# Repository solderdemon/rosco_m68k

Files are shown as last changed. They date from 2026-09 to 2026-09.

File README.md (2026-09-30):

# SolderDemon m68k

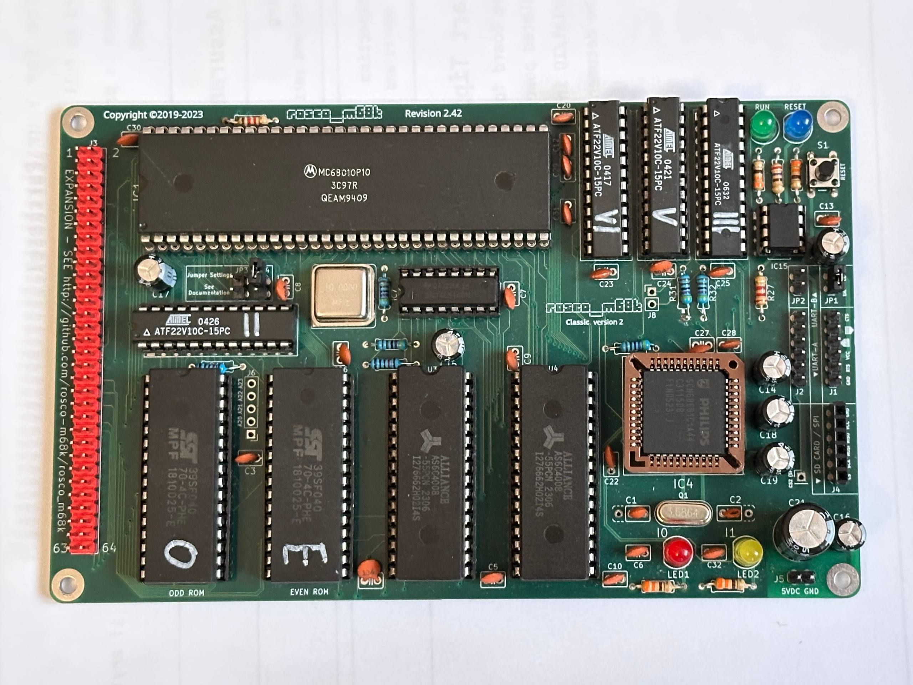
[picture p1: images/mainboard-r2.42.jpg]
Assembled rosco r2.42 mainboard, the GAL version SolderDemon m68k r1 grew from


SolderDemon develops a line of Motorola 68k computers built from **through-hole (THT) parts**. This repository holds its mainboard: the board design, firmware, software and CPLD code. Expansion boards such as the [busboard](https://github.com/solderdemon/solderdemon_m68k-busboard) plug into its J3 expansion connector.

The mainboard is built on [rosco_m68k](https://github.com/rosco-m68k/rosco_m68k) by Ross Bamford, The Really Old-School Company Limited, and contributors. SolderDemon boards carry their own revision numbers, starting at r1; the rosco r2.x numbers are the history they grew from. The photo above is the assembled rosco r2.42 board, the GAL version that r1 grew from.

## The board: r1

r1 is the next release and is not made yet. KiCad renders of it, top and bottom:

<p>
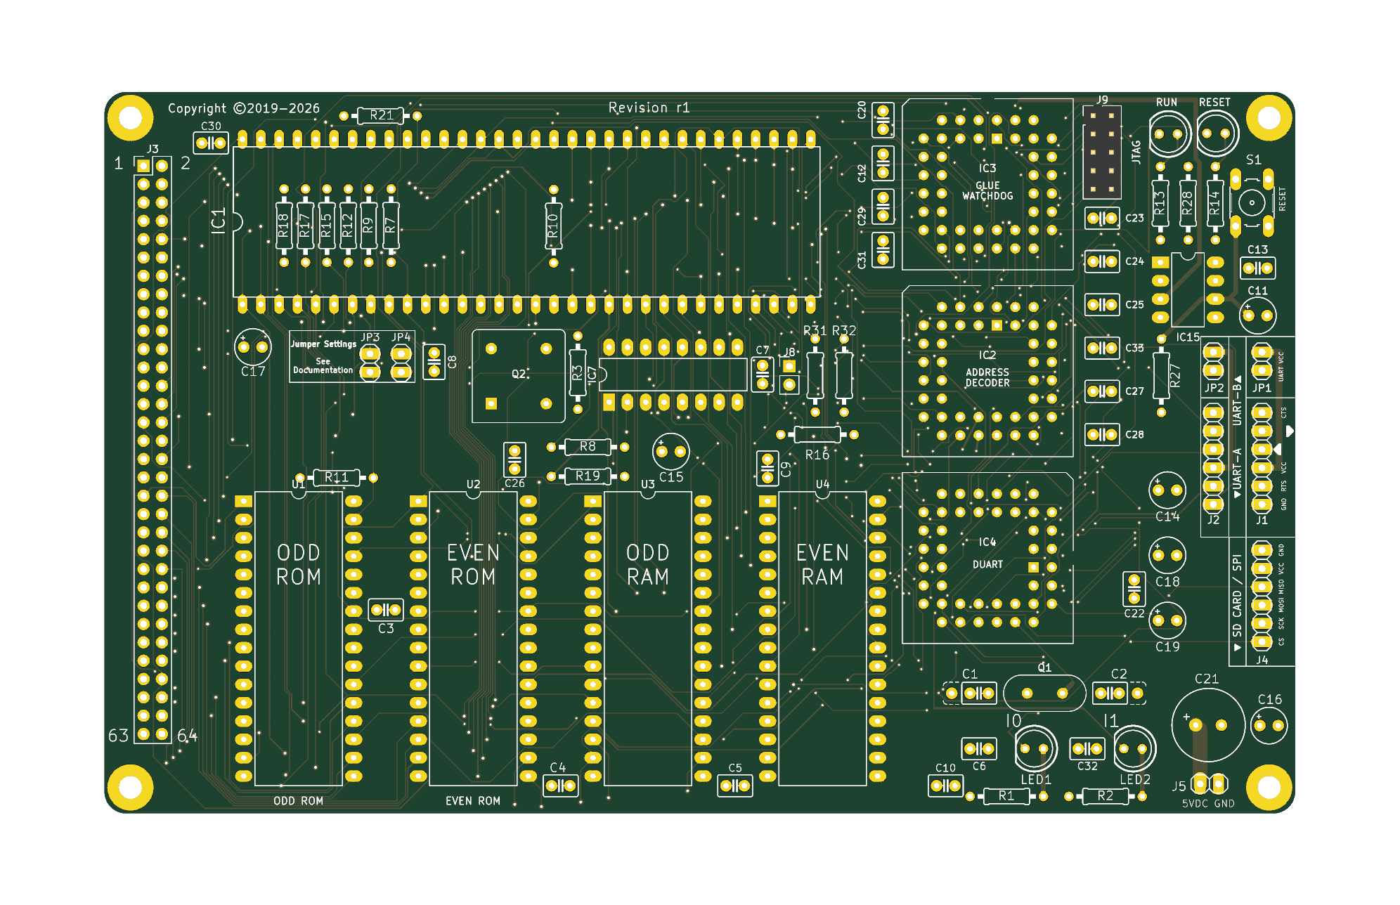
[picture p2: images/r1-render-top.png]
SolderDemon m68k r1, top side, KiCad render
  
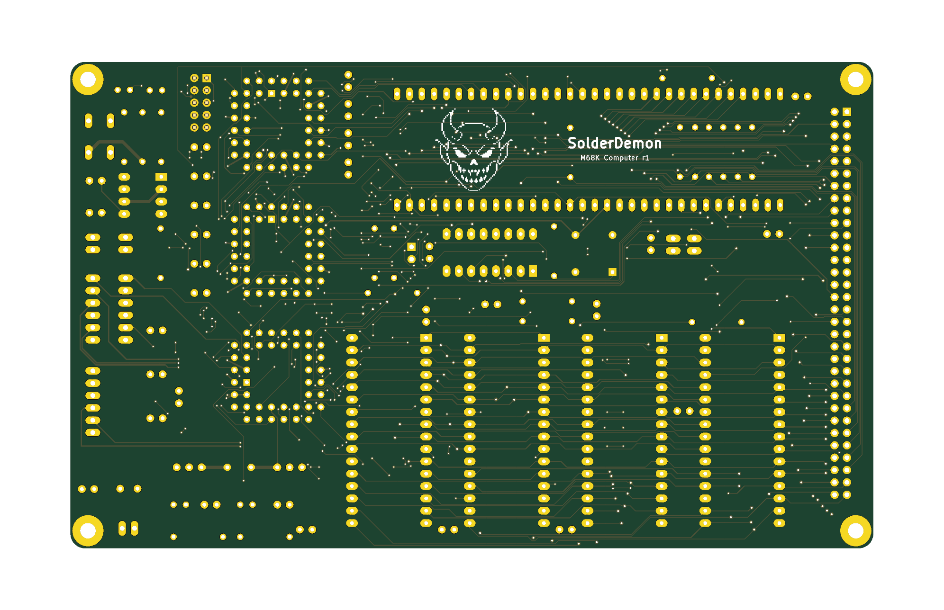
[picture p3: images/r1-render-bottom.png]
SolderDemon m68k r1, bottom side with the SolderDemon identity, KiCad render
  
</p>

| | |
| --- | --- |
| CPU | MC68010, 10 MHz |
| Memory | 1 MB Flash ROM (2 × SST39SF040), 1 MB SRAM (2 × AS6C4008) |
| Glue logic | 2 × ATF1502AS CPLD in PLCC-44 sockets, programmed in circuit over JTAG (J9) |
| I/O | XR68C681 DUART: two UARTs (J1, J2), SD card over SPI (J4) |
| Expansion | 64-pin J3 connector |
| PCB | 165 × 100 mm, 4 layers |

What changed from rosco r2.42 is in the [design notes](design/README.md).

## Find your way around

| What you need | Where to go |
| --- | --- |
| Board design | [design](design/README.md) |
| BOM, jumper settings, memory map, and expansion pinout | [docs](docs/README.md) |
| Firmware and ROM code | [code/firmware](code/firmware/) |
| PLD source and programming | [PLD guide](code/pld/README.md) |
| Software, libraries, and examples | [code/software](code/software/) |
| Recommended software workflow | [rosco CLI and Docker guide](docs/development.md) |
| Emulator for rosco_m68k and rosco_6502 | [SolderDemon rosco-emulator](https://github.com/solderdemon/rosco-emulator) |

## Develop software

For new programs, use [rosco CLI](https://github.com/solderdemon/rosco-cli) with its Docker build workflow. It creates the current starter project, builds through Docker, and can upload and monitor over UART. Follow the [quick start](docs/development.md).

## At the bench

- Start with the [hardware build guide](design/README.md) and [bill of materials](docs/BOM.md).
- Check [power and jumper settings](docs/JUMPERS.md) before applying power, particularly JP1/JP2 for FTDI power and JP3 for Flash writes.
- Use the [J3 expansion header pinout](docs/EXPANSION.md) for peripherals. J3 is the header; JP3 is a different, two-pin jumper.
- For code builds, see the [firmware and software overview](code/README.md). The [older SD card guide](docs/legacy-sd-card.md) covers earlier board revisions and is kept for code users.

<details>
<summary>Photos from the project's early prototypes</summary>

These images show early project prototypes, not the assembled r2.42 board shown above.

Early populated prototype
Early prototype PCBs

</details>

## Licences and attribution

Hardware design: [CERN Open Hardware Licence v1.2](LICENCE.hardware.txt). Software: [MIT](LICENSE) with [third-party notices](licenses/README.md). Documentation: [Creative Commons Attribution 4.0](licenses/LICENSE.docs). Original rosco_m68k design and documentation: Ross Bamford, The Really Old-School Company Limited, and contributors. See [upstream](https://github.com/rosco-m68k/rosco_m68k) for complete history and documentation.

**SolderDemon modification notice (2026-09-30):** SolderDemon m68k adapts the original rosco_m68k project, including a reworked through-hole mainboard (CPLDs instead of GALs, r1 layout and identity), the CPLD logic, and the build documentation. The original authorship and licence notices remain with the source files.

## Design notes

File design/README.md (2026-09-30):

# SolderDemon m68k through-hole mainboard design

Assembled r2.42 mainboard, the GAL version this board grew from

This directory contains the SolderDemon m68k through-hole mainboard design, derived from the original [rosco_m68k](https://github.com/rosco-m68k/rosco_m68k) board. Open the [KiCad project](kicad/solderdemon_m68k.kicad_pro) to inspect the board. The schematics are split into CPU, memory, CPLDs, DUART, reset, and expansion sheets. A [schematic PDF](kicad/solderdemon_m68k.pdf) is included for quick reading.

## Build references

1. Review the [bill of materials](../docs/BOM.md). Its source is the [KiCad CSV export](kicad/solderdemon_m68k.csv); confirm each footprint and package before ordering.
2. Read [jumper and power notes](../docs/JUMPERS.md) before applying power or connecting an SD card.
3. Use the [J3 expansion pinout](../docs/EXPANSION.md) when making an expansion board. **J3** is the expansion connector; **JP3** is the Flash write-enable jumper.
4. Check the KiCad PCB against [CAM outputs](CAMOutputs/) before fabrication. Regenerate Gerbers and drill files after any design change.

## Contents

- **kicad/**: editable schematic sheets, PCB, project, local symbols and footprints, CSV BOM export, and schematic PDF.
- **tools/**: the scripts that turn r2.13 into r1 (below).
- **CAMOutputs/**: Gerber layers and drill files.
- **docs/**: [BOM, jumper notes, and expansion pinout](../docs/README.md).

## r1: SolderDemon numbering, the DUART in the CPLD column

From here on the board carries its own revision numbers, starting at **r1**; the r2.x numbers
below are the rosco_m68k history it grew from.

r1 puts the three PLCC-44 sockets in one column: IC3 (glue), IC2 (decoder) and the DUART IC4
under them. IC4 used to sit 8 mm to the right, and moving it left would have put its pins on the
RAM U4, so the board is 5 mm longer instead (165 × 100 mm). `tools/r1_layout.py` stretches the
r2.42 board along a cut between the CPLDs and the CPU/RAM: everything right of the cut moves 5 mm
right, tracks crossing the cut get a horizontal bridge, so no clearance shrinks. IC4 then moves
into the column, its decoupling cap C22 into the space it left, and the DUART is routed again.
The upstream badges (WEEE bin, OSHW block, rosco_m68k logos, GitHub URL) are gone from the
silkscreen (`tools/strip_silk.py`). The CPU decoupling C20/C12/C29/C31 stands in an even column in the gap the stretch
opened, and the back carries the SolderDemon identity as on the busboard: the logo, the name and
"M68K Computer r1" (`tools/r1_identity.py`). All silkscreen text is in KiCad's own font; the
Futura that r2.x asked for is not installed and made KiCad stop at a message box.

## Revision 2.42: finished CPLD mainboard

r2.42 removes the J6 address/EXPSEL breakout and the J7 SPI CS2 breakout. Their unused copper
branches are pruned and the affected A1/FC2 routes are reconnected. Sixteen narrow VCC bridge
segments are widened from 0.2 to 0.3 mm. The board and all schematic title blocks carry revision
2.42; the crowded UART pin text and obsolete header labels are removed from the silkscreen.

## Revision 2.14: two ATF1502AS instead of four GALs

r2.14 replaces the four ATF22V10C GALs (IC2, IC3, IC5, IC6) with two ATF1502AS-10JU44 CPLDs in
through-hole PLCC-44 sockets, programmed in circuit through the JTAG header **J9**. The logic and
its check are described in [code/pld/cpld](../code/pld/cpld/README.md). Both sockets sit one above
the other where the three glue GALs stood; the old IC2 gap between the CPU and the ROMs is 24.4 mm
and a socket is 24.6 mm. J8, R31, R32 and R16 moved left to make room; the old GAL
decoupling C23-C25 and the DUART's C27/C28 now stand in one column under J9, and C33 is new.

r2.13 was drawn by hand, so r2.42 is an *edit* of it made by scripts, always starting
again from the r2.13 board in git. To rebuild it (KiCad 10, Docker for the fitter):

```sh
K="/c/Program Files/KiCad/10.0/bin"
./code/pld/cpld/build.sh                  # 1. *.pld -> bin/*.jed, pins checked against the source
python design/tools/verify_cpld.py        # 2. CPLDs against the r2.13 GAL fuse maps
python design/tools/cpld_sch.py           # 3. CPLDs sheet of the schematic, from the PIN lines
"$K/python.exe" design/tools/cpld_board.py   # 4. GALs out, sockets/J9/caps in, nets from the schematic
"$K/python.exe" design/tools/cpld_route.py   # 5. routing with KiCadRoutingTools, planes, cleanup
"$K/python.exe" design/tools/remove_access_headers.py # 6. remove J6/J7 and set revision 2.42
"$K/python.exe" design/tools/cpld_route.py --finish     # 7. prune obsolete header branches
"$K/python.exe" design/tools/repair_dangling.py        # 8. remove the remaining old stubs
"$K/python.exe" design/tools/cpld_route.py             # 9. reconnect affected nets
"$K/python.exe" design/tools/repair_dangling.py        # 10. repeat for residual stubs
"$K/python.exe" design/tools/cpld_route.py             # 11. finish the reconnection
"$K/python.exe" design/tools/polish_board.py           # 12. wider VCC bridges, clean silkscreen
"$K/python.exe" design/tools/brand_project.py          # 13. apply SolderDemon m68k project branding
python design/tools/strip_silk.py                      # 14. upstream badges off the silkscreen
"$K/python.exe" design/tools/r1_layout.py              # 15. r1: longer board, DUART into the column
"$K/python.exe" design/tools/cpld_route.py             # 16. route the DUART again
"$K/python.exe" design/tools/trim_stubs.py             # 17. cut router overshoots back to their junctions
python design/tools/make_logo.py 17                    # 18. SolderDemon logo footprint, as on the busboard
"$K/python.exe" design/tools/r1_identity.py            # 19. CPU decoupling column, SolderDemon identity on the back
"$K/python.exe" design/tools/cpld_route.py             # 20. route what the column tore up
"$K/python.exe" design/tools/trim_stubs.py             # 21. and trim again
"$K/kicad-cli.exe" pcb drc --schematic-parity design/kicad/solderdemon_m68k.kicad_pcb
```

Steps 5, 9 and 11 use [KiCadRoutingTools](https://github.com/drandyhaas/KiCadRoutingTools) from the
workspace's `tools/KiCadRoutingTools` (set `KRT` to use another clone); its logs go to
`design/kicad/routing/`. `design/tools/check_board.py` prints the DRC of any board with its
zones refilled.

The hardware design is licensed under [CERN OHL v1.2](../LICENCE.hardware.txt). The documentation is attributed in the [repository README](../README.md).

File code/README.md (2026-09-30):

# SolderDemon m68k firmware and software

This directory contains firmware and software programs for SolderDemon m68k. The
source retains the `rosco_m68k` firmware ABI and upstream build identifiers.

For new programs, start with the [rosco CLI and Docker guide](../docs/development.md). See the README.md files in the subdirectories for details.

| File/directory | Description |
|:---:|---|
| Toolchain.md | Host toolchain instructions for builds without Docker |
| shared | Shared code for both firmware and software |
| firmware | Firmware for the board (ROM code) |
| software | Software (system code & libraries, examples) |
| pld | [PLD sources and programming](pld/README.md) |
| starter_projects | Older starter examples; use rosco CLI init for new projects |

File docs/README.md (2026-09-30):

# SolderDemon m68k documentation

## Through-hole board

- [Parts and quantities](BOM.md): bill of materials from the KiCad CSV export.
- [Jumpers, power, and SD card](JUMPERS.md): JP1 through JP4 and the 5 V SD interface.
- [J3 expansion pinout](EXPANSION.md): 64-pin header signals and electrical notes.
- [Memory map](MEMORY-MAP.md): RAM, expansion, ROM, I/O, and firmware-reserved RAM.
- [Hardware design guide](../design/README.md): KiCad source, schematic PDF, and CAM files.

## Code

- [Recommended rosco CLI and Docker workflow](development.md)
- [Emulator workflow](development.md#emulate-the-board) for the SolderDemon m68k and rosco_6502 targets

- [Firmware and software overview](../code/README.md)
- [Firmware interface reference](../code/firmware/rosco_m68k_firmware/InterfaceReference.md)
- [Toolchain setup](../code/Toolchain.md)
- [PLD source and programming](../code/pld/README.md)
- [Legacy SD card guide](legacy-sd-card.md), written for older board revisions

These board notes are adapted from the original project documents. See the [repository README](../README.md) for attribution and licences.

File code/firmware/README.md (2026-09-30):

# SolderDemon m68k firmware

This directory contains the rosco_m68k firmware used by SolderDemon m68k.
Its source names and firmware interfaces retain the upstream `rosco_m68k` identifiers.

Depending on where we are in the development cycle, the development
firmware may also be present here (with a name like `rosco_m68k_development`).

Old firmware versions and other legacy, unsupported code can be 
found under the `attic` directory. This code is retained for 
historical interest only, and is not guaranteed to work (or even build!).

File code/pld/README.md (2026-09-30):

# PLD firmware

From board revision 2.14 the through-hole mainboard uses two **ATF1502AS-10JU44** CPLDs in PLCC-44
sockets. Their sources, build script and programming notes are in [cpld/](cpld/README.md):

| Board reference | Function | Source | Programming image |
| --- | --- | --- | --- |
| IC2 | Address decoder, DTACK, boot latch | [cpld/ic2_decoder.pld](cpld/ic2_decoder.pld) | `cpld/bin/ic2_decoder.jed` |
| IC3 | DUART select, reset glue, watchdog | [cpld/ic3_glue.pld](cpld/ic3_glue.pld) | `cpld/bin/ic3_glue.jed` |

The CPLDs are programmed in circuit over JTAG (header J9); a TL866/Minipro cannot program them.

## r2.13 and earlier: four ATF22V10C

Boards up to r2.13 use four **ATF22V10C** GALs. Their sources and images stay here, both for those
boards and as the reference `design/tools/verify_cpld.py` checks the CPLDs against:

| Board reference | Function | Source | Programming image |
| --- | --- | --- | --- |
| IC2 | Address decoder | [address_decoder/ic2_address_decoder.pld](address_decoder/ic2_address_decoder.pld) | [ic2_address_decoder.jed](address_decoder/ic2_address_decoder.jed) |
| IC3 | DUART select | [duartsel/ic3_duart_sel.pld](duartsel/ic3_duart_sel.pld) | [ic3_duart_sel.jed](duartsel/ic3_duart_sel.jed) |
| IC5 | Glue logic | [glue/ic5_glue_logic.pld](glue/ic5_glue_logic.pld) | [ic5_glue_logic.jed](glue/ic5_glue_logic.jed) |
| IC6 | Watchdog | [watchdog/ic6_watchdog.pld](watchdog/ic6_watchdog.pld) | [ic6_watchdog.jed](watchdog/ic6_watchdog.jed) |

The .pld files are GALasm sources. The .jed files are the images used by the burn scripts; .chp, .fus, and .pin are accompanying output reports. **A burn script writes its existing .jed file; it does not compile the .pld source.** Regenerate and check the programming image after changing source logic.

Each directory has a burn.sh script that invokes Minipro for an ATF22V10C(UES). Use a compatible programmer, confirm the target IC reference, and run the script **from its own directory** because the image path is relative. For example:

```sh
cd code/pld/address_decoder
bash burn.sh
```

Repeat from the corresponding directory for IC3, IC5, and IC6. The [toolchain notes](../Toolchain.md) include Minipro setup.

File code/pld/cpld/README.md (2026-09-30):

# rosco_m68k classic THT r2.14 glue logic: two ATF1502AS

Board revision 2.14 replaces the four ATF22V10C GALs of r2.13 (IC2 address decoder, IC3 DUART
select, IC5 general glue, IC6 watchdog) with two **ATF1502AS-10JU44** CPLDs in through-hole
PLCC-44 sockets, like the DUART IC4:

| Ref | Source | Does | Replaces |
|---|---|---|---|
| IC2 | [`ic2_decoder.pld`](ic2_decoder.pld) | address decode (RAM/ROM/IO/expansion), DTACK, WR, boot latch, ANYIACK | r2.13 IC2 + the boot counter and ANYIACK of IC5 |
| IC3 | [`ic3_glue.pld`](ic3_glue.pld) | DUART /CS and /IACK, RESET/HALT, RUN LED, bus-error watchdog | r2.13 IC3 + IC6 + the rest of IC5 |

The equations are those of the r2.13 GALs, unchanged, and every board net keeps its name and
level. BOOT and ANYIACK, which ran between the GALs, are internal to IC2 now (ANYIACK is decoded
in IC3 as well, for the watchdog and DUART IACK), so no wire runs between IC2 and IC3. IC2 uses
24 pins and 16 macrocells, IC3 31 pins and 21 macrocells.

## Building

```sh
./build.sh
```

It needs a running Docker: it uses the `dinoboards/cpld-toolchain` image (WinCUPL plus the
Atmel `find1502` fitter, see `tools/cpld-toolchain` in the workspace), writes `bin/*.jed`, and
fails if the fitter moved any pin away from where the `.pld` puts it -- the board is routed to
those pins.

## Checking the logic

```sh
python design/tools/verify_cpld.py [steps] [seed]
```

runs the r2.13 GALs from their real JEDEC fuse maps (`../address_decoder`, `../duartsel`,
`../glue`, `../watchdog`) and the r2.14 CPLDs from these sources side by side on random bus
traffic and fails on the first net that differs -- all 14 driven nets, the open-drain ones
resolved as wired-AND with the CPU pulling RESET/HALT as well. The stimulus makes the boot latch
set and the watchdog fire, and the run fails if either never happens.

## Programming

The ATF1502AS is programmed in circuit over JTAG; the TL866/minipro cannot program it. Header J9
has the Altera/Atmel 10-pin layout (1 TCK, 2 GND, 3 TDO, 4 VCC, 5 TMS, 9 TDI, 10 GND) and the
two chips are chained TDI -> IC2 -> IC3 -> TDO, so IC2 is the first device in the chain. Use an
Atmel ATDH1150USB with ATMISP, or any FT232H/FT2232H adapter with OpenOCD (convert the `.jed` to
SVF first). The board must be powered while programming.

Both designs keep JTAG enabled (`JTAG = ON`) with the internal pull-ups on TDI and TMS. Do not
turn JTAG off: the chip can then only be recovered with a high-voltage programmer.

## Pinout

The `PIN` lines in the `.pld` files are the only place the pinout is written down;
`design/tools/cpld_sch.py` and `cpld_board.py` read them. They were chosen by
`cpld_board.py --suggest`, which puts each signal on the pin nearest to where its net already
runs on the board. To move a pin: edit the `.pld`, run `./build.sh`, `verify_cpld.py`, then
`cpld_sch.py`, `cpld_board.py` and `cpld_route.py` (see [design/README.md](../../../design/README.md)).

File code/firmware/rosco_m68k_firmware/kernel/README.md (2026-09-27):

## ROM kernel for rosco_m68k

The test target builds `units.bin` with the host cross-toolchain and runs it
in the [SolderDemon rosco-emulator](https://github.com/solderdemon/rosco-emulator)
Docker image. Keep Docker running; the test checks that the suite reports
`0 failed`. You can also upload the binary to a board if desired.

```shell
make clean test
```

The kernel itself is built as part of the main ROM build, but you
can build just the static library in this directory if you want:

```shell
make clean all
```

You can change the defines in the Makefile to see more debugging info:

* `-DDEBUG_PMM` - See memory manager debugging output (noisy)
* `-DDEBUG_SCHED` - See scheduler debugging output (noisy)
    * `-DTRACE_SCHED` - See scheduler trace output (very noisy)
* `-DEEBUG_INTEN` - Debug interrupt enable / disable (extremely noisy)

### Memory Management

Obviously with no MMU there is no virtual memory, and no memory protection.
The kernel implements two interfaces for memory managament - an optimised
low-overhead free-list based coalescing first-fit physical allocator with 
a block size of 1KiB, and a simple bitmap-based slab allocator layered
on top, which automatically manages 1KiB slabs, with a fixed block size
of 32-bytes.

The slab allocator is primarily intended for system structures, and does
support allocation/free of multiple contiguous blocks from a given slab
where a struct needs more than 32-bytes.

The intention is that user code would directly use neither of these - 
instead, the physical allocator would supply blocks that would then be
managed by some library `malloc` implementation. 

They are both exposed via the `IKernel` API, however, so can be used.

In order for everything to work nicely, all memory management must 
(ultimately) go through the pmm, or the system won't be able to track
what memory is in use vs not, and sadness will most likely ensue.

### Scheduling

The scheduler here is a pre-emptive, priority-based round robin, with four
priority levels (0 = lowest, 3 = highest).

The scheduler is run once per quantum, driven from the 100Hz system timer,
so it'll run 100 times per second, adjusted by the divisor in the 
`QUANTUM_TICKS` variable in `task.asm`. We'll want to play around with
this to find a value that works well in the general case (and can make 
it configurable if we like). 

In testing so far the scheduler is quite capable of 100 switches a second,
without swamping the system - however, it might not be best for performance,
we might want to take a (small) hit on latency to trade off for raw perf.

Obviously once interrupt sources and devices are implemented, that'll also 
change the complexion of that tradeoff - so we can revisit regularly 
as dev progresses.

The priority rules are:

* A runnable process of a given priority will only be given time if no 
  higher-priority process is runnable
* A newly-scheduled process will **never** preempt the scheduling process
* A newly-scheduled process will **always** be scheduled next, _within_
  _it's priority group_
* Where a newly-scheduled process has the same priority, or higher priority
  than the scheduling process, it will **always** run on the next schedule
* A sleeping process, when woken, will **always** preempt the running 
  process _on the next timeslice_, _if it has the same or higher priority_.

### Initialisation

To initialize the kernel, you'll need to call a few things. This is the 
recommended order for doing so:

```c
    /* Initialise the API pointers */
    api_init();
    Kernel = get_kernel_api();

    /* Initialise the PMM. The free should be changed to cover your chosen managed memory region */
    pmm_init();
    pmm_free(0x20000, 0x30000);
    
    /* Initalise the slab allocator */
    slab_init();
    
    /* Initialise IRQs */
    irq_init();

    /* Initialise the multitasking system */
    task_init();

    /* Start the multitasking system. This never returns */
    start_tasking(tinit_stack, SYS_STACK_SIZE, init, tidle_stack, SYS_STACK_SIZE, idle);
```

To set up tasks, the following general pattern is recommended:

```c
    Task* t1 = (Task*)Kernel->alloc_sys_object(TASK_SLAB_BLOCKS);
    uint32_t t1_stack = Kernel->mem_alloc(USER_STACK_SIZE);    

    if (t1 == NULL || t1_stack == 0) {
        syncprintf("  ==! Failed to allocate memory for task\n");
        halt_and_catch_fire();
    }

    Kernel->task_init(t1, 0x01, TASK_1_PRIORITY);
```

This would later be scheduled (e.g. by your `init` task):

```c
    Kernel->task_schedule(t1, t1_stack, USER_STACK_SIZE, task1_function);
```

### Kernel API

All access to the Kernel API should be done through an `IKernel` pointer,
which can be obtained with the `get_kernel_api` function in `kernelapi.h`.

This provides the following functions. Take note of those marked as 
"not interrupt safe" - these **must** not be called from interrupt context!

You can find (a bit) more detail about the functions in the respective 
header files (under `include`).

#### Physical Memory Management
* `Kernel->mem_alloc(uintptr_t size)` - Allocate 1KiB "pages" to cover `size` bytes
* `Kernel->mem_free(uintptr_t addr, uintptr_t size)` - Free 1KiB "pages" to cover `size` bytes

#### Slab Memory Management

* `Kernel->alloc_sys_object(uint8_t block_count)` - Allocate up to 31 blocks (32bytes each)
* `Kernel->free_sys_object(void* addr, uint8_t block_count)` - Free slabs starting at at `addr`

#### Multitasking

* `Kernel->task_current()` - Obtain a pointer to the currently-running `Task*`
* `Kernel->task_init(Task *task, tid_t tid, priority_t priority)` - Initialise a new task struct
  * This **must** be called on new `Task*` structs before they are used!
  * If allocating task structs, be aware they need two slab blocks!
* `Kernel->task_schedule(Task *task, uintptr_t stack_addr, size_t stack_size, task_handler_f entrypoint)` - Schedule a task to run (next, within its priority level)
* `Kernel->task_wait(uint32_t sig_mask)` - Suspend the current task until another task sends one of the specified signals
  * **Not interrupt safe**
  * Currently, does not unblock if the task is _already_ signalled - this is prone to race conditions and will likely be changed
* `Kernel->task_signal(Task *task, uint32_t sig_mask)` - Signal the given task with the specified signals
  * Does **not** immediately wake the task - it is just scheduled next _within it's priority level_.
  * For this reason, high-priority signalling (e.g. for interrupt handling) should be done in high-priority tasks

#### Interrupt Handling

* `Kernel->enable_interrupts()` - Enable interrupts
  * This is re-entrant, a counter of disables is kept, and only when this is zero are interrupts actually enabled
* `Kernel->disable_interrupts()` - Disable interrupts
  * This is re-entrant, a counter of disables is kept, and used by `enable_interrupts`
* `Kernel->register_irq(uint8_t vec, IrqHandler *handler)` - Register an IRQ chain handler for the given vector
* `Kernel->remove_irq(IrqHandler *handler)` - Remove the specified IRQ chain handler

#### Utilities

Despite being quite strict about being a microkernel, the API _does_ include some utility functions where the
Kernel can usefully export efficient functions for working with kernel structures. 

These may also be useful in your own code.

* `Kernel->list_init(List* the_list)` - Initialize a kernel doubly-linked list
* `Kernel->list_add_head(List* target, ListNode *subject)` - Add the specified node at the head of the list
* `Kernel->list_delete_head(List* target)` - Delete (and return) the head node from the list
* `Kernel->list_add_tail(List* target, ListNode *subject)` - Add the specified node at the tail of the list
* `Kernel->list_delete_tail(List* target)` - Delete (and return) the head node from the list
* `Kernel->list_insert_after(ListNode *target, ListNode *subject)` - Insert the specified subject node after the specified target node
* `Kernel->list_delete(ListNode *subject)` - Delete the specified node from the list that contains it

### Legal Mumbo-Jumbo

**Copyright 2023 Ross Bamford & Contributors**
MIT License

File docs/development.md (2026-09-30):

# Develop SolderDemon m68k software with rosco CLI

[rosco CLI](https://github.com/solderdemon/rosco-cli) is the recommended way to create, build, upload, and monitor SolderDemon m68k programs. It keeps the build and serial workflow in one command-line tool. Select its compatible `rosco_m68k` board target in the commands below.

## Start a new project

Install rosco CLI using the instructions in its [README](https://github.com/solderdemon/rosco-cli#install-from-this-checkout), then create a new C project:

```sh
rosco init hello --board rosco_m68k --language c --docker --target hardware --yes
cd hello
rosco doctor
rosco build
```

Use `--language asm` for an assembly project. The CLI creates the current starter files itself, so there is no need to copy this repository's older `code/starter_projects` directories into a new project.

The generated project records Docker as its build toolchain. Docker must be installed and running. On ARM hosts, the [CLI documentation](https://github.com/solderdemon/rosco-cli#configuration) describes setting `build.docker.platform = "linux/amd64"` if the image requires emulation.

## Run on the board

Connect the USB serial adapter and run:

```sh
rosco run
```

`rosco run` automatically selects the USB-UART port when there is one matching device. It builds, uploads through Kermit, and monitors UART output. If discovery cannot choose a port, run `rosco ports` to list USB-UART candidates (or `rosco ports --all` for other serial ports), then pass the correct port explicitly with `rosco run --port <port>`. See the [CLI README](https://github.com/solderdemon/rosco-cli#typical-workflow) for separate build, upload, and monitor commands.

## Emulate the board

The separate [SolderDemon rosco-emulator](https://github.com/solderdemon/rosco-emulator) supports both rosco_m68k and rosco_6502. rosco CLI can create a project that runs in the emulator through Docker:

```sh
rosco init hello --board rosco_m68k --language c --docker --target emulator --emulator-docker --yes
cd hello
rosco run
```

For a rosco_6502 project, choose `--board rosco_6502`. The emulator also has its own [Docker image and usage instructions](https://github.com/solderdemon/rosco-emulator#docker).

## Existing projects and host builds

From an existing compatible software project, `rosco build --docker` selects the Docker toolchain for that run. The older [host toolchain instructions](../code/Toolchain.md) remain available if you deliberately build without Docker. The older [starter projects](../code/starter_projects/README.md) are retained as examples; use `rosco init` for a fresh project.

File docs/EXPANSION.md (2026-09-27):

# J3 expansion header pinout

> This pinout describes the **J3 expansion connector**. Check the schematic before using it with another board revision. **JP3 is a separate Flash write-enable jumper**, not this connector.

J3 provides peripheral access to the full address, data and control buses in the system,
plus VCC (5V) and GND. These signals are unbuffered and have no built-in protection, so are
not suitable for direct use as a bus, but could be made so with a relatively simple
expansion-to-bus conversion board.

Many of the MC68010 lines are tri-state when used in conjunction with the bus-mastering support.

It should be noted that most of these signals have very low output current capabilities,
and should not be used to directly drive e.g. LEDs. If LEDs are to be driven, then either
a transistor must be used, or the circuit set up such that the pins sink current.

In all cases, see the datasheets for the relevant IC driving a given line (including the MC68010, XR68C681, and GAL devices, depending on the signal) for the absolute maximum ratings.

The absolute maximum current draw on the VCC line is 1A. Recommended maximum is 500mA.
The board _may_ be able to supply more than this, but as power supplies are so variable
you should take care if drawing more than this from this pin. A better solution should
you need might be to separately power your peripheral from the supply and share common ground.

| Pin | Signal | Description | Active | I/O |
|-----|---|---|---|-----|
| 1 | A1 | MC68010 Address line 1 | High | O |
| 2 | VCC | +5V (500mA recommended max) | N/A | O |
| 3 | A2 | MC68010 Address line 2 | High | O |
| 4 | CLK | Main system clock (10MHz, 50% duty cycle) | N/A | O |
| 5 | A3 | MC68010 Address line 3 | High | O |
| 6 | GND | Ground | N/A | O |
| 7 | A4 | MC68010 Address line 4 | High | O |
| 8 | VPA | MC68010 Legacy peripheral VPA (*5)(6*) | Low | I |
| 9 | A5 | MC68010 Address line 5 | High | O |
| 10  | E | MC68010 Legacy peripheral E (*5) | Low | O |
| 11  | A6 | MC68010 Address line 6 | High | O |
| 12  | VMA | MC68010 Legacy peripheral VMA (*5) | Low | O |
| 13  | A7 | MC68010 Address line 7 | High | O |
| 14  | IRQ3 | IRQ3 line (*3) | Low | I |
| 15  | A8 | MC68010 Address line 8 | High | O |
| 16  | IOS | IOSEL line from decoder (*1) | Low | O |
| 17  | A9 | MC68010 Address line 9 | High | O |
| 18  | EXPS | EXPSEL line from decoder (*1) | Low | O |
| 19  | A10 | MC68010 Address line 10 | High | O |
| 20  | FC0 | MC68010 Function Code 0 (*2) | High | O |
| 21  | A11 | MC68010 Address line 11 | High | O |
| 22  | FC1 | MC68010 Function Code 1 (*2) | High | O |
| 23  | A12 | MC68010 Address line 12 | High | O |
| 24  | FC2 | MC68010 Function Code 2 (*2) | High | O |
| 25  | A13 | MC68010 Address line 13 | High | O |
| 26  | IPL0 | IRQ5 line (*3) | Low | I |
| 27  | A14 | MC68010 Address line 14 | High | O |
| 28  | IPL1 | IRQ2 Line (*3) | Low | I |
| 29  | A15 | MC68010 Address line 15 | High | O |
| 30  | IPL2 | IRQ6 Line (*3) | Low | I |
| 31  | A16 | MC68010 Address line 16 | High | O |
| 32  | LDS | MC68010 Lower Data Strobe | Low | O |
| 33  | A17 | MC68010 Address line 17 | High | O |
| 34  | UDS | MC68010 Upper Data Strobe | Low | O |
| 35  | A18 | MC68010 Address line 18 | High | O |
| 36  | RESET  | System Reset (4*) | Low | I/O |
| 37  | A19 | MC68010 Address line 19 | High | O |
| 38  | D15 | MC68010 Data line 15 | High | I/O |
| 39  | A20 | MC68010 Address line 20 | High | O |
| 40  | D14 | MC68010 Data line 14 | High | I/O |
| 41  | A21 | MC68010 Address line 21 | High | O |
| 42  | D13 | MC68010 Data line 13 | High | I/O |
| 43  | A22 | MC68010 Address line 22 | High | O |
| 44  | D12 | MC68010 Data line 12 | High | I/O |
| 45  | A23 | MC68010 Address line 23 | High | O |
| 46  | D11 | MC68010 Data line 11 | High | I/O |
| 47  | AS | MC68010 Address Strobe | Low | O |
| 48  | D10 | MC68010 Data line 10 | High | I/O |
| 49  | BERR | MC68010 Bus Error | Low | I |
| 50  | D9 | MC68010 Data line 9 | High | I/O |
| 51  | BG | MC68010 Bus Grant | Low | O |
| 52  | D8 | MC68010 Data line 8 | High | I/O |
| 53  | BGACK  | MC68010 Bus Grant Acknowledge | Low | I |
| 54  | D7 | MC68010 Data line 7 | High | I/O |
| 55  | BR | MC68010 Bus Request | Low | I |
| 56  | D6 | MC68010 Data line 6 | High | I/O |
| 57  | DTACK  | MC68010 Data Transfer Acknowledge | Low | I |
| 58  | D5 | MC68010 Data line 5 | High | I/O |
| 59  | R/W | MC68010 Read/Not Write | N/A | O |
| 60  | D4 | MC68010 Data line 4 | High | I/O |
| 61  | D0 | MC68010 Data line 0 | High | I/O |
| 62  | D3 | MC68010 Data line 3 | High | I/O |
| 63  | D1 | MC68010 Data line 1 | High | I/O |
| 64  | D2 | MC68010 Data line 2 | High | I/O |

 ## Signal notes

 1. If used to drive LEDs, the circuit should be configured such that these pins sink current.
 2. If all three function code pins are high the CPU is asserting IACK.
 3. Active low, open-collector IRQ lines for peripherals (4K7 pullups included, do not add more).
 4. Wire-or, open-collector. Pullup is already provided.
 5. See MC68010 user manual. Using these lines alters bus cycle timing.
 6. This line has a built-in 10k pull-up.

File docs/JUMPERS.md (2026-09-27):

# Jumpers, power, and SD card

These notes are adapted from the original *Classic v2 Additional Information* sheet for the through-hole mainboard. Confirm jumper positions against the [schematic](../design/kicad/rosco_m68k.pdf) and board silkscreen before applying power.

| Jumper | Closed | Normal use |
| --- | --- | --- |
| JP1 / JP2 | Allows power from the corresponding FTDI serial module | Leave both open when using the board's external power input. Close **only one** when deliberately powering through an FTDI module. |
| JP3 | Enables hardware writing to the Flash ROMs | Leave open unless running a Flash update. |
| JP4 | Changes expansion RAM behaviour for the original rosco_m68k memory expansion board | Leave open for other configurations. |

## Power through FTDI

Never close JP1 and JP2 together. Do not connect external power while either FTDI power jumper is closed. The original R2 notice states the mainboard alone requires **at least 500 mA**; check that the host and FTDI module can supply the complete build.

## SD card header

The SPI SD card header uses **5 V** signals. Use an Arduino-compatible SD card adapter with built-in **5 V to 3.3 V level conversion**. Do not connect a bare 3.3 V SD card directly.

## Expansion power

The J3 expansion connector exposes 5 V and ground. The original [J3 pinout](EXPANSION.md) recommends drawing no more than **500 mA** from its 5 V pin, with **1 A** stated as an absolute maximum. Account for the complete board's power supply and use a shared ground if powering a peripheral separately.

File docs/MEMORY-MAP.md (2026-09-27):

# Memory map

This is the physical 24-bit address map of the through-hole mainboard after startup. The [address decoder PLD](../code/pld/address_decoder/ic2_address_decoder.pld) defines the board-level regions; the [firmware linker script](../code/firmware/rosco_m68k_firmware/rosco_m68k_firmware_1M.ld) and [program linker script](../code/software/libs/src/start_serial/link_scripts/hugerom_rosco_m68k_program.ld) use the same boundaries.

| Address range | Size | Use |
| --- | ---: | --- |
| `0x000000`–`0x0FFFFF` | 1 MiB | Onboard RAM |
| `0x100000`–`0xDFFFFF` | 13 MiB | Expansion address space; memory or devices depend on the attached hardware |
| `0xE00000`–`0xEFFFFF` | 1 MiB | Onboard ROM / Flash |
| `0xF00000`–`0xFFFFFF` | 1 MiB | I/O address space |

At reset, the address decoder temporarily selects ROM at low addresses so the CPU can fetch its initial vectors. After the startup cycles, RAM occupies `0x000000`–`0x0FFFFF`. The ROM image and firmware revision word are linked at `0xE00000` and `0xE00400` respectively. The DUART is addressed at odd byte addresses starting at `0xF00001`; see the [firmware register definitions](../code/firmware/rosco_m68k_firmware/include/machine.h). The I/O region is a decode window, not a promise that every address in it has a device.

## Low RAM used by firmware

The firmware reserves the first `0x2000` bytes for vectors and system data. The ranges below come from the [firmware interface reference](../code/firmware/rosco_m68k_firmware/InterfaceReference.md#2-system-data-area-memory-map).

| Address range | Use |
| --- | --- |
| `0x000000`–`0x0003FF` | Exception vectors |
| `0x000400`–`0x00041F` | System Data Block (SDB), including RAM size and UART base |
| `0x000420`–`0x0004FF` | Firmware function pointer table |
| `0x000500`–`0x00117F` | Video I/O data area |
| `0x001180`–`0x0017FF` | Firmware internal reserved area |
| `0x001800`–`0x001FFF` | Firmware BSS |

The standard program linker script begins its run area at `0x002000`. It also uses `0x040000` as a load address, so use the linker script for a program's actual layout instead of treating all higher RAM as free. For individual SDB fields and firmware calls, use the [full interface reference](../code/firmware/rosco_m68k_firmware/InterfaceReference.md).

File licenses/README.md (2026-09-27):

# Licences and attribution

The main software licence is [MIT](../LICENSE). Hardware design files use the [CERN Open Hardware Licence v1.2](../LICENCE.hardware.txt). Repository documentation uses [Creative Commons Attribution 4.0](LICENSE.docs).

The retained third-party notices are grouped here:

| Notice | Included material |
| --- | --- |
| [COPYING.NEWLIB](COPYING.NEWLIB) | Newlib-derived components and related code |
| [LICENCE.adventure](LICENCE.adventure) | Adventure port under code/software/adventure |
| [LICENSE.kermit](LICENSE.kermit) | Embedded Kermit code |
| [LICENSE.shmall](LICENSE.shmall) | Shmall allocator code |

Keep these notices with the corresponding source when redistributing it. The Musashi notice was removed with the bundled r68k emulator source.

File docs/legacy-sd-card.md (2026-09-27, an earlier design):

# Legacy SD card hookup and user guide

> This guide describes firmware 1.3 and earlier board revisions (R1/R1.2/R1.23). For Classic R2 electrical notes, see [R2 jumpers and SD card](JUMPERS.md).

With Firmware 1.3, SD Cards are now supported directly by the firmware. This feature works will all boards that are supported by Firmware 1.3, though the electrical hookup and usage varies.

In order to use SD card, you will need an Arduino SD Card adapter. It is very important that this adapter includes level conversion (as SD cards are 3.3V) - any adapter marked as suitable for Arduino _should_ work, but for completeness ensure it has the regulator and level-conversion chip (as in the diagram below).

## Electrical connection

To connect your SD adapter to your rosco_m68k, you will use some of the GPIO pins (on `J5`) for r1 and r1.2 boards, or the dedicated SD card connector (`J4`) on r1.23 boards. The hookup is as shown below:

SD Card Hookup

The SD adapter should be connected with the rosco_m68k powered off. Ensure all connections are correct before connecting power to the mainboard. Once the adapter is connected, you can insert and remove SD cards without needing to power off or reboot your rosco_m68k.

## Supported SD cards

Most SD cards will work fine in a read-only system, however for best performance and reliability (especially during writes) we recommend good quality SDHC cards with capacity 16 or 32GB. The interface has been fairly extensively tested with SanDisk, Samsung, and similar brands in SDHC capacity.

## SD Card format

In order to work with the standard rosco_m68k software (both the firmware bootloader, where available, and Xark's [sdfat_menu](../code/software/sdfat_menu)) your SD card should be formatted as FAT. You can do this on a desktop computer - specifics vary by platform.

FAT32 is recommended (and more completely tested). VFAT is known to be unsupported at this time.

### sdfat_menu

Xark's [sdfat_menu](../code/software/sdfat_menu) is the official loader for SD cards, and is the recommended way to interface with your SD card. Whether by direct booting with `BIGROM`s (see below) or by sending the menu program via Kermit before using SD features, the menu provides a comprehensive text interface for selecting binaries to load and run, and also provides a command-shell, directory navigation, and more.

### Bootable SD

If you have the `BIGROM` build of Firmware 1.3, your rosco_m68k will look for an SD card at boot time (before falling back to Kermit). If one is found, it will attempt to load a file called `ROSCODE1.BIN` from the SD card and boot it directly.

It is recommended that, where this capability exists, you use Xark's [sdfat_menu](../code/software/sdfat_menu) (see above).

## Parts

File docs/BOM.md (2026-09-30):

# SolderDemon m68k bill of materials

This table is transcribed from the KiCad CSV export at [solderdemon_m68k.csv](../design/kicad/solderdemon_m68k.csv). It has **30 part lines and 82 component placements**. It is a design BOM, not a verified purchasing list; check the schematic, PCB footprints, and desired assembly options before ordering.

| Qty | References | Value / part | KiCad footprint |
| ---: | --- | --- | --- |
| 1 | S1 | 10-XX | B3F-10XX |
| 2 | R19,R11 | 10K | 0207_10 |
| 2 | C1,C2 | 7pF | C2.5_or_3.5-3 |
| 23 | C7,C8,C9,C20,C23,C24,C22,C26,C13,C27,C28,C30,C31,C6,C25,C29,C12,C10,C5,C4,C3,C32,C33 | 100nF | C2.5-3 |
| 7 | C16,C17,C18,C19,C14,C15,C11 | 100uF | E2,5-5 |
| 1 | C21 | 470uF | E3,5-10 |
| 1 | IC4 | XR68C681CJTR-F | PLCC-44_THT-Socket |
| 2 | IC3,IC2 | ATF1502AS-10JU44 | PLCC-44_THT-Socket |
| 4 | JP1,JP2,JP3,JP4 | Jumper | 1X02 |
| 2 | LED3,LED1 | GREEN | LED5MM |
| 2 | LED4,LED2 | RED | LED5MM |
| 1 | Q1 | 3.6864MHz | Crystal_HC49-4H_Vertical |
| 1 | Q2 | 5H8ET-10.000 | Oscillator_DIP-8 |
| 2 | U4,U3 | AS6C4008-55PCN | DIP-32_W15.24mm_LongPads |
| 2 | U2,U1 | SST39SF040 | DIP-32_W15.24mm_LongPads |
| 1 | J3 | Conn_02x32_Odd_Even | PinHeader_2x32_P2.54mm_Vertical |
| 12 | R8,R7,R9,R10,R32,R31,R12,R15,R17,R18,R3,R16 | 4K7 | 0207_10 |
| 1 | J4 | Conn_01x06 | 1X06 |
| 1 | J2 | UART_B | 1X06 |
| 1 | J1 | UART_A | 1X06 |
| 1 | J5 | PWR | 1X02 |
| 1 | IC15 | 555N | DIP-8_W7.62mm_LongPads |
| 1 | R27 | 2K2 | 0207_10 |
| 1 | R28 | 270R | 0207_10 |
| 4 | R13,R14,R1,R2 | 330R | 0207_10 |
| 1 | R21 | 1K2 | 0207_10 |
| 1 | IC7 | 74LS148 | DIP-16_W7.62mm_LongPads |
| 1 | J8 | Conn_01x02_Male | PinHeader_1x02_P2.54mm_Vertical |
| 1 | IC1 | MC68010P10 | DIL64 |
| 1 | J9 | JTAG (2x5 header) | PinHeader_2x05_P2.54mm_Vertical |

## Items outside the component count

- The CSV also contains **four M3 mounting holes** and **six logo or compliance artwork objects**. They are PCB features, not parts to buy.
- The bare PCB and any required programming of the ATF1502AS CPLDs (in circuit, over JTAG header J9) and Flash ROMs are not included as BOM lines. See the [PLD programming guide](../code/pld/README.md) for IC2 and IC3. Boards up to r2.13 use four ATF22V10C GALs (IC2, IC3, IC5, IC6) instead.
- The original R2 packing list separately mentioned sockets for IC1 (DIL64, 1), IC4 (PLCC44, 1), IC7 (DIL16, 1), IC15 (DIL08, 1), and U1/U2/U3/U4 (DIL32, 4). From r2.14 IC2 and IC3 also sit in PLCC-44 through-hole sockets (2 more PLCC44 sockets). Treat these as assembly choices and verify fit against the PCB.
- The older packing list differs from this KiCad CSV for some headers (including J8). This table follows the CSV; inspect the current PCB before ordering those headers.

The source CSV has no supplier or manufacturer part numbers. Package names in this table are KiCad footprint identifiers, not vendor order codes.

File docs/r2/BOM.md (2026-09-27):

# R2 bill of materials

This table is transcribed from the KiCad CSV export at [kicad/rosco_m68k.csv](../../design/r2/kicad/rosco_m68k.csv). It has **31 part lines and 84 component placements**. It is a design BOM, not a verified purchasing list; check the schematic, PCB footprints, and desired assembly options before ordering.

| Qty | References | Value / part | KiCad footprint |
| ---: | --- | --- | --- |
| 1 | S1 | 10-XX | B3F-10XX |
| 2 | R19,R11 | 10K | 0207_10 |
| 2 | C1,C2 | 7pF | C2.5_or_3.5-3 |
| 22 | C7,C8,C9,C20,C23,C24,C22,C26,C13,C27,C28,C30,C31,C6,C25,C29,C12,C10,C5,C4,C3,C32 | 100nF | C2.5-3 |
| 7 | C16,C17,C18,C19,C14,C15,C11 | 100uF | E2,5-5 |
| 1 | C21 | 470uF | E3,5-10 |
| 1 | IC4 | XR68C681CJTR-F | PLCC-44_THT-Socket |
| 4 | IC5,IC6,IC3,IC2 | ATF22V10C | DIP-24_W7.62mm_Socket_LongPads |
| 4 | JP1,JP2,JP3,JP4 | Jumper | 1X02 |
| 2 | LED3,LED1 | GREEN | LED5MM |
| 2 | LED4,LED2 | RED | LED5MM |
| 1 | Q1 | 3.6864MHz | Crystal_HC49-4H_Vertical |
| 1 | Q2 | 5H8ET-10.000 | Oscillator_DIP-8 |
| 2 | U4,U3 | AS6C4008-55PCN | DIP-32_W15.24mm_LongPads |
| 2 | U2,U1 | SST39SF040 | DIP-32_W15.24mm_LongPads |
| 1 | J3 | Conn_02x32_Odd_Even | PinHeader_2x32_P2.54mm_Vertical |
| 12 | R8,R7,R9,R10,R32,R31,R12,R15,R17,R18,R3,R16 | 4K7 | 0207_10 |
| 1 | J4 | Conn_01x06 | 1X06 |
| 1 | J2 | UART_B | 1X06 |
| 1 | J1 | UART_A | 1X06 |
| 1 | J5 | PWR | 1X02 |
| 1 | IC15 | 555N | DIP-8_W7.62mm_LongPads |
| 1 | R27 | 2K2 | 0207_10 |
| 1 | R28 | 270R | 0207_10 |
| 4 | R13,R14,R1,R2 | 330R | 0207_10 |
| 1 | R21 | 1K2 | 0207_10 |
| 1 | J6 | Conn_01x05_Male | PinHeader_1x05_P2.54mm_Vertical |
| 1 | J7 | Conn_01x01_Male | PinHeader_1x01_P2.54mm_Vertical |
| 1 | IC7 | 74LS148 | DIP-16_W7.62mm_LongPads |
| 1 | J8 | Conn_01x02_Male | PinHeader_1x02_P2.54mm_Vertical |
| 1 | IC1 | MC68010P10 | DIL64 |

## Items outside the component count

- The CSV also contains **four M3 mounting holes** and **six logo or compliance artwork objects**. They are PCB features, not parts to buy.
- The bare PCB and any required programming of the ATF22V10C GALs and Flash ROMs are not included as BOM lines. See the [PLD programming guide](../../code/pld/README.md) for IC2, IC3, IC5, and IC6.
- The original R2 packing list separately mentioned sockets for IC1 (DIL64, 1), IC2/IC3/IC5/IC6 (DIL24, 4), IC4 (PLCC44, 1), IC7 (DIL16, 1), IC15 (DIL08, 1), and U1/U2/U3/U4 (DIL32, 4). Treat these as assembly choices and verify fit against the PCB.
- The older packing list differs from this KiCad CSV for some headers (including J6 and J8). This table follows the CSV; inspect the current PCB before ordering those headers.

The source CSV has no supplier or manufacturer part numbers. Package names in this table are KiCad footprint identifiers, not vendor order codes.

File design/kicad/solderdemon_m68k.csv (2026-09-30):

Id | Designator | Package | Quantity | Designation | Supplier and ref
1 | H1,H2,H4,H3 | MountingHole_3.2mm_M3_Pad | 4 | MountingHole
2 | S1 | B3F-10XX | 1 | 10-XX
3 | R19,R11 | 0207_10 | 2 | 10K
4 | C1,C2 | C2.5_or_3.5-3 | 2 | 7pF
5 | C7,C8,C9,C20,C23,C24,C22,C26,C13,C27,C28,C30,C31,C6,C25,C29,C12,C10,C5,C4,C3,C32,C33 | C2.5-3 | 23 | 100nF
6 | C16,C17,C18,C19,C14,C15,C11 | E2,5-5 | 7 | 100uF
7 | C21 | E3,5-10 | 1 | 470uF
8 | IC4 | PLCC-44_THT-Socket | 1 | XR68C681CJTR-F
9 | IC3,IC2 | PLCC-44_THT-Socket | 2 | ATF1502AS-10JU44
10 | JP1,JP2,JP3,JP4 | 1X02 | 4 | Jumper
11 | LED3,LED1 | LED5MM | 2 | GREEN
12 | LED4,LED2 | LED5MM | 2 | RED
13 | Q1 | Crystal_HC49-4H_Vertical | 1 | 3.6864MHz
14 | Q2 | Oscillator_DIP-8 | 1 | 5H8ET-10.000
15 | U4,U3 | DIP-32_W15.24mm_LongPads | 2 | AS6C4008-55PCN
16 | U2,U1 | DIP-32_W15.24mm_LongPads | 2 | SST39SF040
17 | J3 | PinHeader_2x32_P2.54mm_Vertical | 1 | Conn_02x32_Odd_Even
18 | R8,R7,R9,R10,R32,R31,R12,R15,R17,R18,R3,R16 | 0207_10 | 12 | 4K7
19 | J4 | 1X06 | 1 | Conn_01x06
20 | J2 | 1X06 | 1 | UART_B
21 | J1 | 1X06 | 1 | UART_A
22 | J5 | 1X02 | 1 | PWR
23 | IC15 | DIP-8_W7.62mm_LongPads | 1 | 555N
24 | R27 | 0207_10 | 1 | 2K2
25 | R28 | 0207_10 | 1 | 270R
26 | R13,R14,R1,R2 | 0207_10 | 4 | 330R
27 | R21 | 0207_10 | 1 | 1K2
28 | REF**,REF** | SM-rosco_m68k_logo | 2 | SM-rosco_m68k_logo
29 | IC7 | DIP-16_W7.62mm_LongPads | 1 | 74LS148
30 | J8 | PinHeader_1x02_P2.54mm_Vertical | 1 | Conn_01x02_Male
31 | IC1 | DIL64 | 1 | MC68010P10
32 | OSHW_Mono_0.25_Scale | OSHW_Mono_0.25_Scale | 1 | UK000006
33 | REF** | RoHS-Logo_6mm_SilkScreen | 1 | RoHS-Logo_6mm_SilkScreen
34 | REF** | WEEE-Logo_5.6x8mm_SilkScreen | 1 | WEEE-Logo_5.6x8mm_SilkScreen
35 | REF** | MD-rosco_m68k_logo | 1 | MD-rosco_m68k_logo
36 | J9 | PinHeader_2x05_P2.54mm_Vertical | 1 | JTAG

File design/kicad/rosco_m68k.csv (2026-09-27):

Id | Designator | Package | Quantity | Designation | Supplier and ref
1 | H1,H2,H4,H3 | MountingHole_3.2mm_M3_Pad | 4 | MountingHole
2 | S1 | B3F-10XX | 1 | 10-XX
3 | R19,R11 | 0207_10 | 2 | 10K
4 | C1,C2 | C2.5_or_3.5-3 | 2 | 7pF
5 | C7,C8,C9,C20,C23,C24,C22,C26,C13,C27,C28,C30,C31,C6,C25,C29,C12,C10,C5,C4,C3,C32 | C2.5-3 | 22 | 100nF
6 | C16,C17,C18,C19,C14,C15,C11 | E2,5-5 | 7 | 100uF
7 | C21 | E3,5-10 | 1 | 470uF
8 | IC4 | PLCC-44_THT-Socket | 1 | XR68C681CJTR-F
9 | IC5,IC6,IC3,IC2 | DIP-24_W7.62mm_Socket_LongPads | 4 | ATF22V10C
10 | JP1,JP2,JP3,JP4 | 1X02 | 4 | Jumper
11 | LED3,LED1 | LED5MM | 2 | GREEN
12 | LED4,LED2 | LED5MM | 2 | RED
13 | Q1 | Crystal_HC49-4H_Vertical | 1 | 3.6864MHz
14 | Q2 | Oscillator_DIP-8 | 1 | 5H8ET-10.000
15 | U4,U3 | DIP-32_W15.24mm_LongPads | 2 | AS6C4008-55PCN
16 | U2,U1 | DIP-32_W15.24mm_LongPads | 2 | SST39SF040
17 | J3 | PinHeader_2x32_P2.54mm_Vertical | 1 | Conn_02x32_Odd_Even
18 | R8,R7,R9,R10,R32,R31,R12,R15,R17,R18,R3,R16 | 0207_10 | 12 | 4K7
19 | J4 | 1X06 | 1 | Conn_01x06
20 | J2 | 1X06 | 1 | UART_B
21 | J1 | 1X06 | 1 | UART_A
22 | J5 | 1X02 | 1 | PWR
23 | IC15 | DIP-8_W7.62mm_LongPads | 1 | 555N
24 | R27 | 0207_10 | 1 | 2K2
25 | R28 | 0207_10 | 1 | 270R
26 | R13,R14,R1,R2 | 0207_10 | 4 | 330R
27 | R21 | 0207_10 | 1 | 1K2
28 | J6 | PinHeader_1x05_P2.54mm_Vertical | 1 | Conn_01x05_Male
29 | REF**,REF** | SM-rosco_m68k_logo | 2 | SM-rosco_m68k_logo
30 | J7 | PinHeader_1x01_P2.54mm_Vertical | 1 | Conn_01x01_Male
31 | IC7 | DIP-16_W7.62mm_LongPads | 1 | 74LS148
32 | J8 | PinHeader_1x02_P2.54mm_Vertical | 1 | Conn_01x02_Male
33 | IC1 | DIL64 | 1 | MC68010P10
34 | OSHW_Mono_0.25_Scale | OSHW_Mono_0.25_Scale | 1 | UK000006
35 | REF** | RoHS-Logo_6mm_SilkScreen | 1 | RoHS-Logo_6mm_SilkScreen
36 | REF** | WEEE-Logo_5.6x8mm_SilkScreen | 1 | WEEE-Logo_5.6x8mm_SilkScreen
37 | REF** | MD-rosco_m68k_logo | 1 | MD-rosco_m68k_logo

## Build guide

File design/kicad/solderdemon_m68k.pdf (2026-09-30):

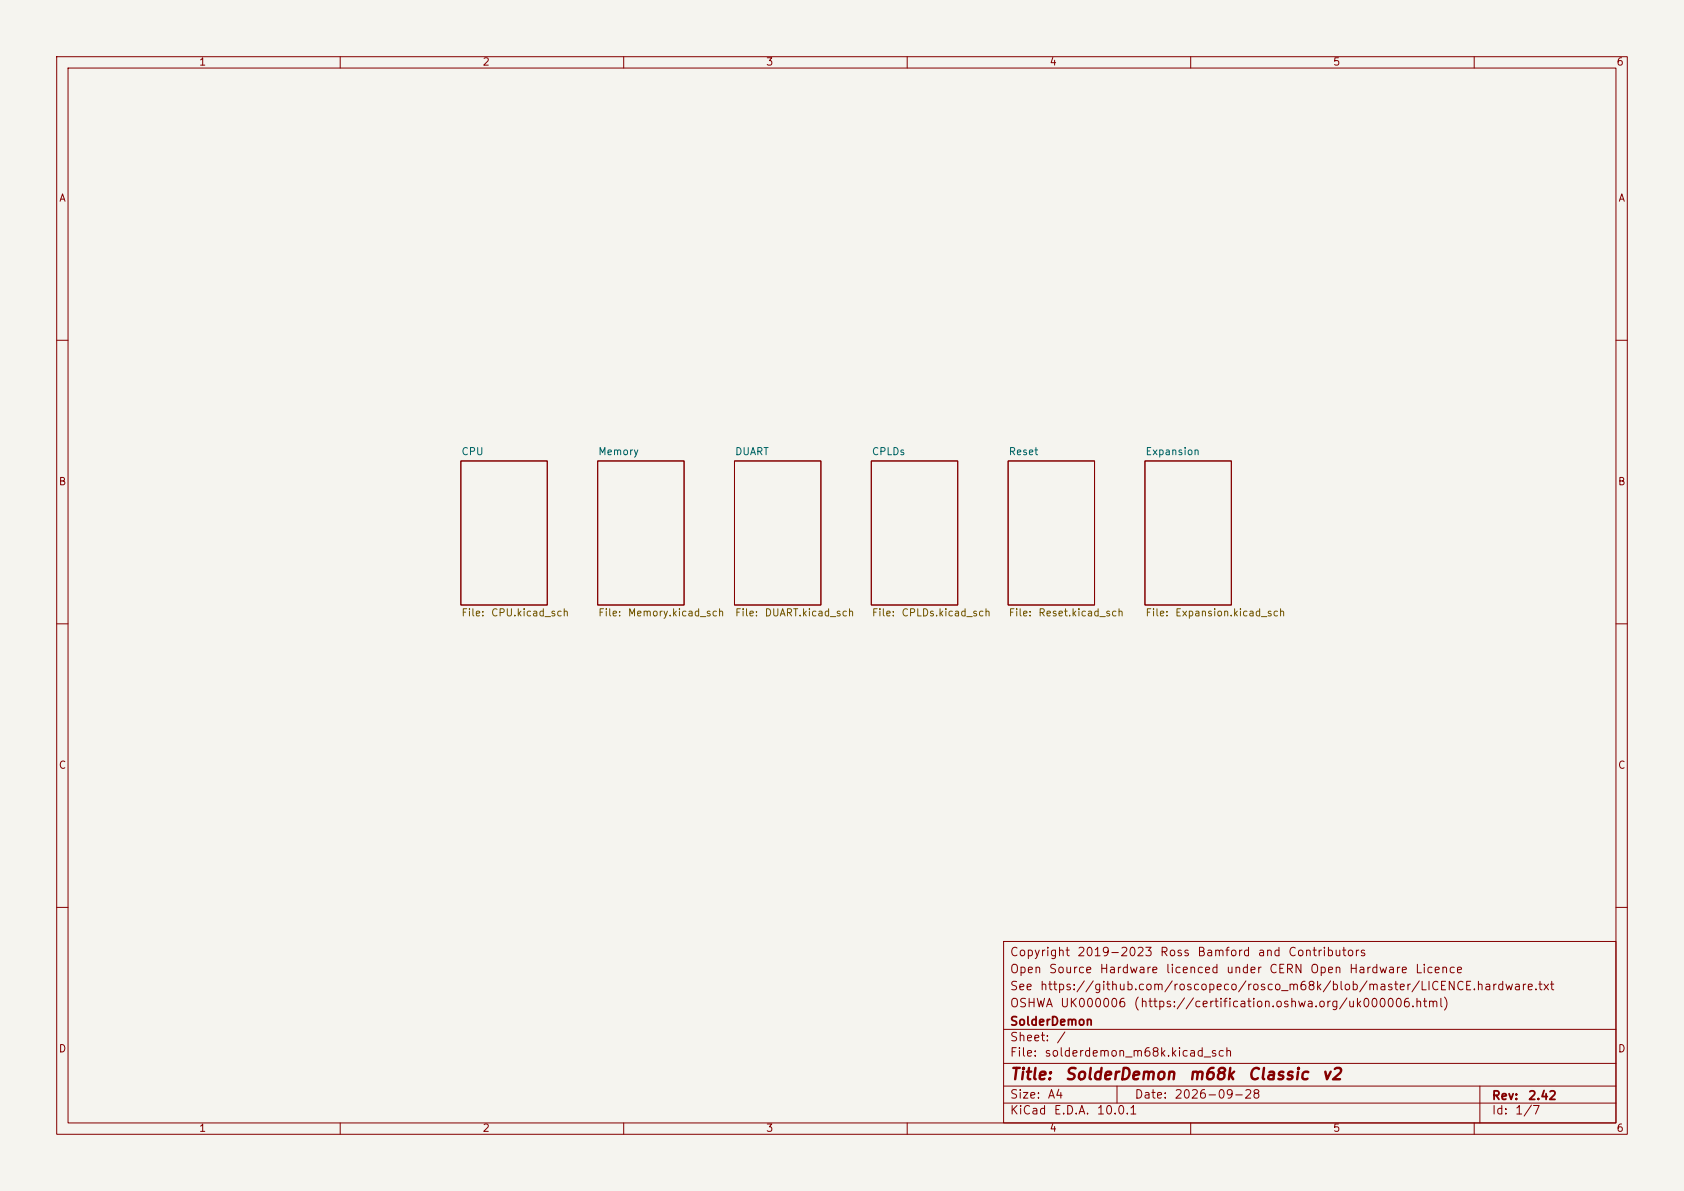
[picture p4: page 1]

Copyright 2019-2023 Ross Bamford and Contributors
Open Source Hardware licenced under CERN Open Hardware Licence
See https://github.com/roscopeco/rosco_m68k/blob/master/LICENCE.hardware.txt
OSHWA UK000006 (https://certification.oshwa.org/uk000006.html)
SolderDemon
Sheet: /
File: solderdemon_m68k.kicad_sch
Title: SolderDemon m68k Classic v2

Size: A4 | Rev: 2.42
KiCad E.D.A. 10.0.1 | Id: 1/7

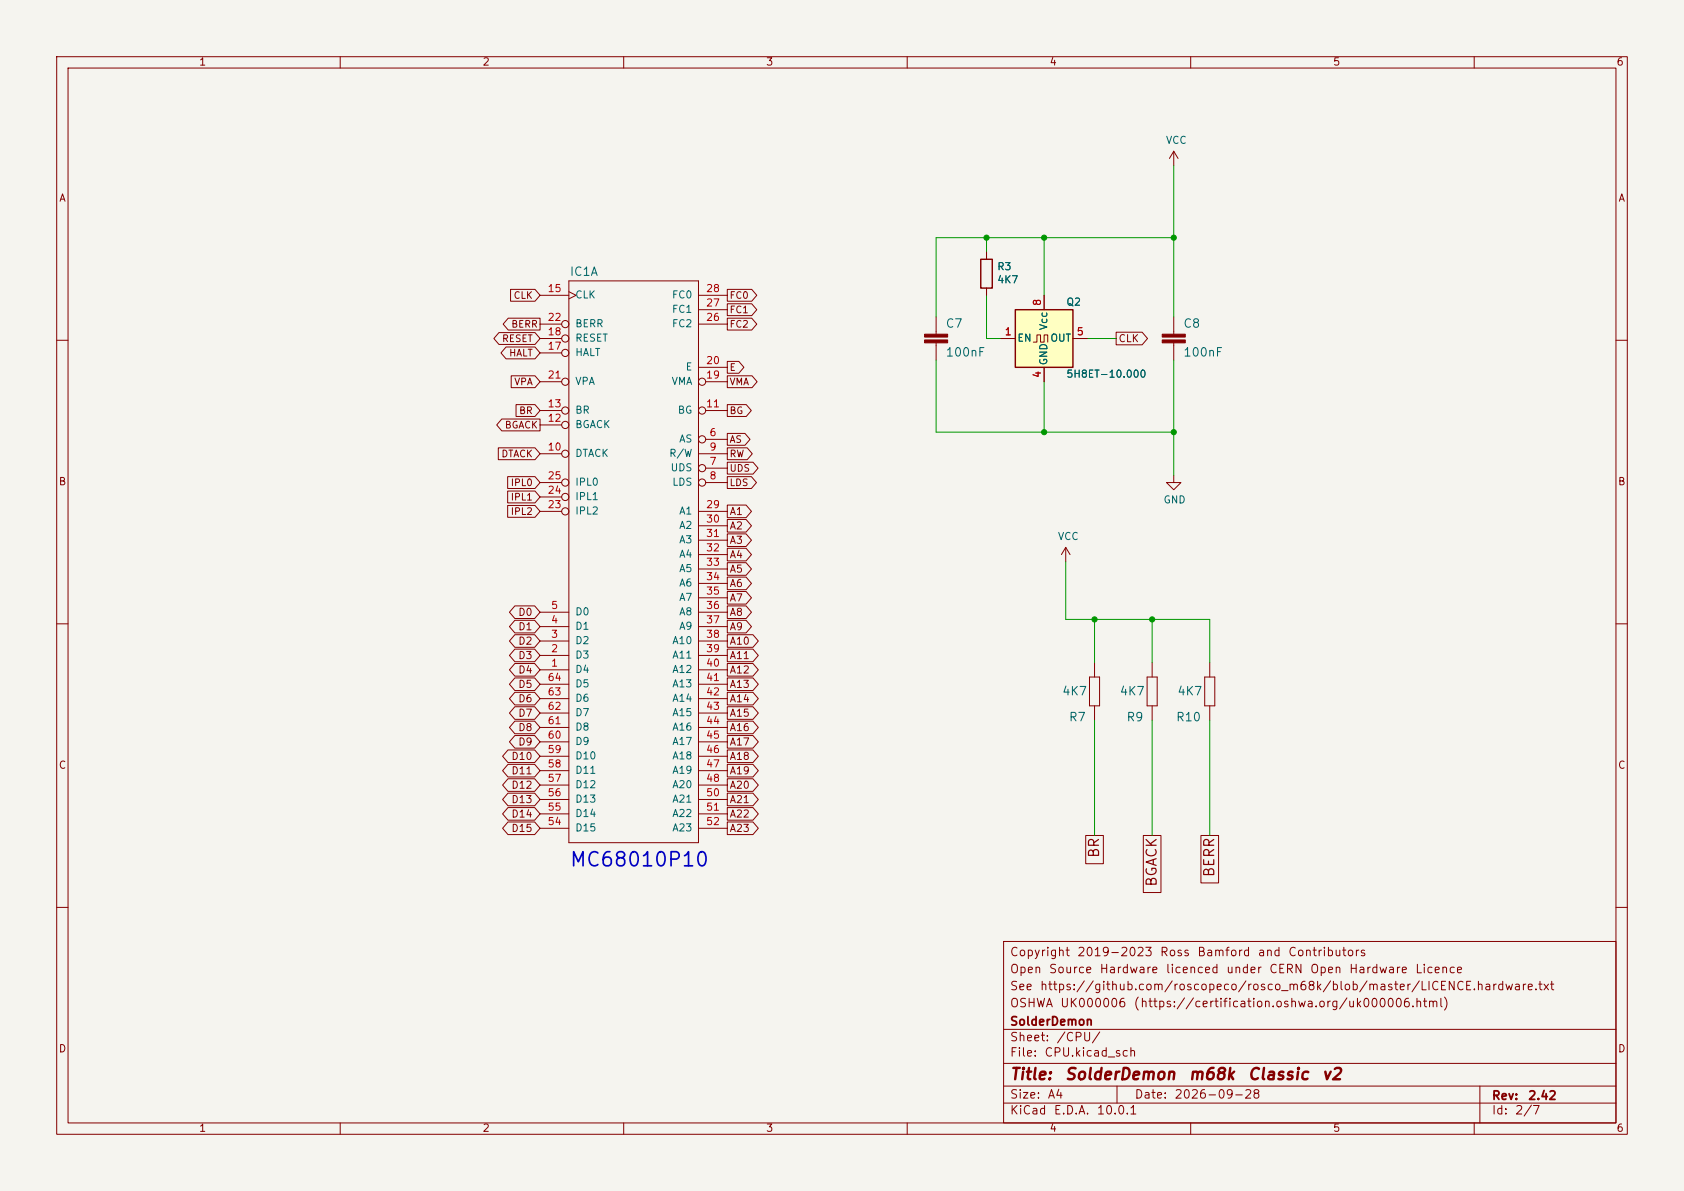
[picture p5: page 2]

Copyright 2019-2023 Ross Bamford and Contributors
Open Source Hardware licenced under CERN Open Hardware Licence
See https://github.com/roscopeco/rosco_m68k/blob/master/LICENCE.hardware.txt
OSHWA UK000006 (https://certification.oshwa.org/uk000006.html)
SolderDemon
Sheet: /CPU/
File: CPU.kicad_sch
Title: SolderDemon m68k Classic v2

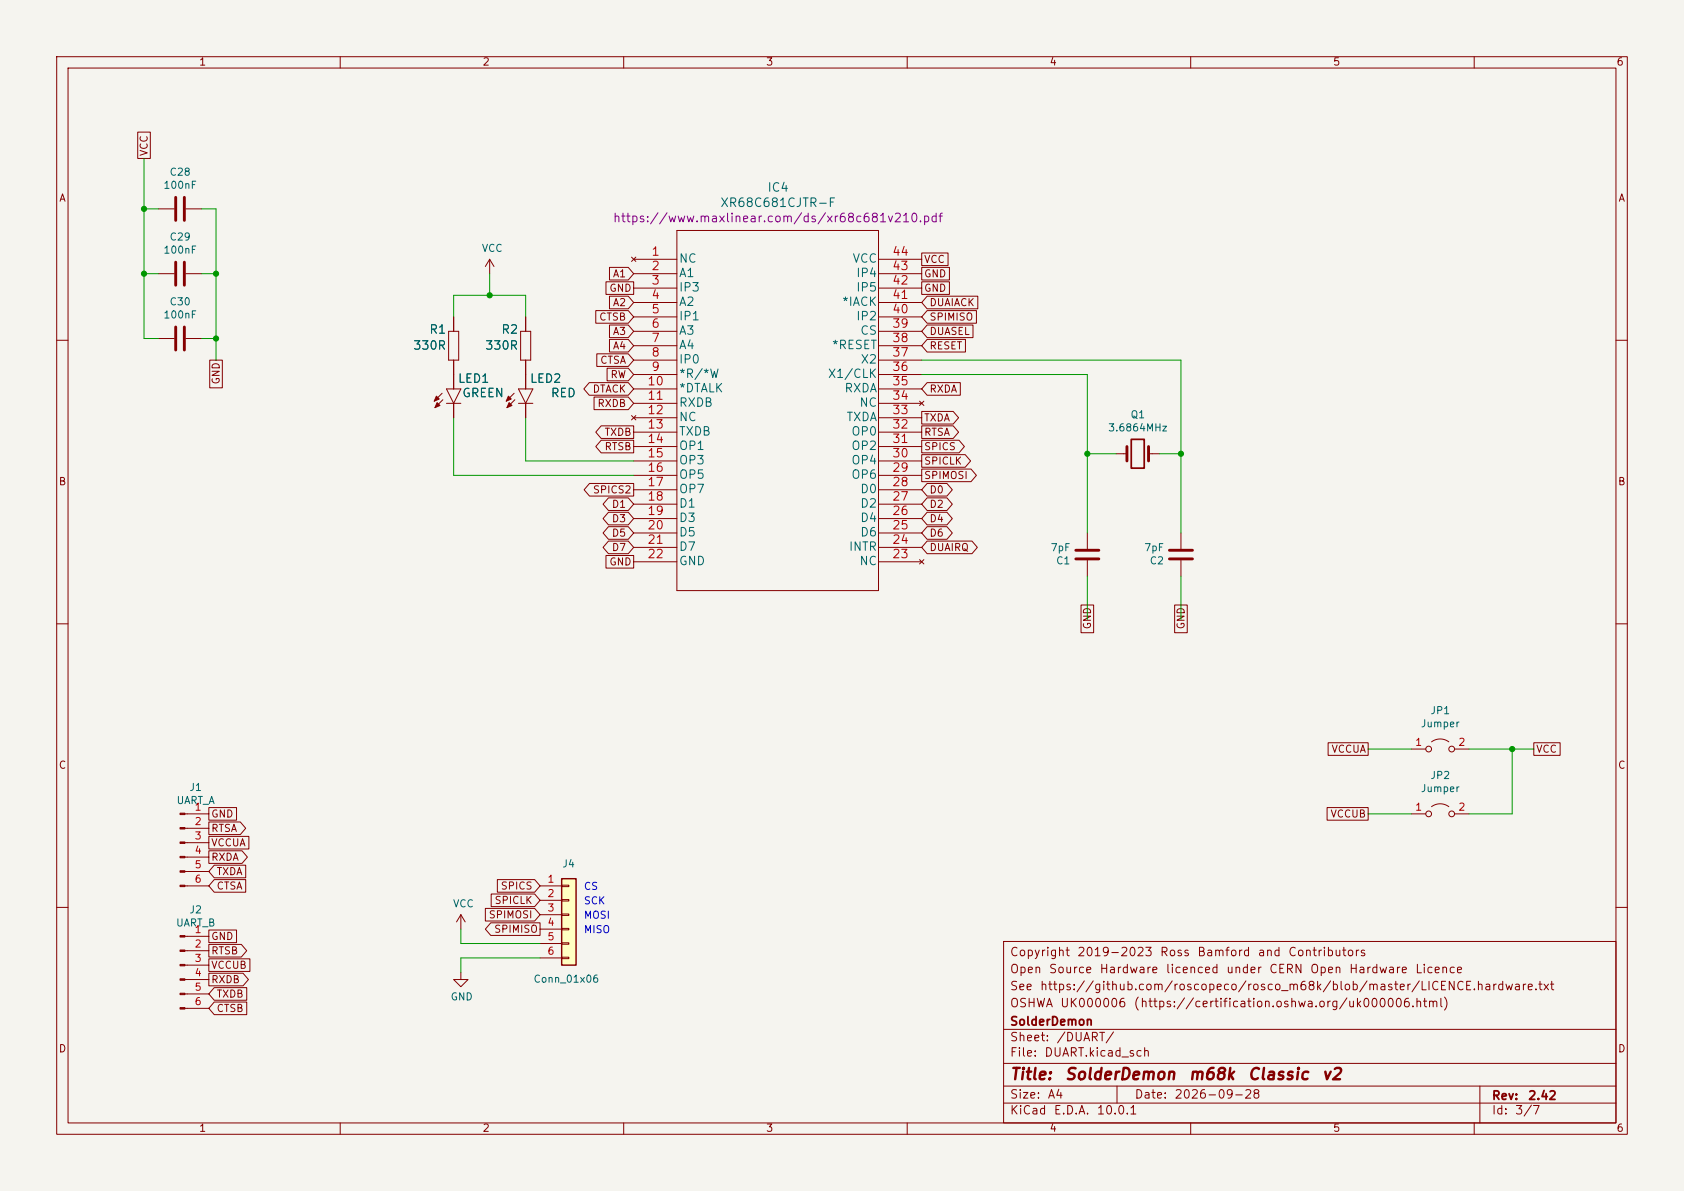
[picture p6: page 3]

Copyright 2019-2023 Ross Bamford and Contributors
Open Source Hardware licenced under CERN Open Hardware Licence
See https://github.com/roscopeco/rosco_m68k/blob/master/LICENCE.hardware.txt
OSHWA UK000006 (https://certification.oshwa.org/uk000006.html)
SolderDemon
Sheet: /DUART/
File: DUART.kicad_sch
Title: SolderDemon m68k Classic v2

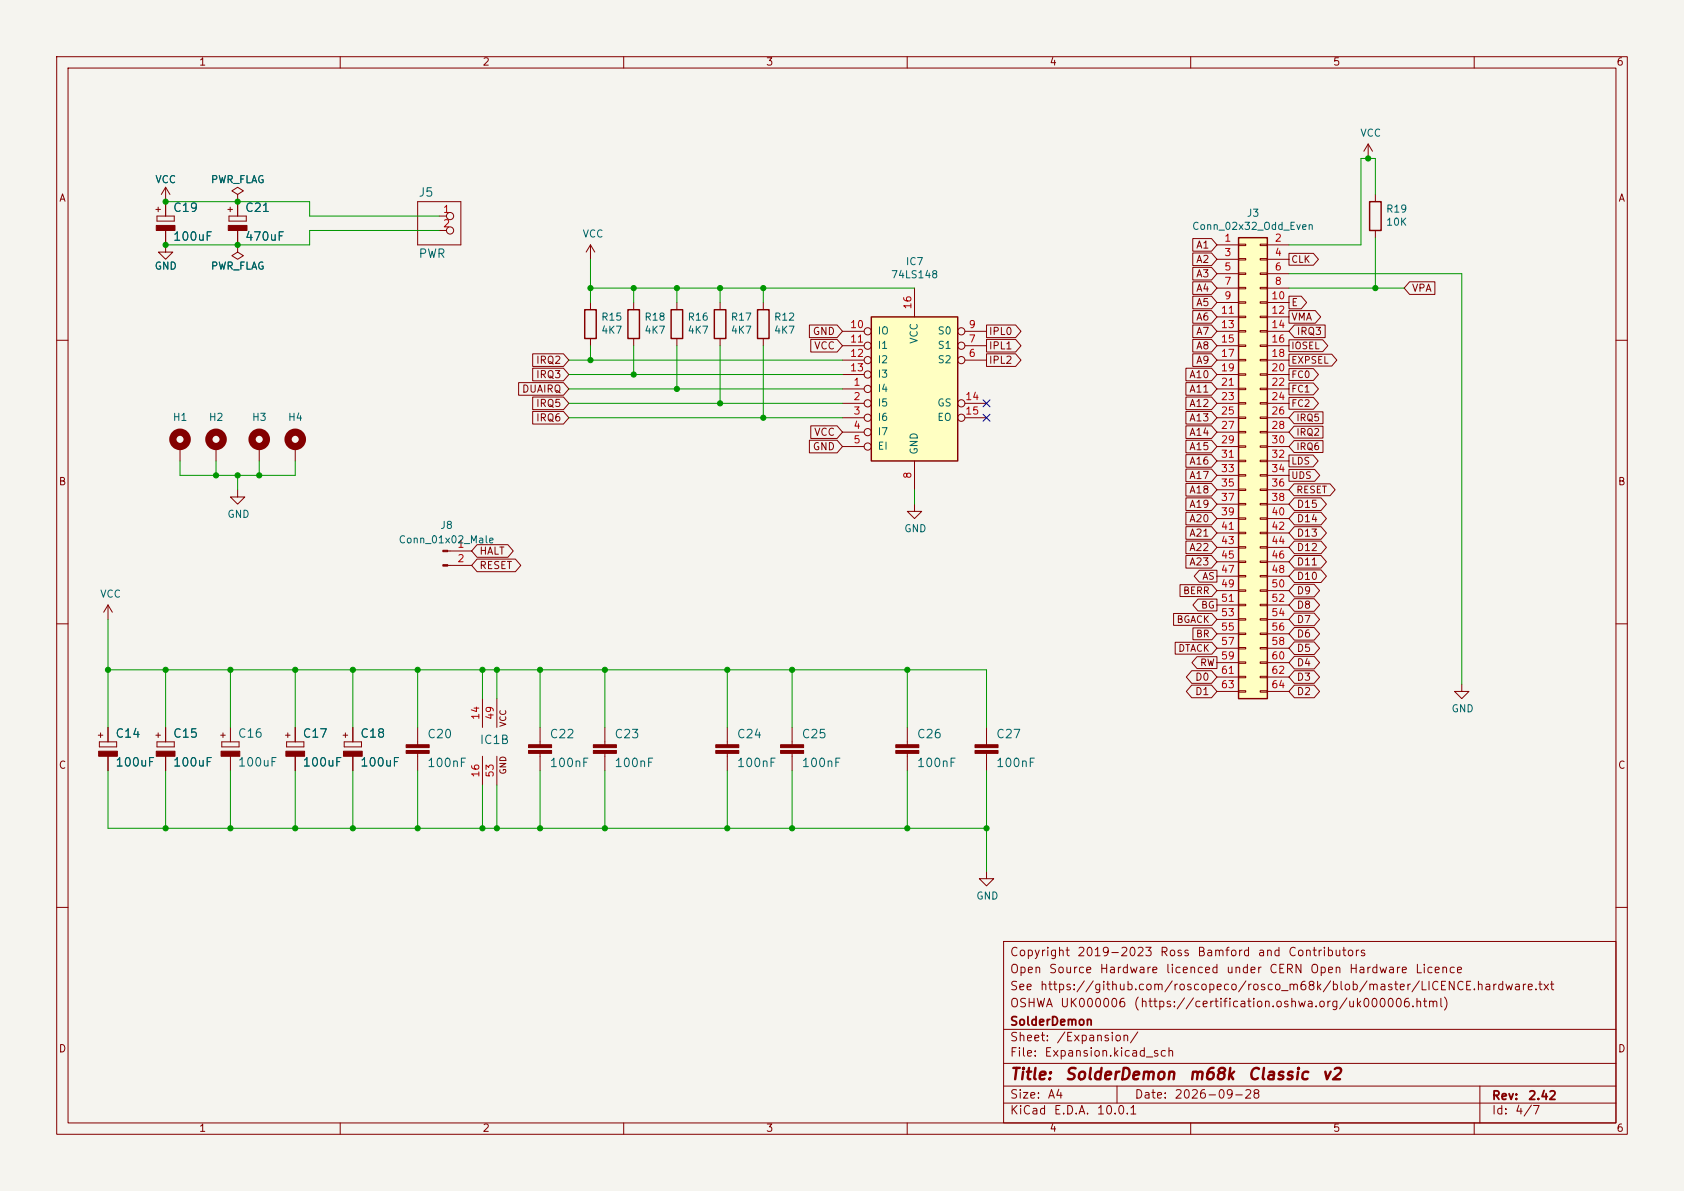
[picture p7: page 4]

Copyright 2019-2023 Ross Bamford and Contributors
Open Source Hardware licenced under CERN Open Hardware Licence
See https://github.com/roscopeco/rosco_m68k/blob/master/LICENCE.hardware.txt
OSHWA UK000006 (https://certification.oshwa.org/uk000006.html)
SolderDemon
Sheet: /Expansion/
File: Expansion.kicad_sch
Title: SolderDemon m68k Classic v2

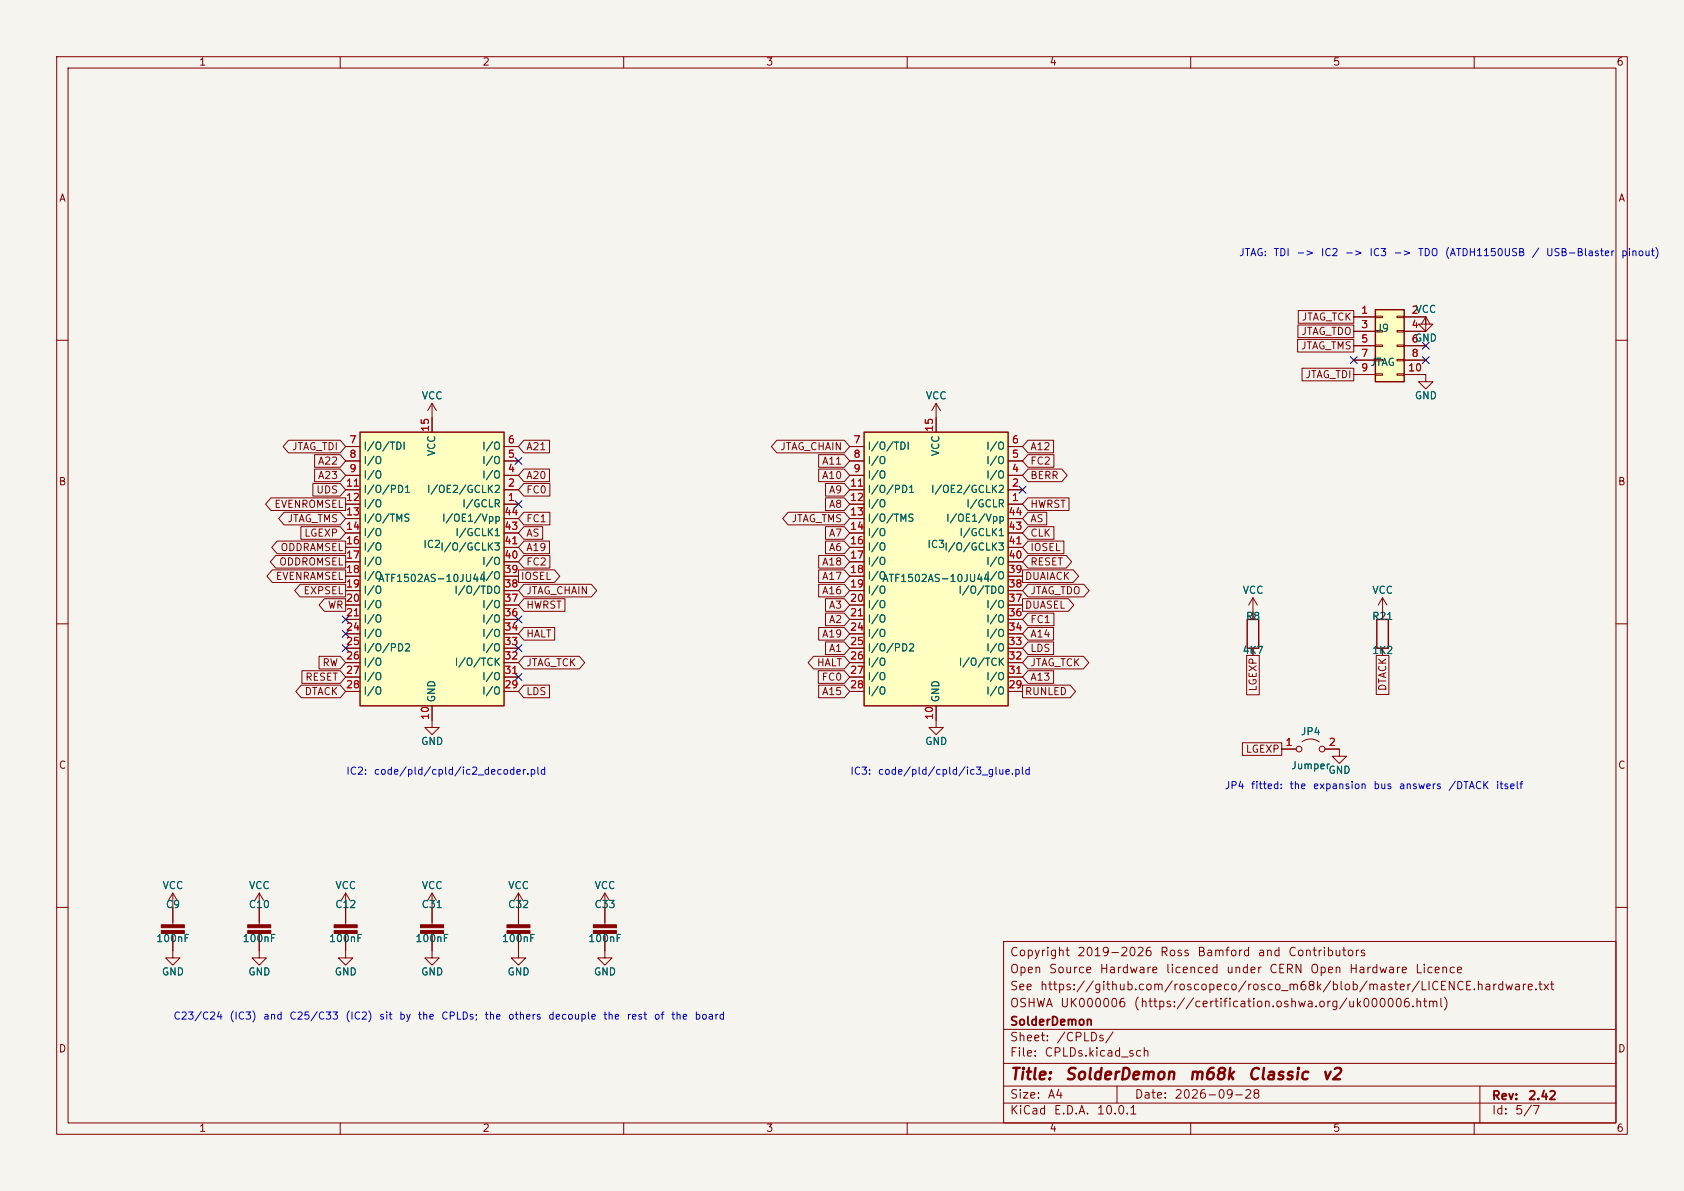
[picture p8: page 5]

JTAG: TDI -> IC2 -> IC3 -> TDO (ATDH1150USB / USB-Blaster pinout) J9

A18 C23/C24 (IC3) and C25/C33 (IC2) sit by the CPLDs; the others decouple the rest of the board

JP4 fitted: the expansion bus answers /DTACK itself

Open Source Hardware licenced under CERN Open Hardware Licence
See https://github.com/roscopeco/rosco_m68k/blob/master/LICENCE.hardware.txt
OSHWA UK000006 (https://certification.oshwa.org/uk000006.html)
SolderDemon
Sheet: /CPLDs/
File: CPLDs.kicad_sch
Title: SolderDemon m68k Classic v2

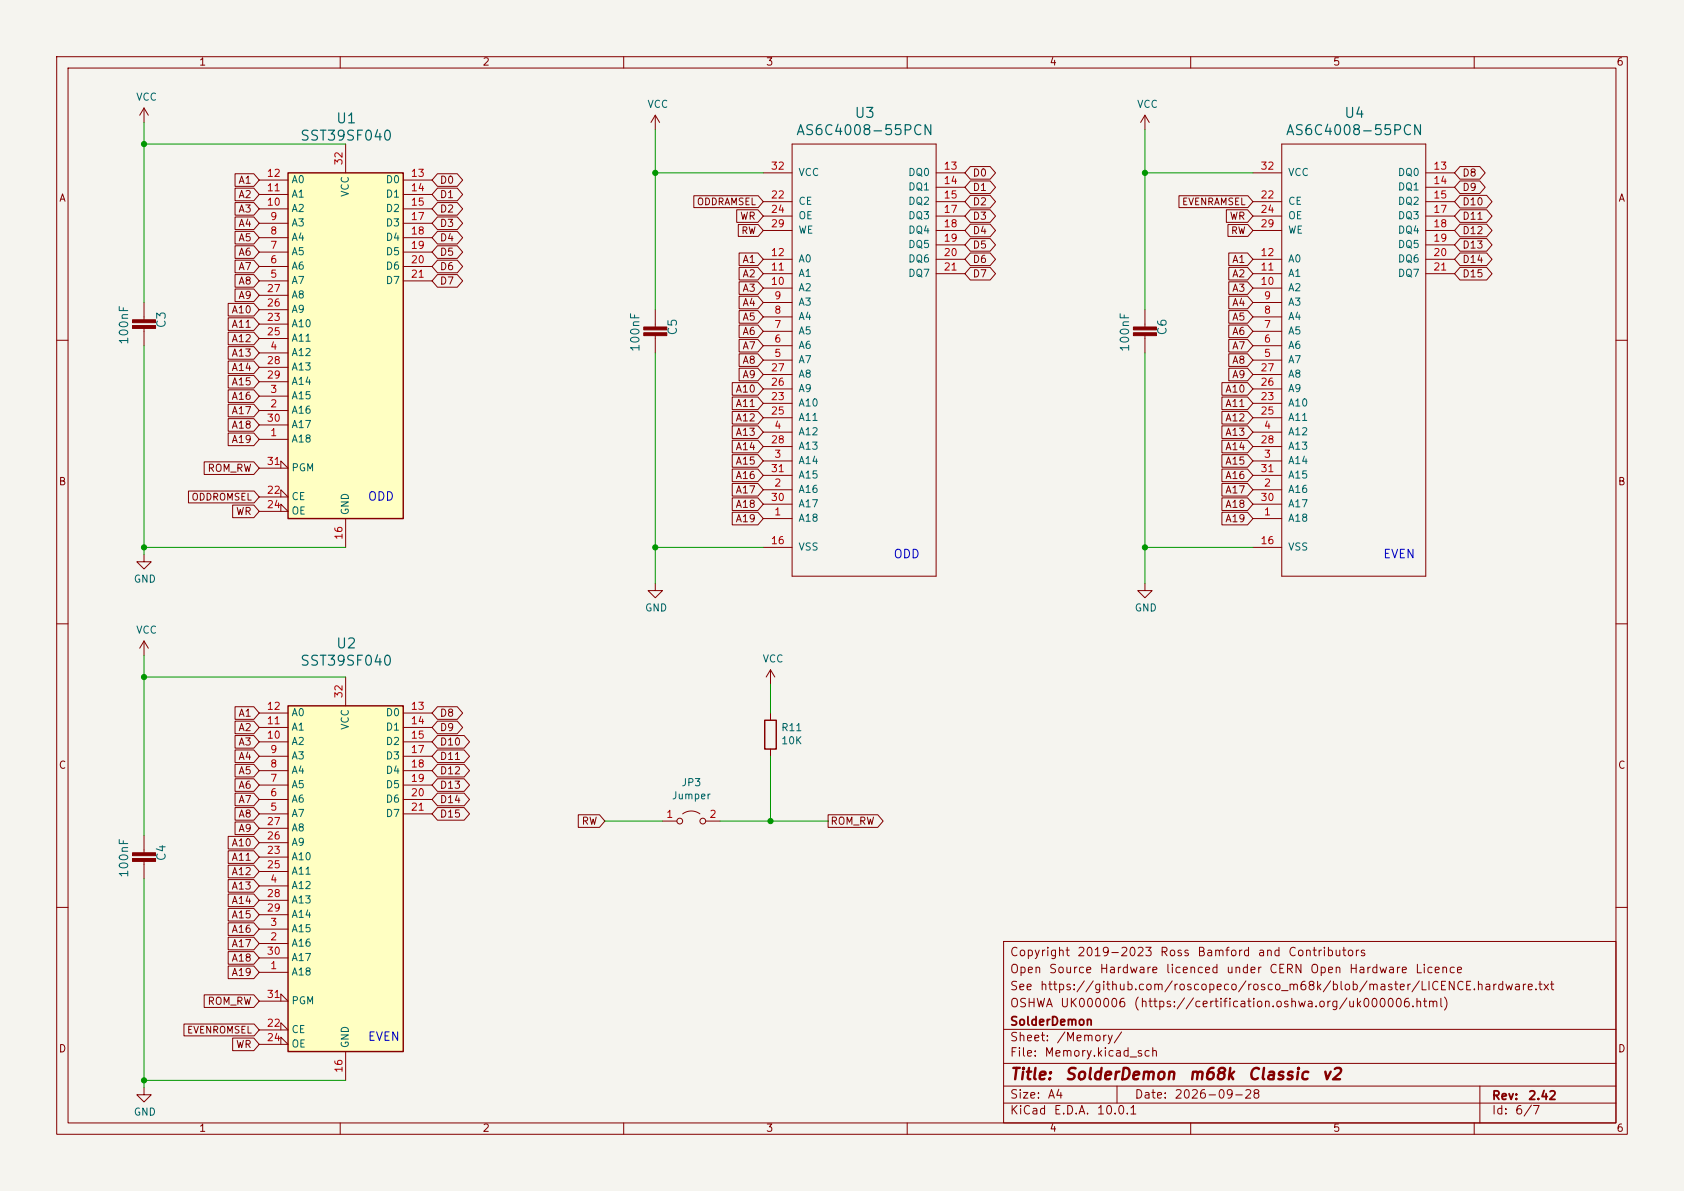
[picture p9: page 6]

Open Source Hardware licenced under CERN Open Hardware Licence
See https://github.com/roscopeco/rosco_m68k/blob/master/LICENCE.hardware.txt
OSHWA UK000006 (https://certification.oshwa.org/uk000006.html)
SolderDemon
Sheet: /Memory/
File: Memory.kicad_sch
Title: SolderDemon m68k Classic v2

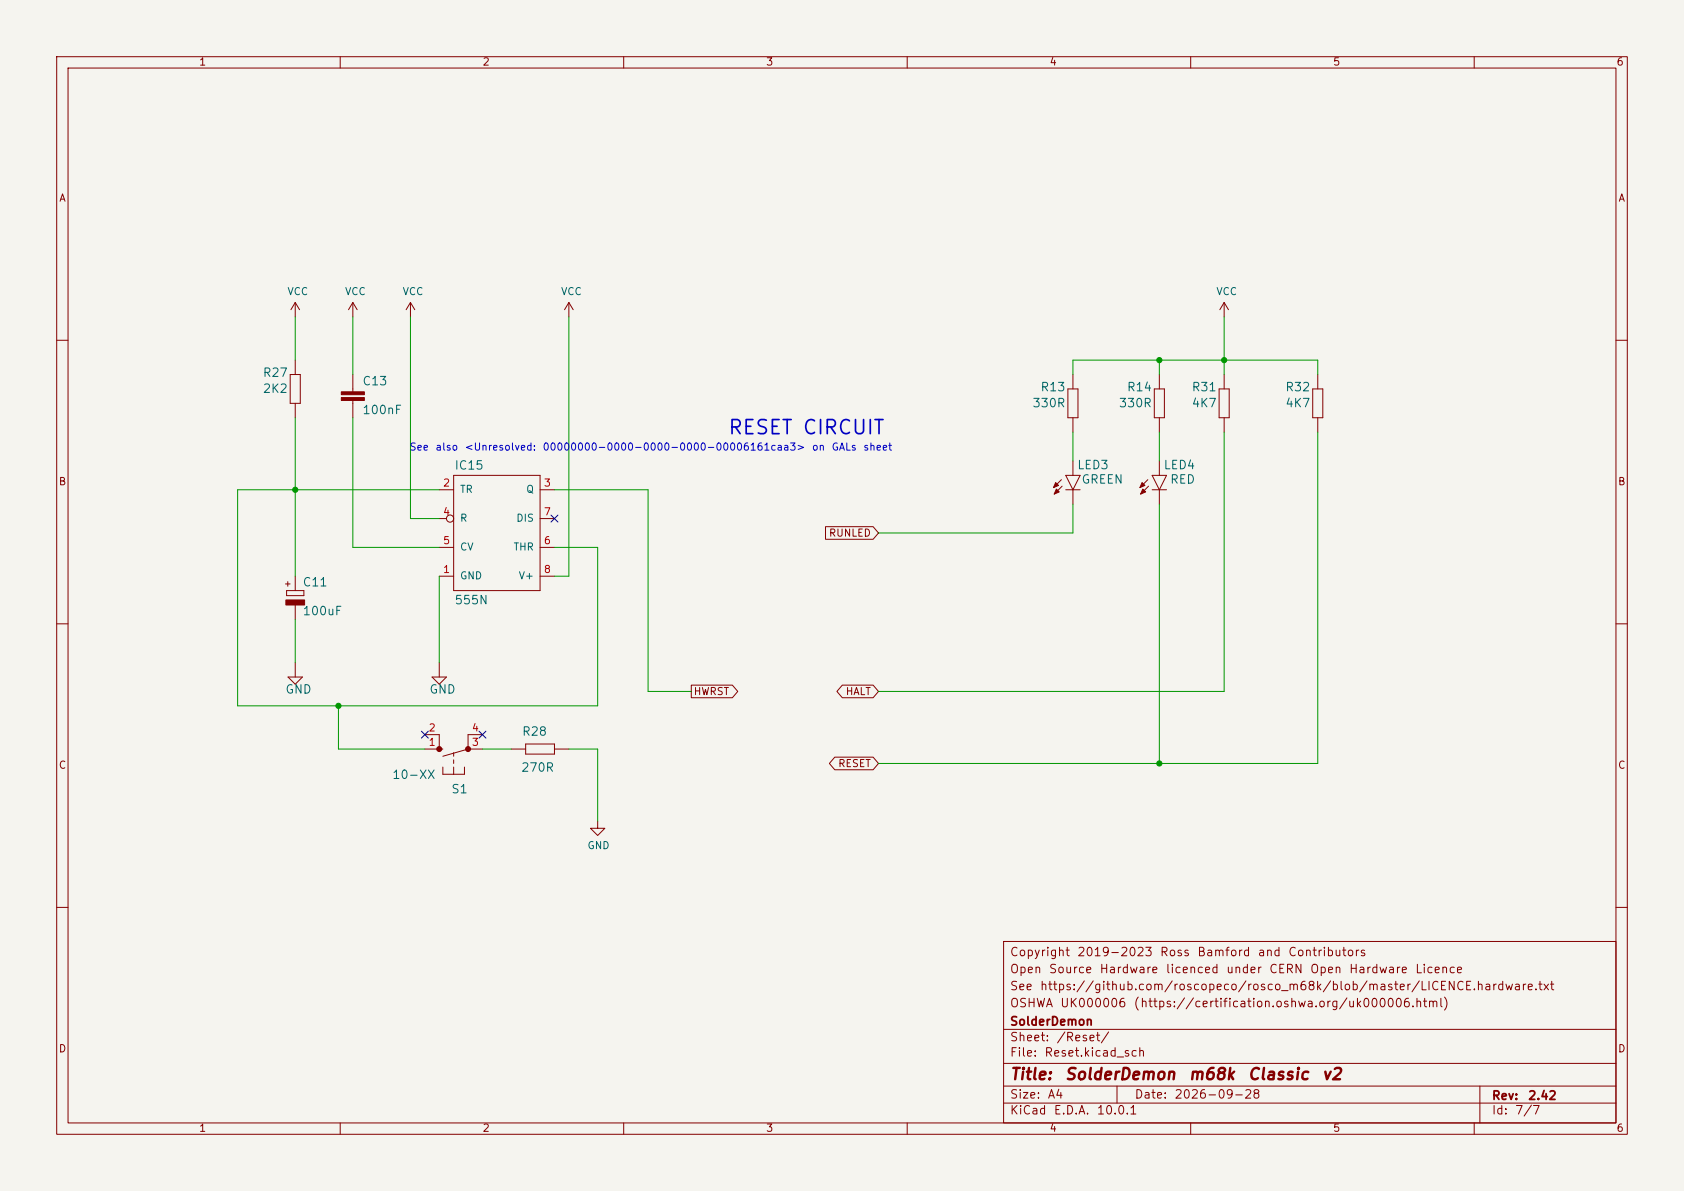
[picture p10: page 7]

Copyright 2019-2023 Ross Bamford and Contributors
Open Source Hardware licenced under CERN Open Hardware Licence
See https://github.com/roscopeco/rosco_m68k/blob/master/LICENCE.hardware.txt
OSHWA UK000006 (https://certification.oshwa.org/uk000006.html)
SolderDemon
Sheet: /Reset/
File: Reset.kicad_sch
Title: SolderDemon m68k Classic v2

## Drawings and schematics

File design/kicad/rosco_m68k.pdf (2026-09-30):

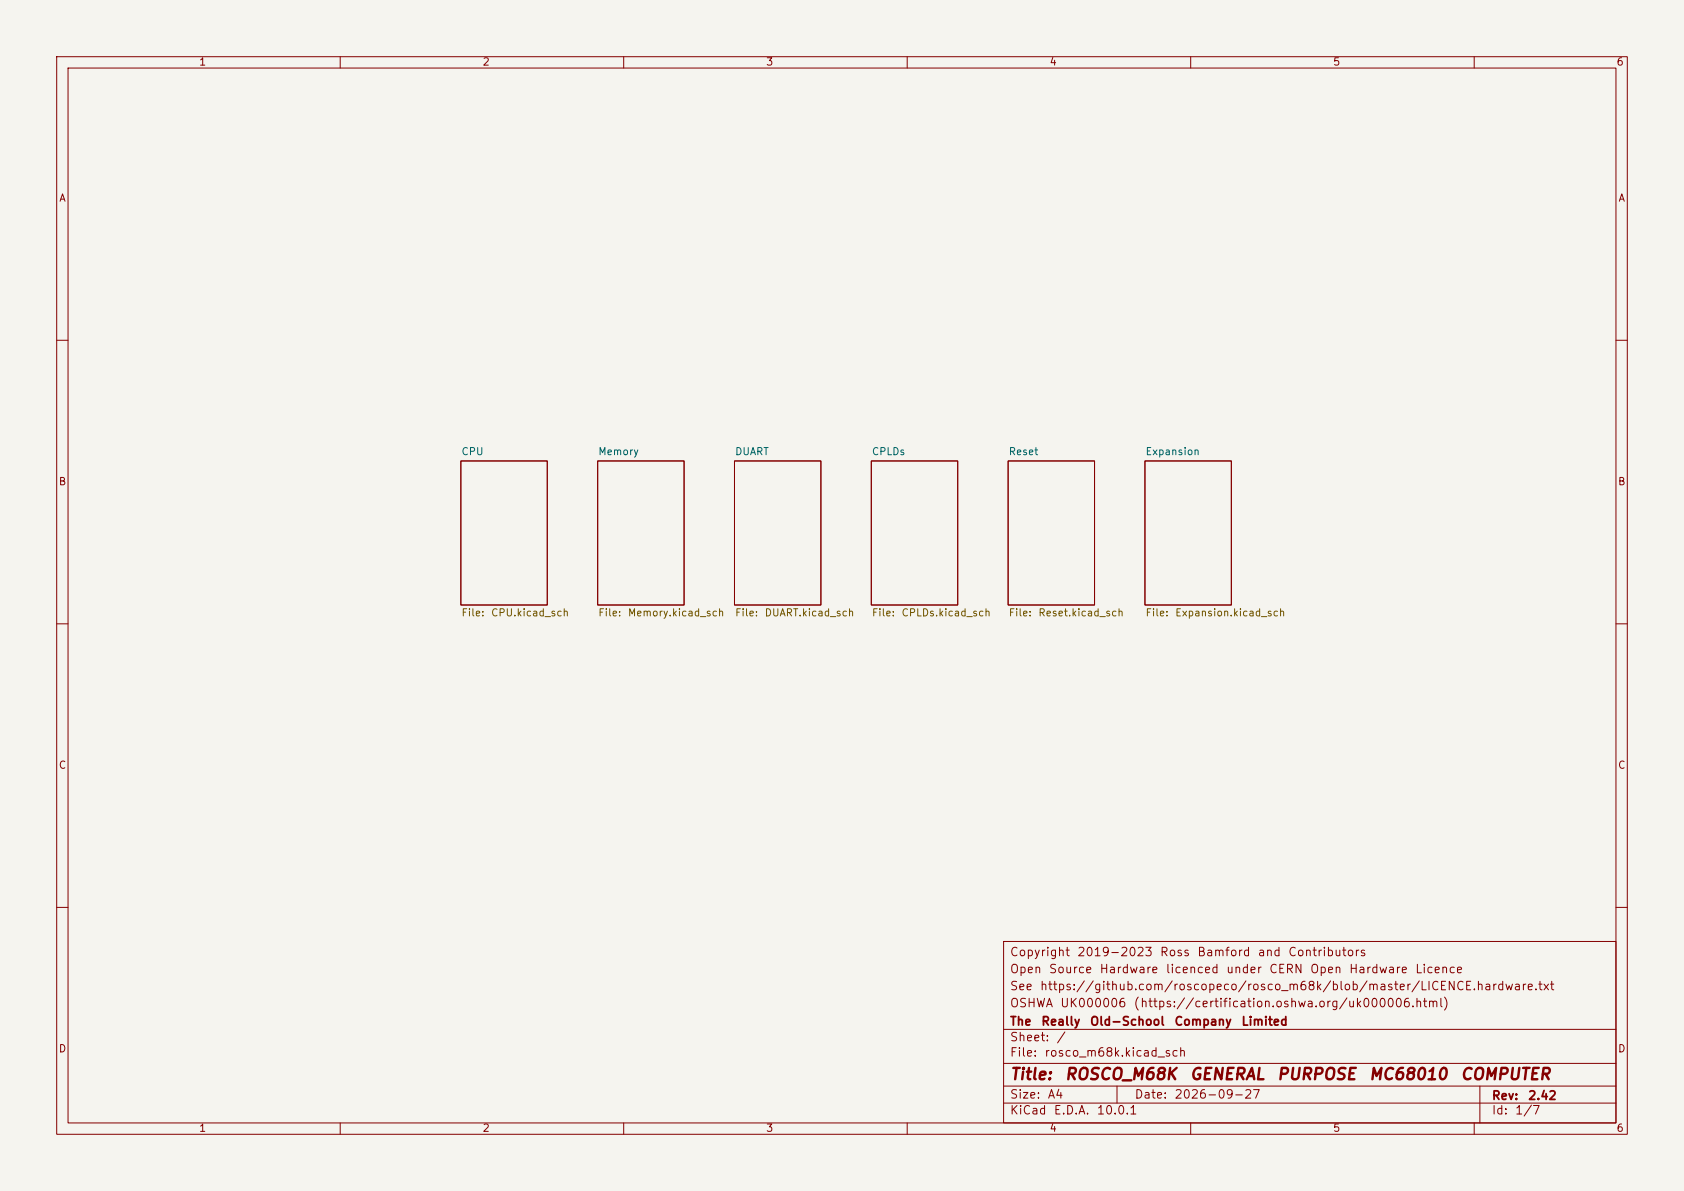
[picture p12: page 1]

Copyright 2019-2023 Ross Bamford and Contributors
Open Source Hardware licenced under CERN Open Hardware Licence
See https://github.com/roscopeco/rosco_m68k/blob/master/LICENCE.hardware.txt
OSHWA UK000006 (https://certification.oshwa.org/uk000006.html)
The Really Old-School Company Limited
Sheet: /
File: rosco_m68k.kicad_sch
Title: ROSCO_M68K GENERAL PURPOSE MC68010 COMPUTER

Size: A4 | Rev: 2.42
KiCad E.D.A. 10.0.1 | Id: 1/7

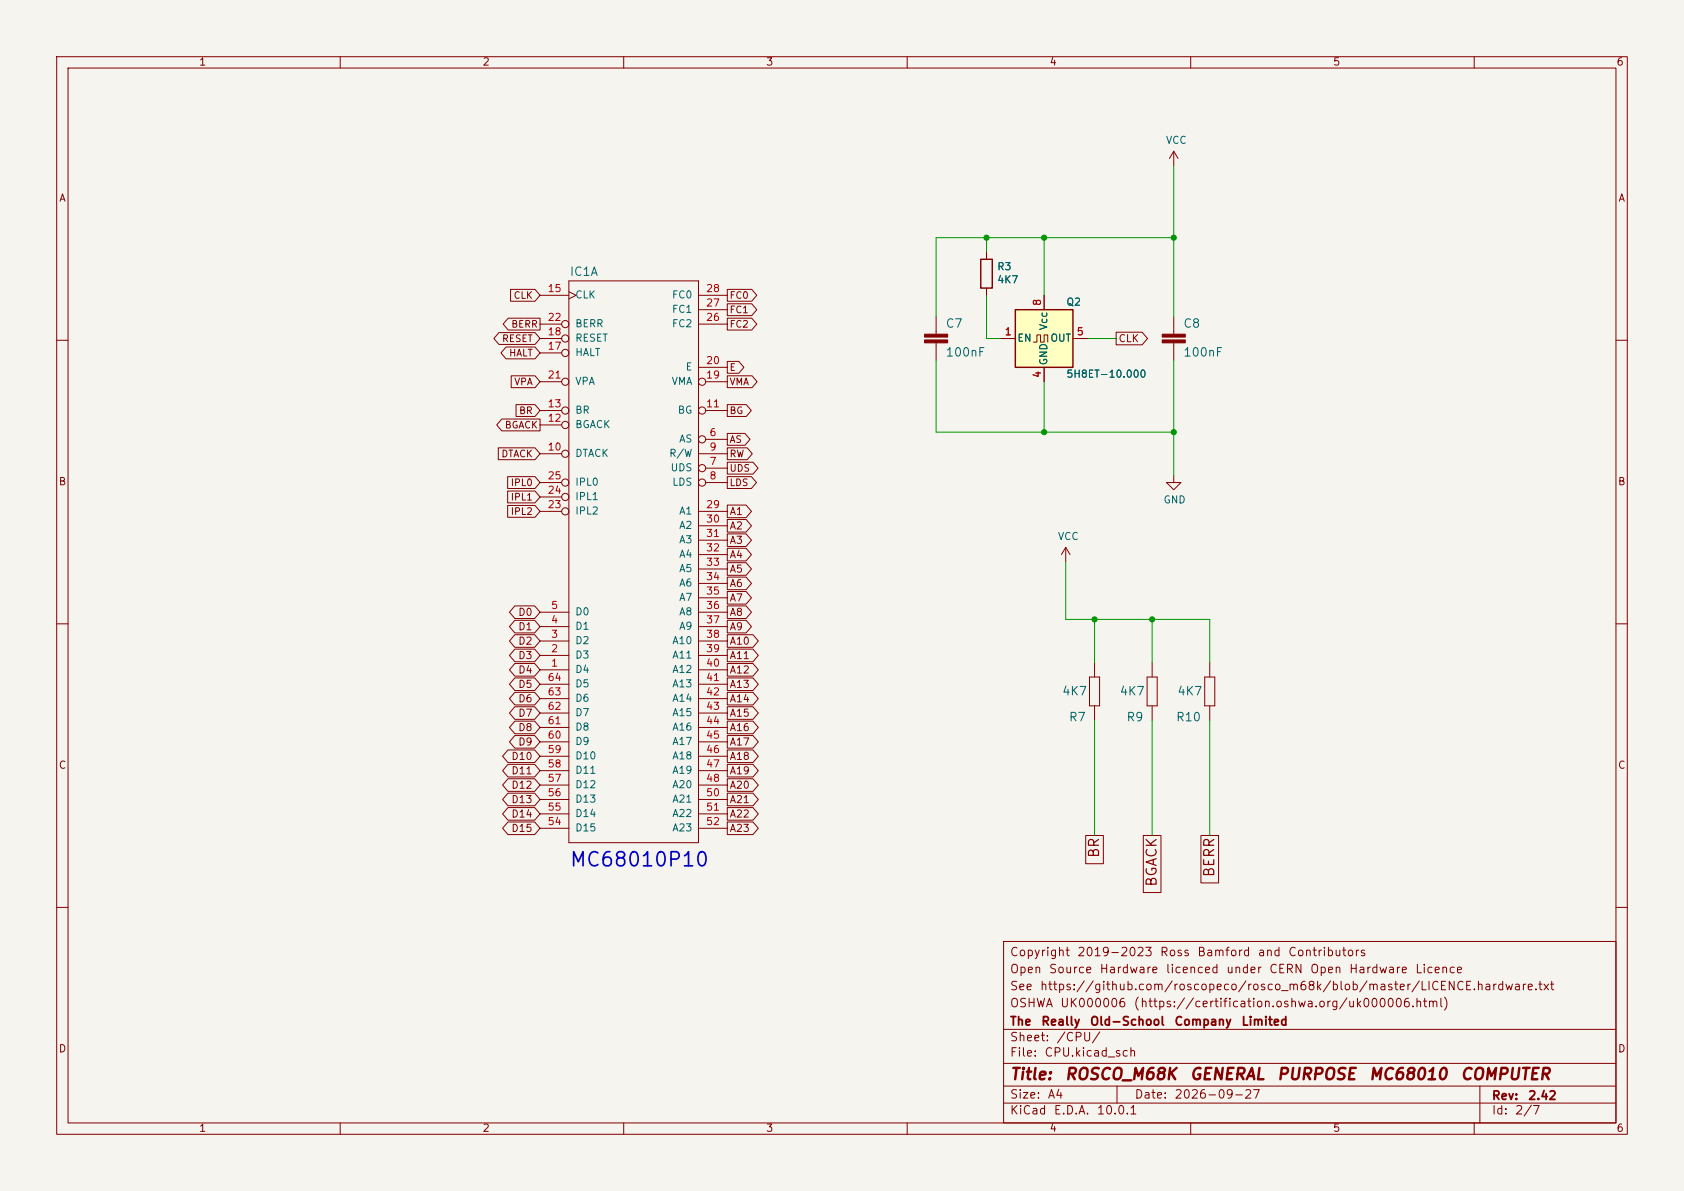
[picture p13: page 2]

Copyright 2019-2023 Ross Bamford and Contributors
Open Source Hardware licenced under CERN Open Hardware Licence
See https://github.com/roscopeco/rosco_m68k/blob/master/LICENCE.hardware.txt
OSHWA UK000006 (https://certification.oshwa.org/uk000006.html)
The Really Old-School Company Limited
Sheet: /CPU/
File: CPU.kicad_sch
Title: ROSCO_M68K GENERAL PURPOSE MC68010 COMPUTER

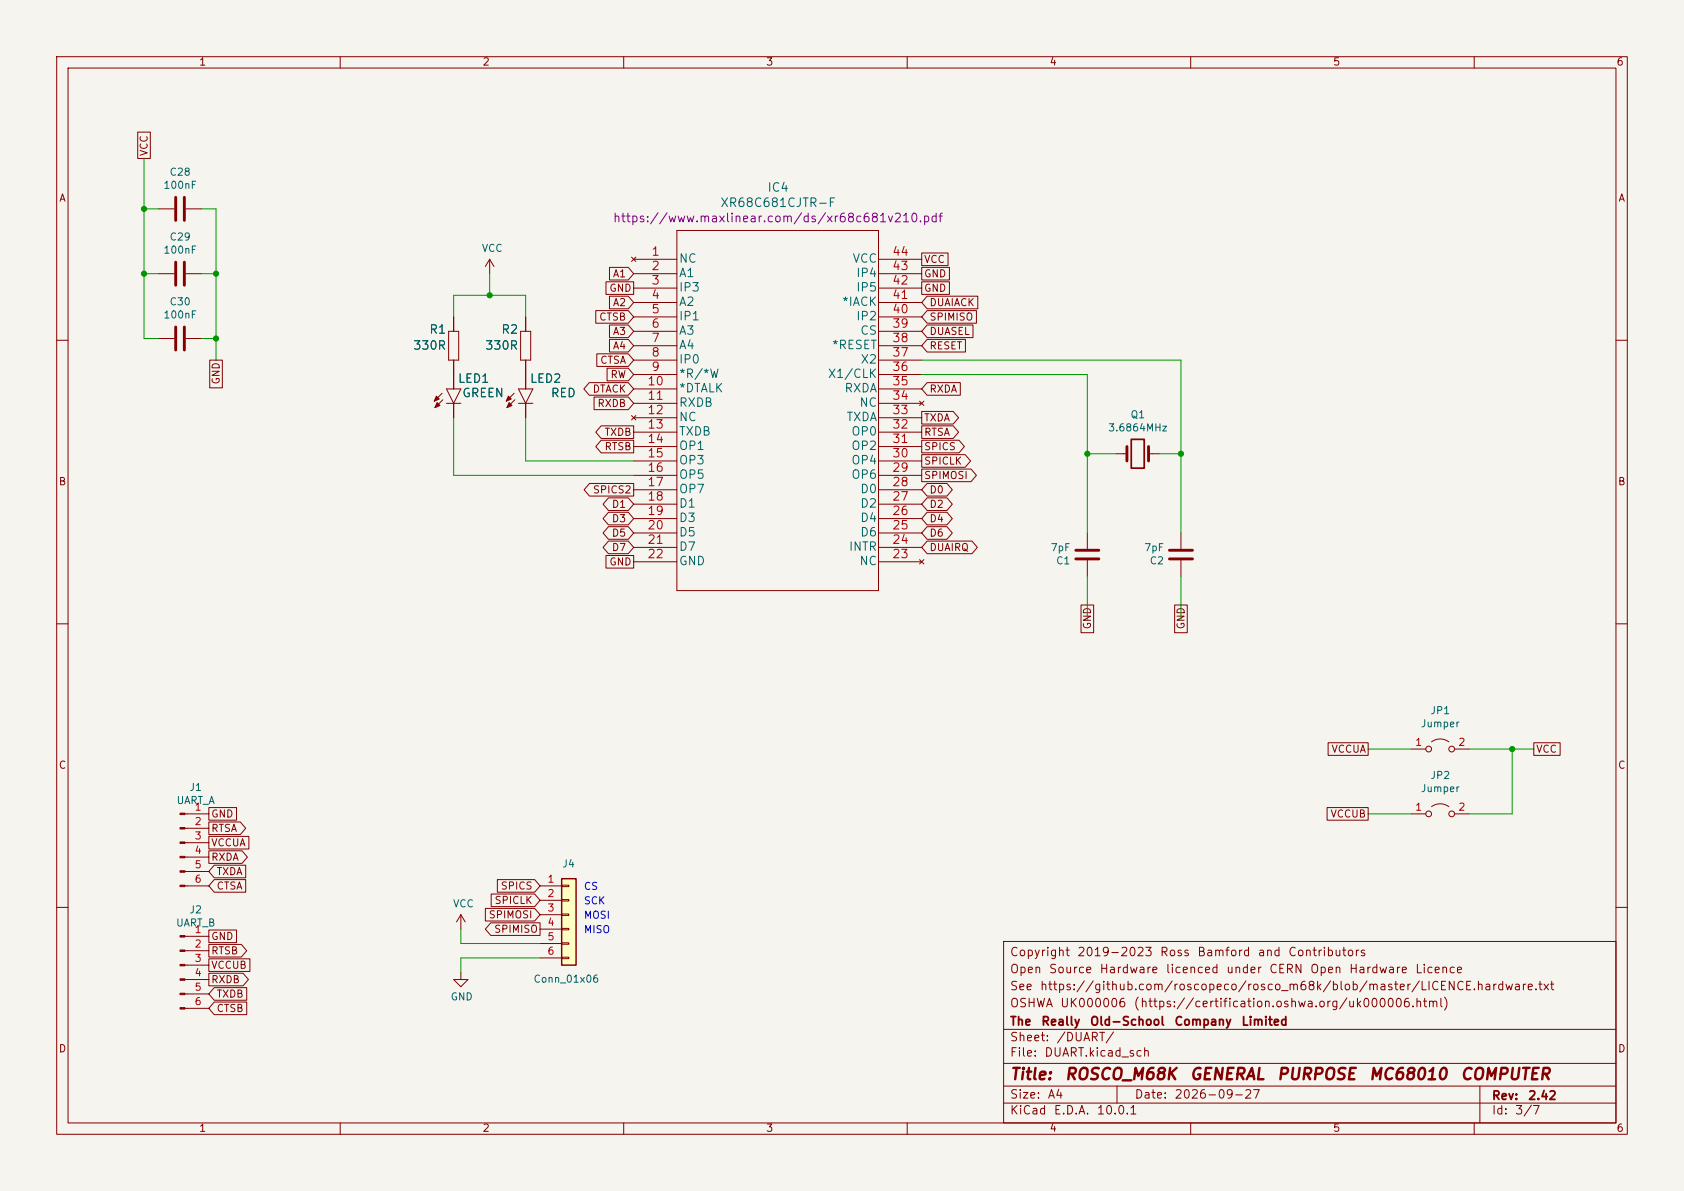
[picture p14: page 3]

Copyright 2019-2023 Ross Bamford and Contributors
Open Source Hardware licenced under CERN Open Hardware Licence
See https://github.com/roscopeco/rosco_m68k/blob/master/LICENCE.hardware.txt
OSHWA UK000006 (https://certification.oshwa.org/uk000006.html)
The Really Old-School Company Limited
Sheet: /DUART/
File: DUART.kicad_sch
Title: ROSCO_M68K GENERAL PURPOSE MC68010 COMPUTER

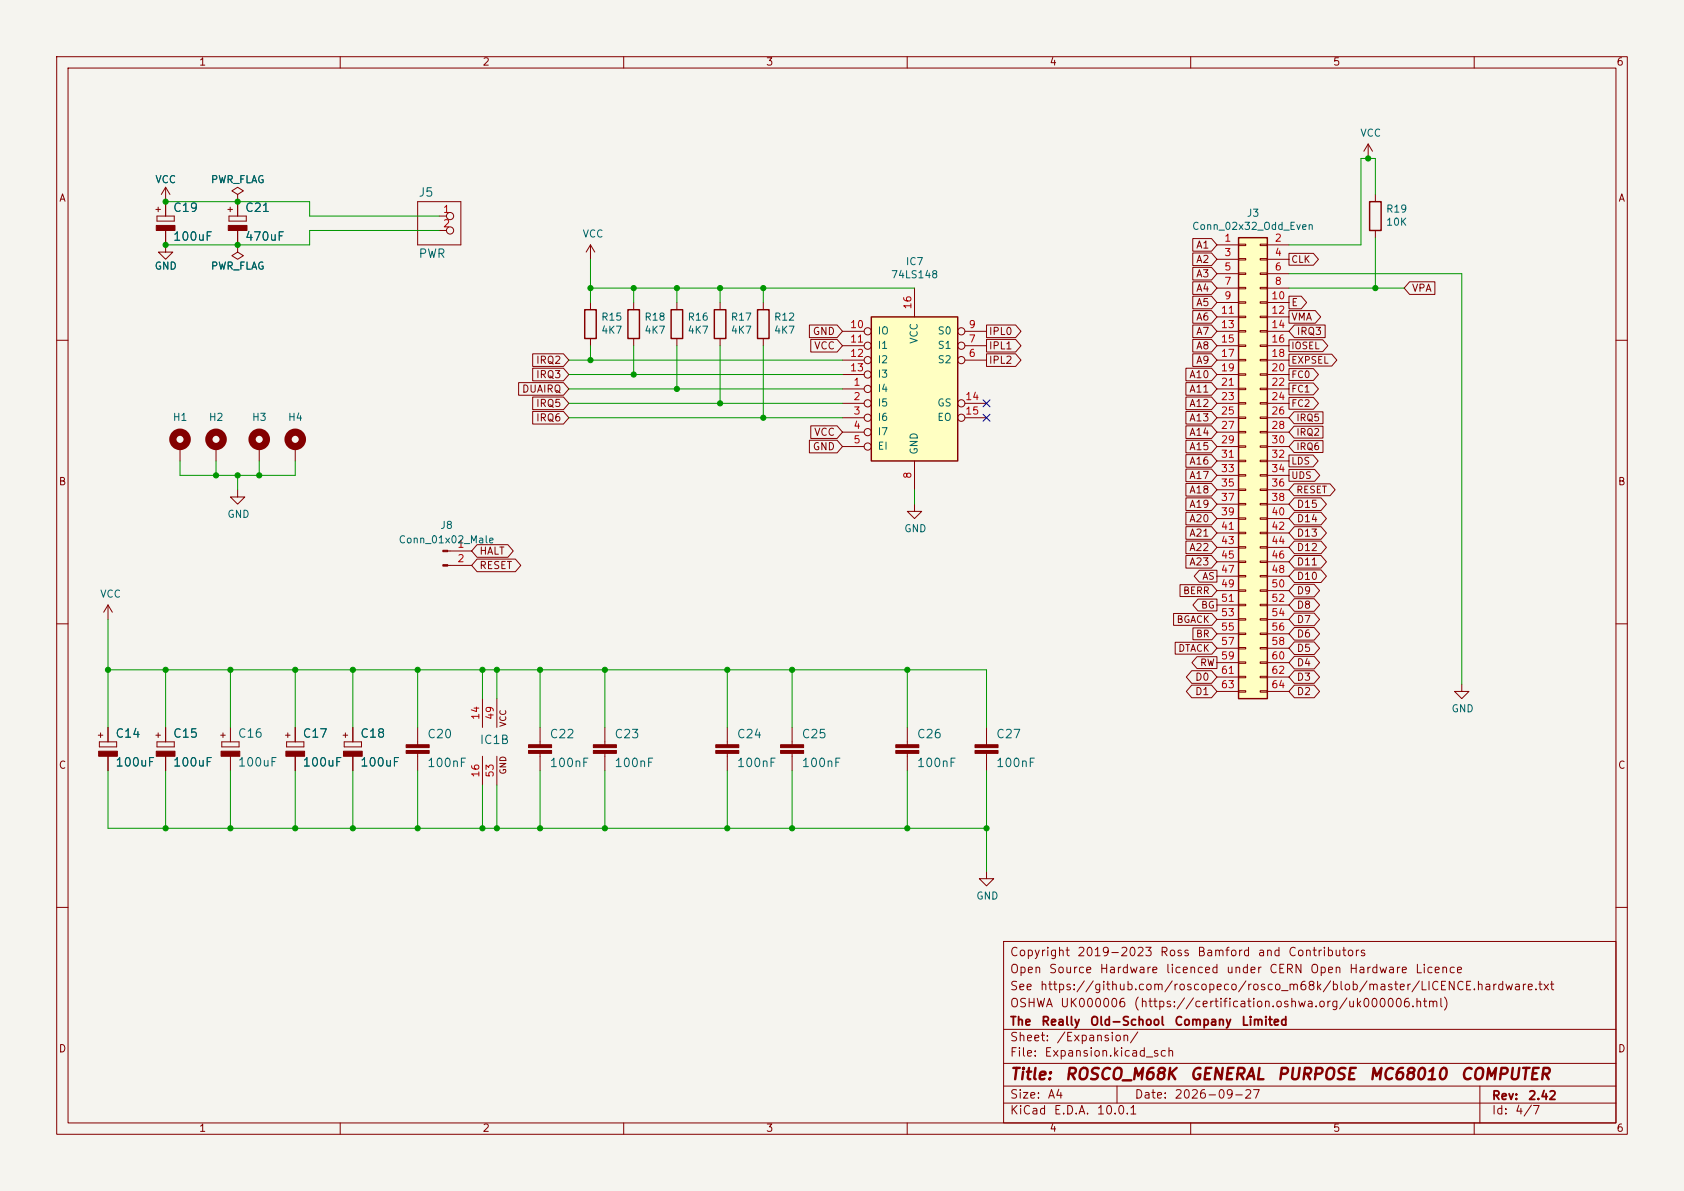
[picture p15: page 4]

Copyright 2019-2023 Ross Bamford and Contributors
Open Source Hardware licenced under CERN Open Hardware Licence
See https://github.com/roscopeco/rosco_m68k/blob/master/LICENCE.hardware.txt
OSHWA UK000006 (https://certification.oshwa.org/uk000006.html)
The Really Old-School Company Limited
Sheet: /Expansion/
File: Expansion.kicad_sch
Title: ROSCO_M68K GENERAL PURPOSE MC68010 COMPUTER

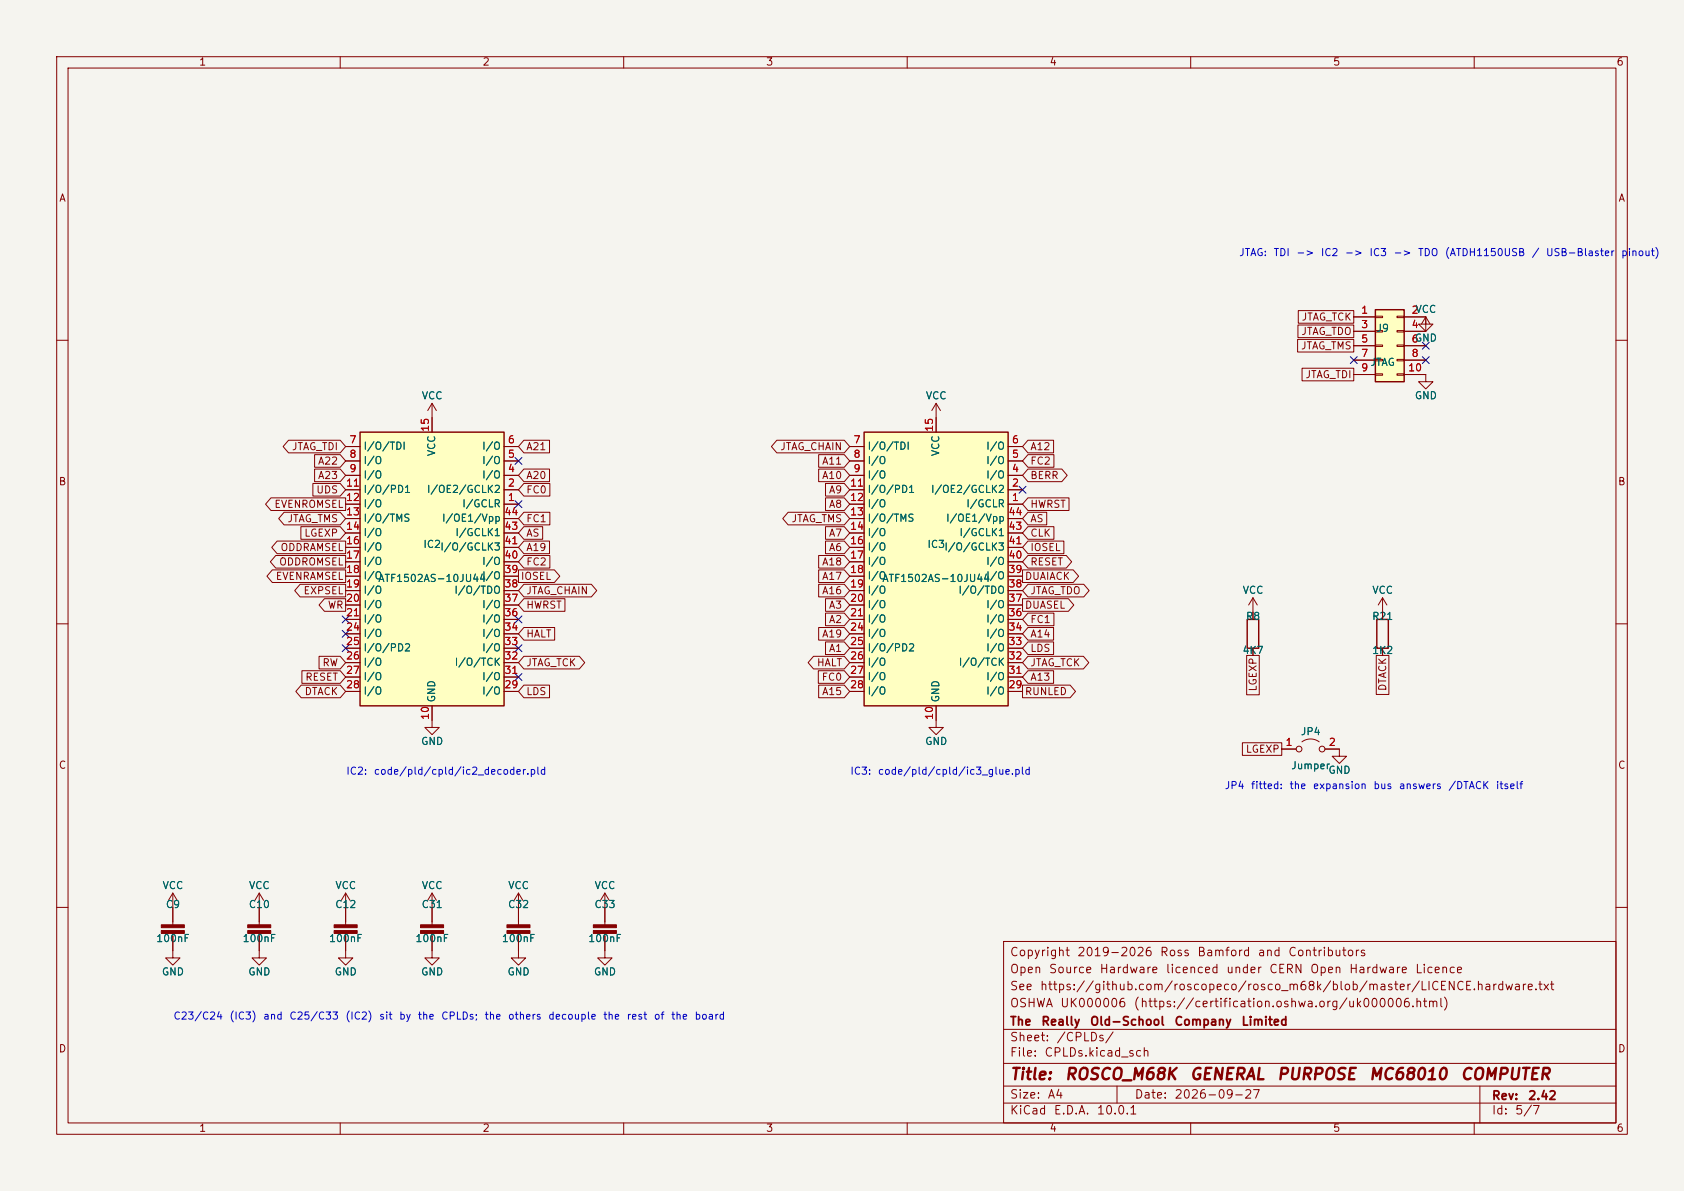
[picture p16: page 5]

JTAG: TDI -> IC2 -> IC3 -> TDO (ATDH1150USB / USB-Blaster pinout) J9

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

JP4 fitted: the expansion bus answers /DTACK itself

Open Source Hardware licenced under CERN Open Hardware Licence
See https://github.com/roscopeco/rosco_m68k/blob/master/LICENCE.hardware.txt
OSHWA UK000006 (https://certification.oshwa.org/uk000006.html)
The Really Old-School Company Limited
Sheet: /CPLDs/
File: CPLDs.kicad_sch
Title: ROSCO_M68K GENERAL PURPOSE MC68010 COMPUTER

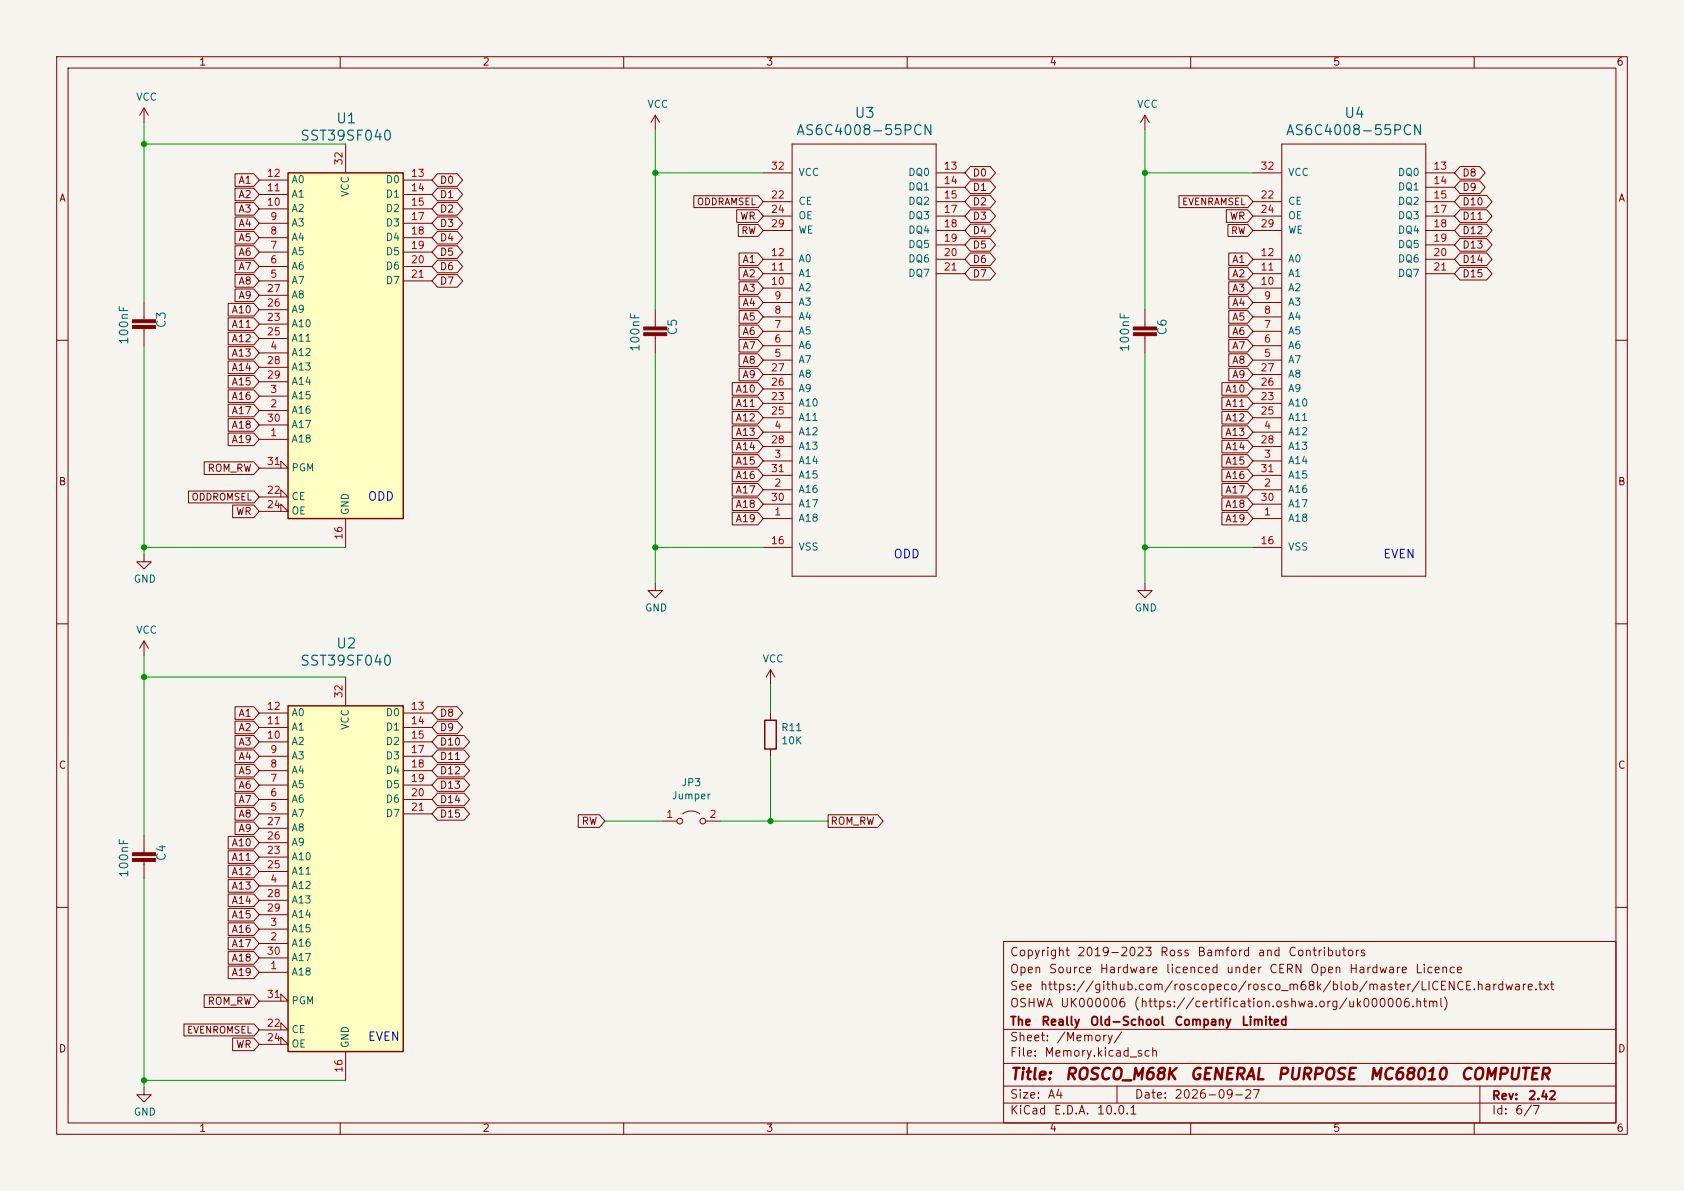
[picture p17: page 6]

Open Source Hardware licenced under CERN Open Hardware Licence
See https://github.com/roscopeco/rosco_m68k/blob/master/LICENCE.hardware.txt
OSHWA UK000006 (https://certification.oshwa.org/uk000006.html)
The Really Old-School Company Limited
Sheet: /Memory/
File: Memory.kicad_sch
Title: ROSCO_M68K GENERAL PURPOSE MC68010 COMPUTER

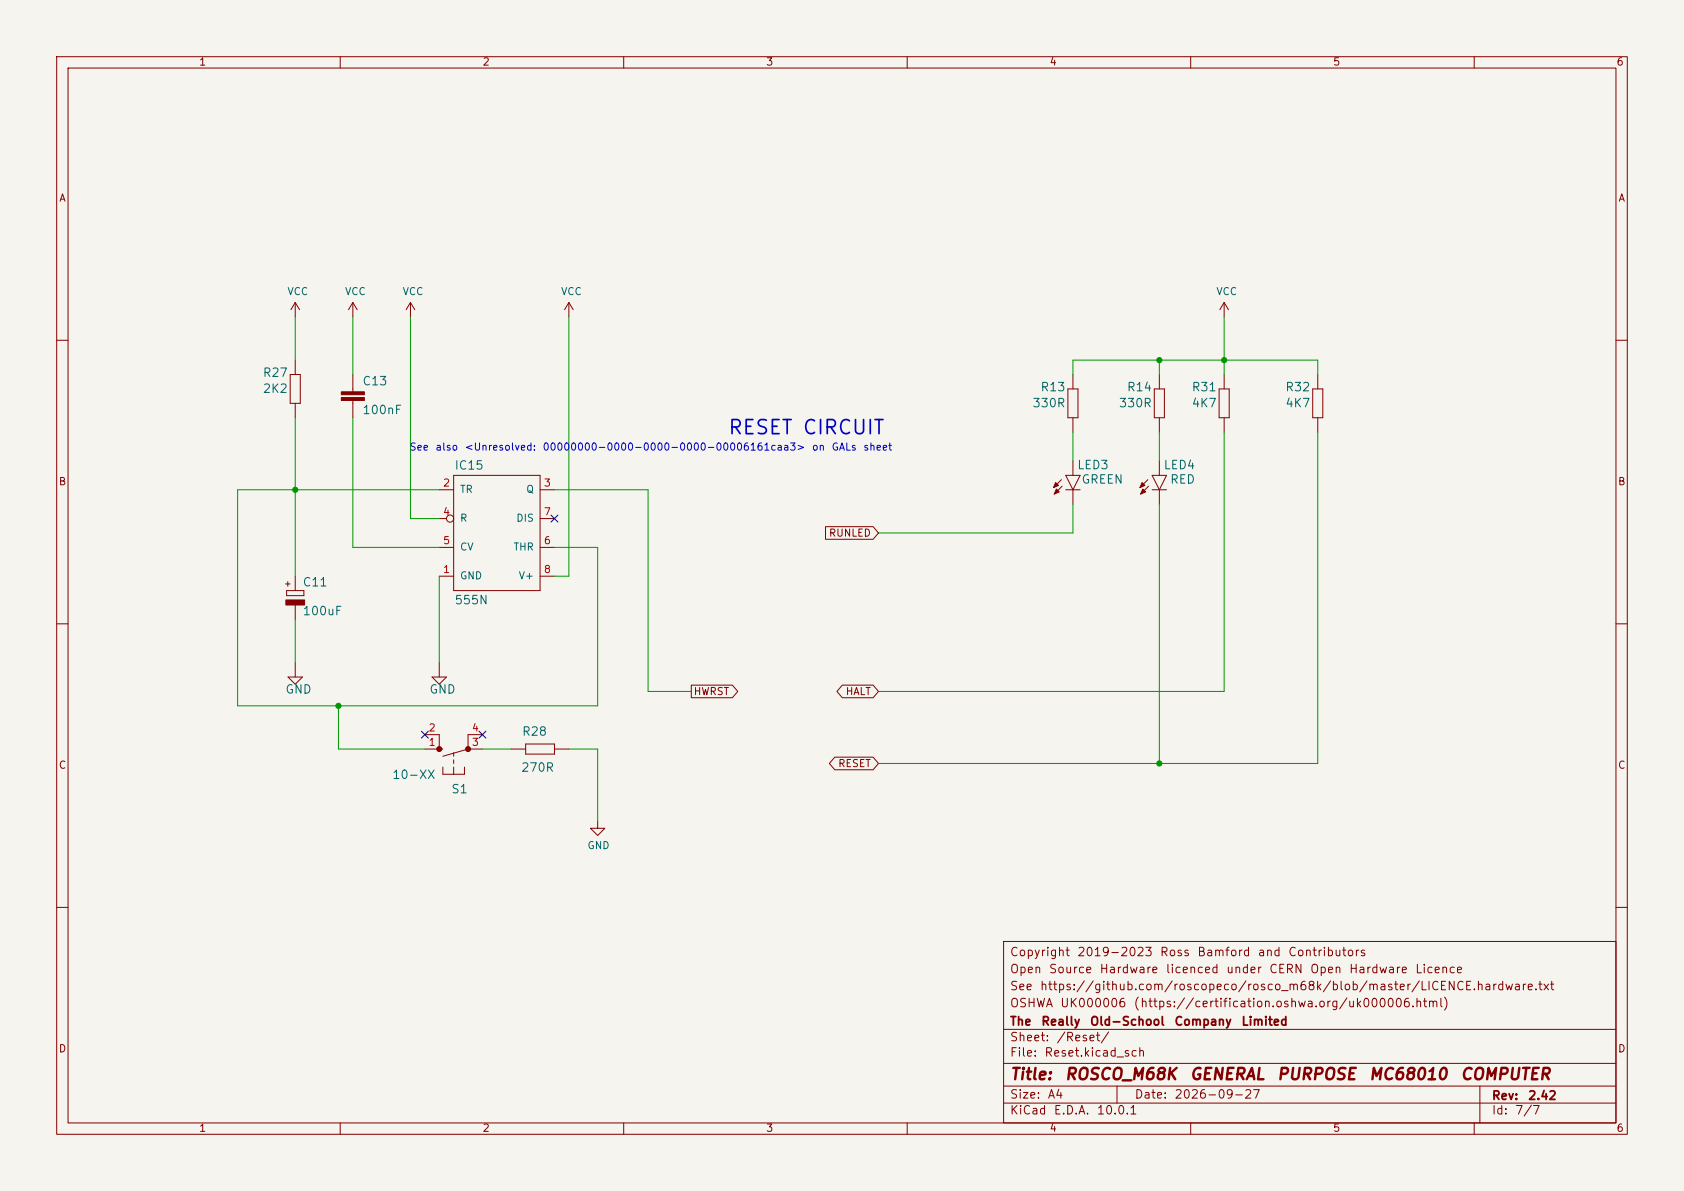
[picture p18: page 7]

Copyright 2019-2023 Ross Bamford and Contributors
Open Source Hardware licenced under CERN Open Hardware Licence
See https://github.com/roscopeco/rosco_m68k/blob/master/LICENCE.hardware.txt
OSHWA UK000006 (https://certification.oshwa.org/uk000006.html)
The Really Old-School Company Limited
Sheet: /Reset/
File: Reset.kicad_sch
Title: ROSCO_M68K GENERAL PURPOSE MC68010 COMPUTER

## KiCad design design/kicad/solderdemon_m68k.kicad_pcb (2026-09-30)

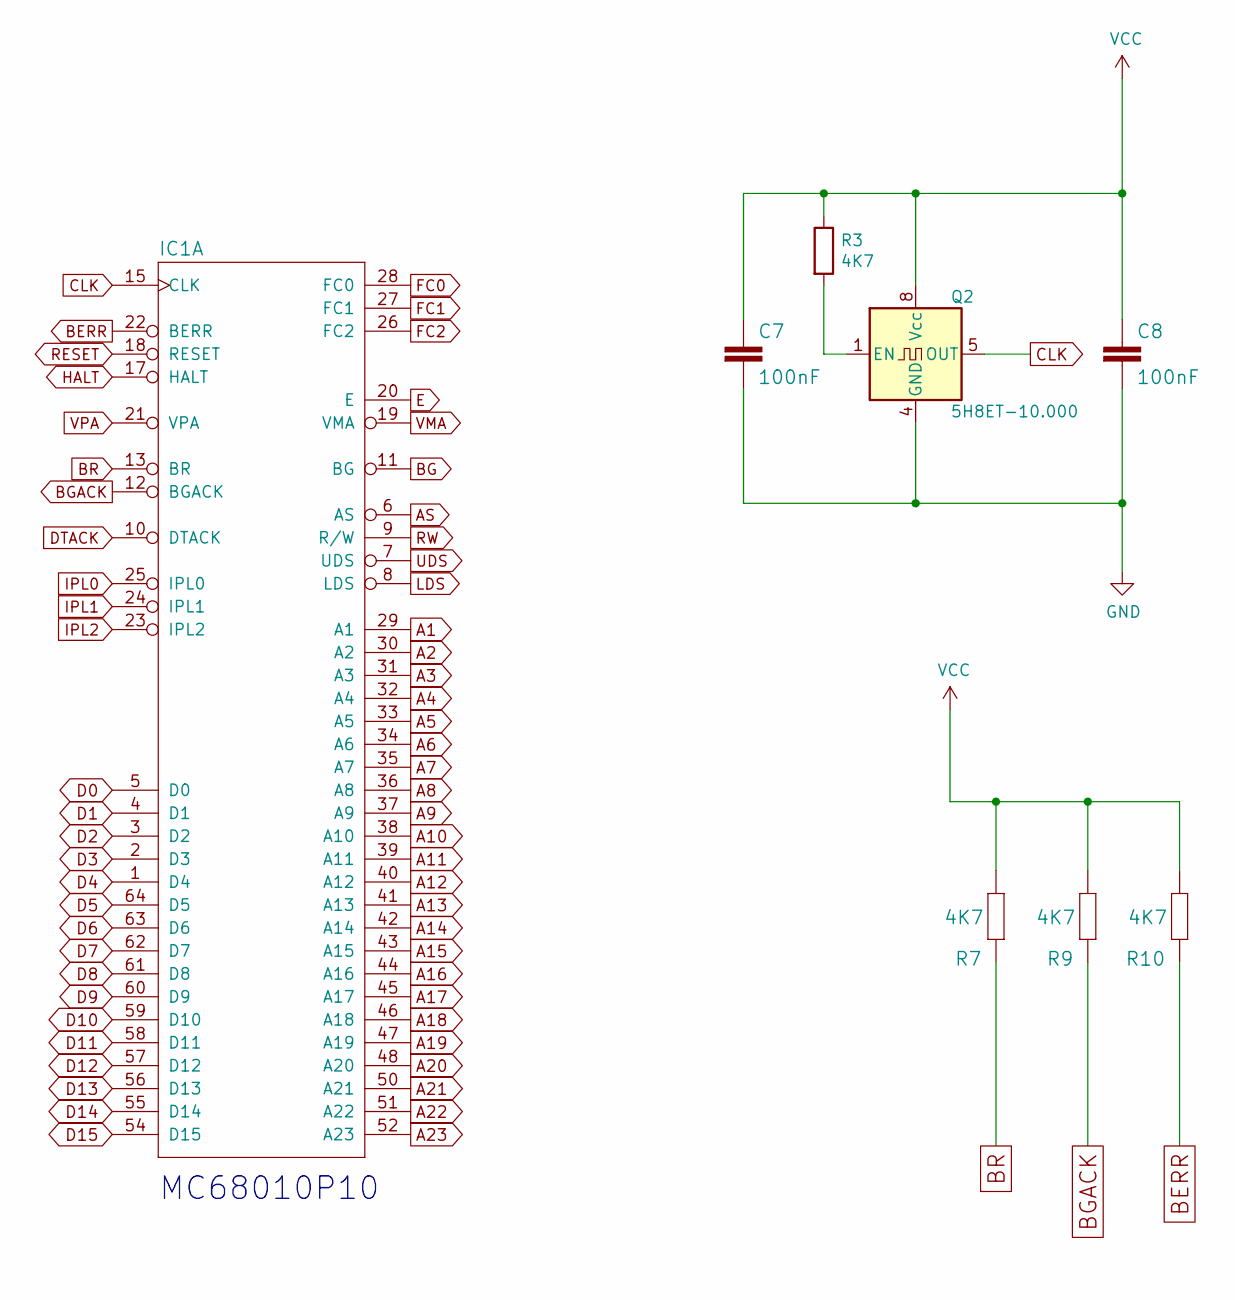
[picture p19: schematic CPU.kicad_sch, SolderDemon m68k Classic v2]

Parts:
C7, C8: 100nF; C2.5-3
IC1: MC68010P10; DIL64
Q2: 5H8ET-10.000; Oscillator_DIP-8
R3, R7, R9, R10: 4K7; 0207_10

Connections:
A1: IC1.29 (A1); also elsewhere on the board
A2: IC1.30 (A2); also elsewhere on the board
A3: IC1.31 (A3); also elsewhere on the board
A4: IC1.32 (A4); also elsewhere on the board
A5: IC1.33 (A5); also elsewhere on the board
A6: IC1.34 (A6); also elsewhere on the board
A7: IC1.35 (A7); also elsewhere on the board
A8: IC1.36 (A8); also elsewhere on the board
A9: IC1.37 (A9); also elsewhere on the board
A10: IC1.38 (A10); also elsewhere on the board
A11: IC1.39 (A11); also elsewhere on the board
A12: IC1.40 (A12); also elsewhere on the board
A13: IC1.41 (A13); also elsewhere on the board
A14: IC1.42 (A14); also elsewhere on the board
A15: IC1.43 (A15); also elsewhere on the board
A16: IC1.44 (A16); also elsewhere on the board
A17: IC1.45 (A17); also elsewhere on the board
A18: IC1.46 (A18); also elsewhere on the board
A19: IC1.47 (A19); also elsewhere on the board
A20: IC1.48 (A20); also elsewhere on the board
A21: IC1.50 (A21); also elsewhere on the board
A22: IC1.51 (A22); also elsewhere on the board
A23: IC1.52 (A23); also elsewhere on the board
AS: IC1.6 (AS); also elsewhere on the board
BERR: IC1.22 (BERR), R10.1; also elsewhere on the board
BG: IC1.11 (BG); also elsewhere on the board
BGACK: IC1.12 (BGACK), R9.1; also elsewhere on the board
BR: IC1.13 (BR), R7.1; also elsewhere on the board
CLK: IC1.15 (CLK), Q2.5 (OUT); also elsewhere on the board
D0: IC1.5 (D0); also elsewhere on the board
D1: IC1.4 (D1); also elsewhere on the board
D2: IC1.3 (D2); also elsewhere on the board
D3: IC1.2 (D3); also elsewhere on the board
D4: IC1.1 (D4); also elsewhere on the board
D5: IC1.64 (D5); also elsewhere on the board
D6: IC1.63 (D6); also elsewhere on the board
D7: IC1.62 (D7); also elsewhere on the board
D8: IC1.61 (D8); also elsewhere on the board
D9: IC1.60 (D9); also elsewhere on the board
D10: IC1.59 (D10); also elsewhere on the board
D11: IC1.58 (D11); also elsewhere on the board
D12: IC1.57 (D12); also elsewhere on the board
D13: IC1.56 (D13); also elsewhere on the board
D14: IC1.55 (D14); also elsewhere on the board
D15: IC1.54 (D15); also elsewhere on the board
DTACK: IC1.10 (DTACK); also elsewhere on the board
E: IC1.20 (E); also elsewhere on the board
FC0: IC1.28 (FC0); also elsewhere on the board
FC1: IC1.27 (FC1); also elsewhere on the board
FC2: IC1.26 (FC2); also elsewhere on the board
GND: C7.2, C8.2, Q2.4 (GND); also elsewhere on the board
HALT: IC1.17 (HALT); also elsewhere on the board
IPL0: IC1.25 (IPL0); also elsewhere on the board
IPL1: IC1.24 (IPL1); also elsewhere on the board
IPL2: IC1.23 (IPL2); also elsewhere on the board
LDS: IC1.8 (LDS); also elsewhere on the board
unnamed: Q2.1 (EN), R3.2
RESET: IC1.18 (RESET); also elsewhere on the board
RW: IC1.9 (R/W); also elsewhere on the board
UDS: IC1.7 (UDS); also elsewhere on the board
VCC: C7.1, C8.1, Q2.8 (Vcc), R3.1, R7.2, R9.2, R10.2; also elsewhere on the board
VMA: IC1.19 (VMA); also elsewhere on the board
VPA: IC1.21 (VPA); also elsewhere on the board

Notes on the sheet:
MC68010P10

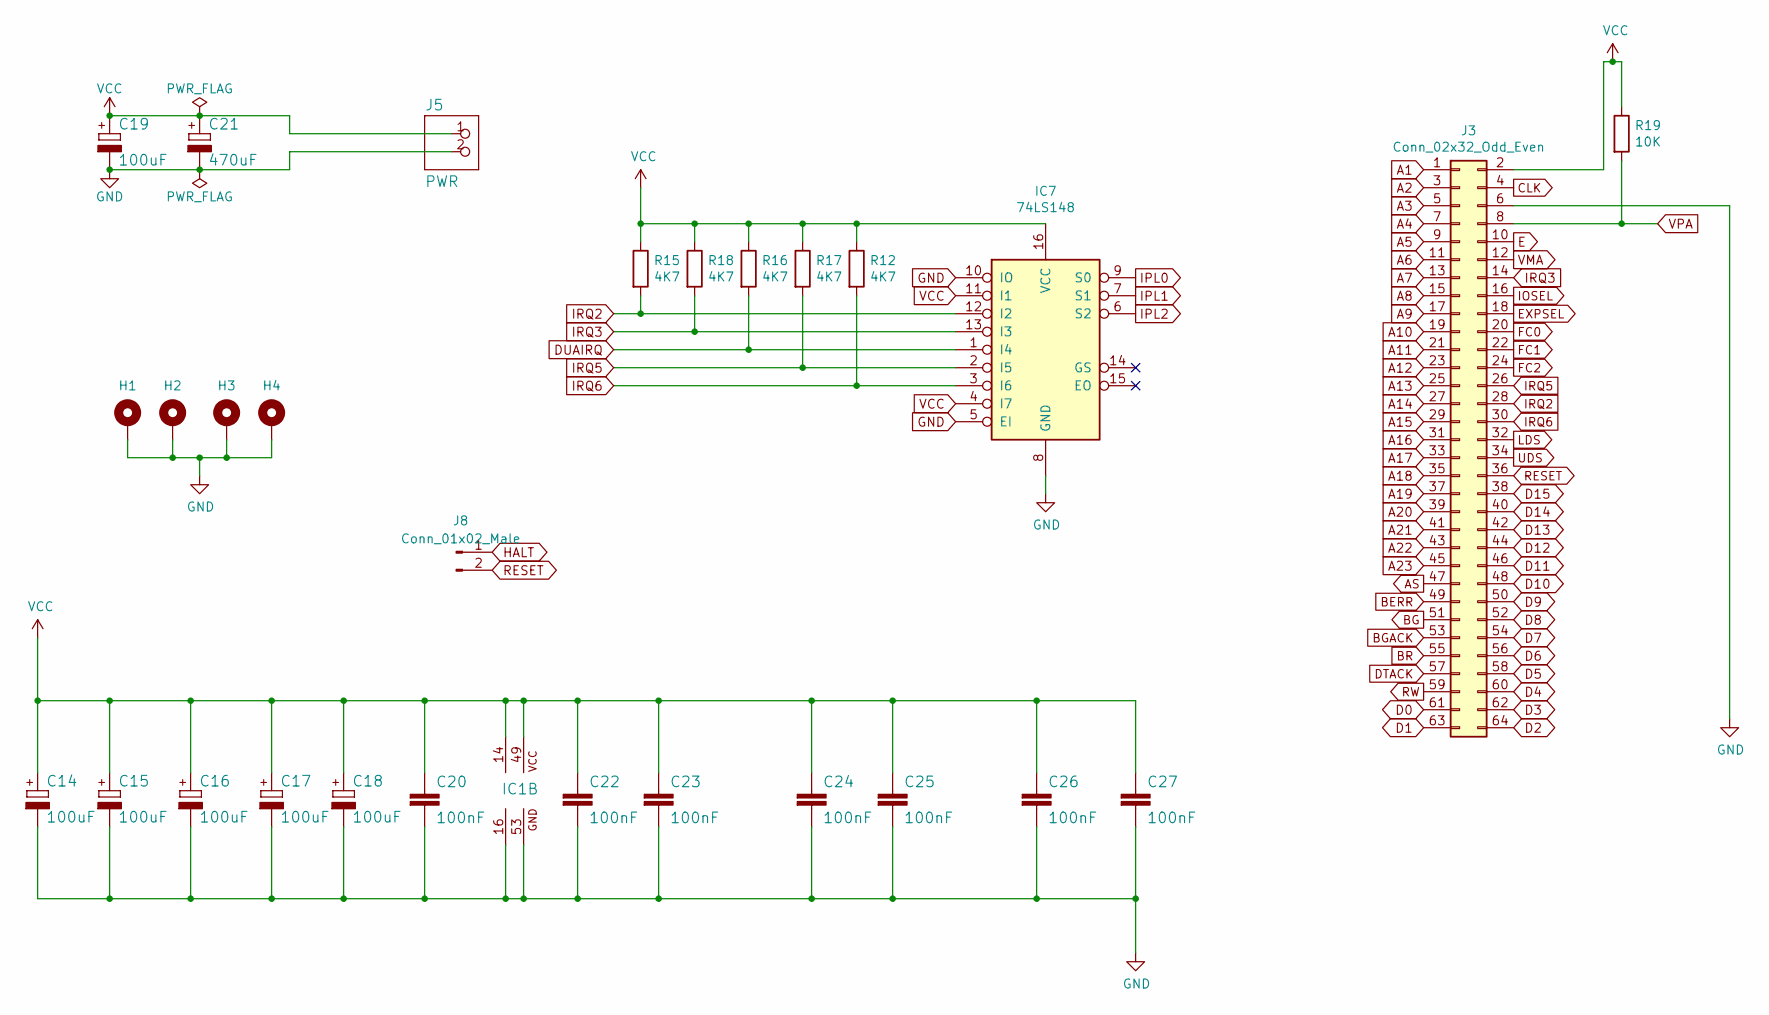
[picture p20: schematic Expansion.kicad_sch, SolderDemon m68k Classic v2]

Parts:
C14, C15, C16, C17, C18, C19: 100uF; E2,5-5
C20, C22, C23, C24, C25, C26, C27: 100nF; C2.5-3
C21: 470uF; E3,5-10
H1, H2, H3, H4: MountingHole; MountingHole_3.2mm_M3_Pad
IC1: MC68010P10; DIL64
IC7: 74LS148; DIP-16_W7.62mm_LongPads
J3: Conn_02x32_Odd_Even; PinHeader_2x32_P2.54mm_Vertical
J5: PWR; 1X02
J8: Conn_01x02_Male; PinHeader_1x02_P2.54mm_Vertical
R12, R15, R16, R17, R18: 4K7; 0207_10
R19: 10K; 0207_10

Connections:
A1: J3.1; also elsewhere on the board
A2: J3.3; also elsewhere on the board
A3: J3.5; also elsewhere on the board
A4: J3.7; also elsewhere on the board
A5: J3.9; also elsewhere on the board
A6: J3.11; also elsewhere on the board
A7: J3.13; also elsewhere on the board
A8: J3.15; also elsewhere on the board
A9: J3.17; also elsewhere on the board
A10: J3.19; also elsewhere on the board
A11: J3.21; also elsewhere on the board
A12: J3.23; also elsewhere on the board
A13: J3.25; also elsewhere on the board
A14: J3.27; also elsewhere on the board
A15: J3.29; also elsewhere on the board
A16: J3.31; also elsewhere on the board
A17: J3.33; also elsewhere on the board
A18: J3.35; also elsewhere on the board
A19: J3.37; also elsewhere on the board
A20: J3.39; also elsewhere on the board
A21: J3.41; also elsewhere on the board
A22: J3.43; also elsewhere on the board
A23: J3.45; also elsewhere on the board
AS: J3.47; also elsewhere on the board
BERR: J3.49; also elsewhere on the board
BG: J3.51; also elsewhere on the board
BGACK: J3.53; also elsewhere on the board
BR: J3.55; also elsewhere on the board
CLK: J3.4; also elsewhere on the board
D0: J3.61; also elsewhere on the board
D1: J3.63; also elsewhere on the board
D2: J3.64; also elsewhere on the board
D3: J3.62; also elsewhere on the board
D4: J3.60; also elsewhere on the board
D5: J3.58; also elsewhere on the board
D6: J3.56; also elsewhere on the board
D7: J3.54; also elsewhere on the board
D8: J3.52; also elsewhere on the board
D9: J3.50; also elsewhere on the board
D10: J3.48; also elsewhere on the board
D11: J3.46; also elsewhere on the board
D12: J3.44; also elsewhere on the board
D13: J3.42; also elsewhere on the board
D14: J3.40; also elsewhere on the board
D15: J3.38; also elsewhere on the board
DTACK: J3.57; also elsewhere on the board
DUAIRQ: IC7.1 (I4), R16.2; also elsewhere on the board
E: J3.10; also elsewhere on the board
EXPSEL: J3.18; also elsewhere on the board
FC0: J3.20; also elsewhere on the board
FC1: J3.22; also elsewhere on the board
FC2: J3.24; also elsewhere on the board
GND: C14.-, C15.-, C16.-, C17.-, C18.-, C19.-, C20.2, C21.-, C22.2, C23.2, C24.2, C25.2, C26.2, C27.2, H1.1, H2.1, H3.1, H4.1, IC1.16 (GND@1), IC1.53 (GND@2), IC7.5 (EI), IC7.8 (GND), IC7.10 (IO), J3.6, J5.2; also elsewhere on the board
HALT: J8.1; also elsewhere on the board
IOSEL: J3.16; also elsewhere on the board
IPL0: IC7.9 (S0); also elsewhere on the board
IPL1: IC7.7 (S1); also elsewhere on the board
IPL2: IC7.6 (S2); also elsewhere on the board
IRQ2: IC7.12 (I2), J3.28, R15.2
IRQ3: IC7.13 (I3), J3.14, R18.2
IRQ5: IC7.2 (I5), J3.26, R17.2
IRQ6: IC7.3 (I6), J3.30, R12.2
LDS: J3.32; also elsewhere on the board
RESET: J3.36, J8.2; also elsewhere on the board
RW: J3.59; also elsewhere on the board
UDS: J3.34; also elsewhere on the board
VCC: C14.+, C15.+, C16.+, C17.+, C18.+, C19.+, C20.1, C21.+, C22.1, C23.1, C24.1, C25.1, C26.1, C27.1, IC1.14 (VCC@1), IC1.49 (VCC@2), IC7.4 (I7), IC7.11 (I1), IC7.16 (VCC), J3.2, J5.1, R12.1, R15.1, R16.1, R17.1, R18.1, R19.1; also elsewhere on the board
VMA: J3.12; also elsewhere on the board
VPA: J3.8, R19.2; also elsewhere on the board

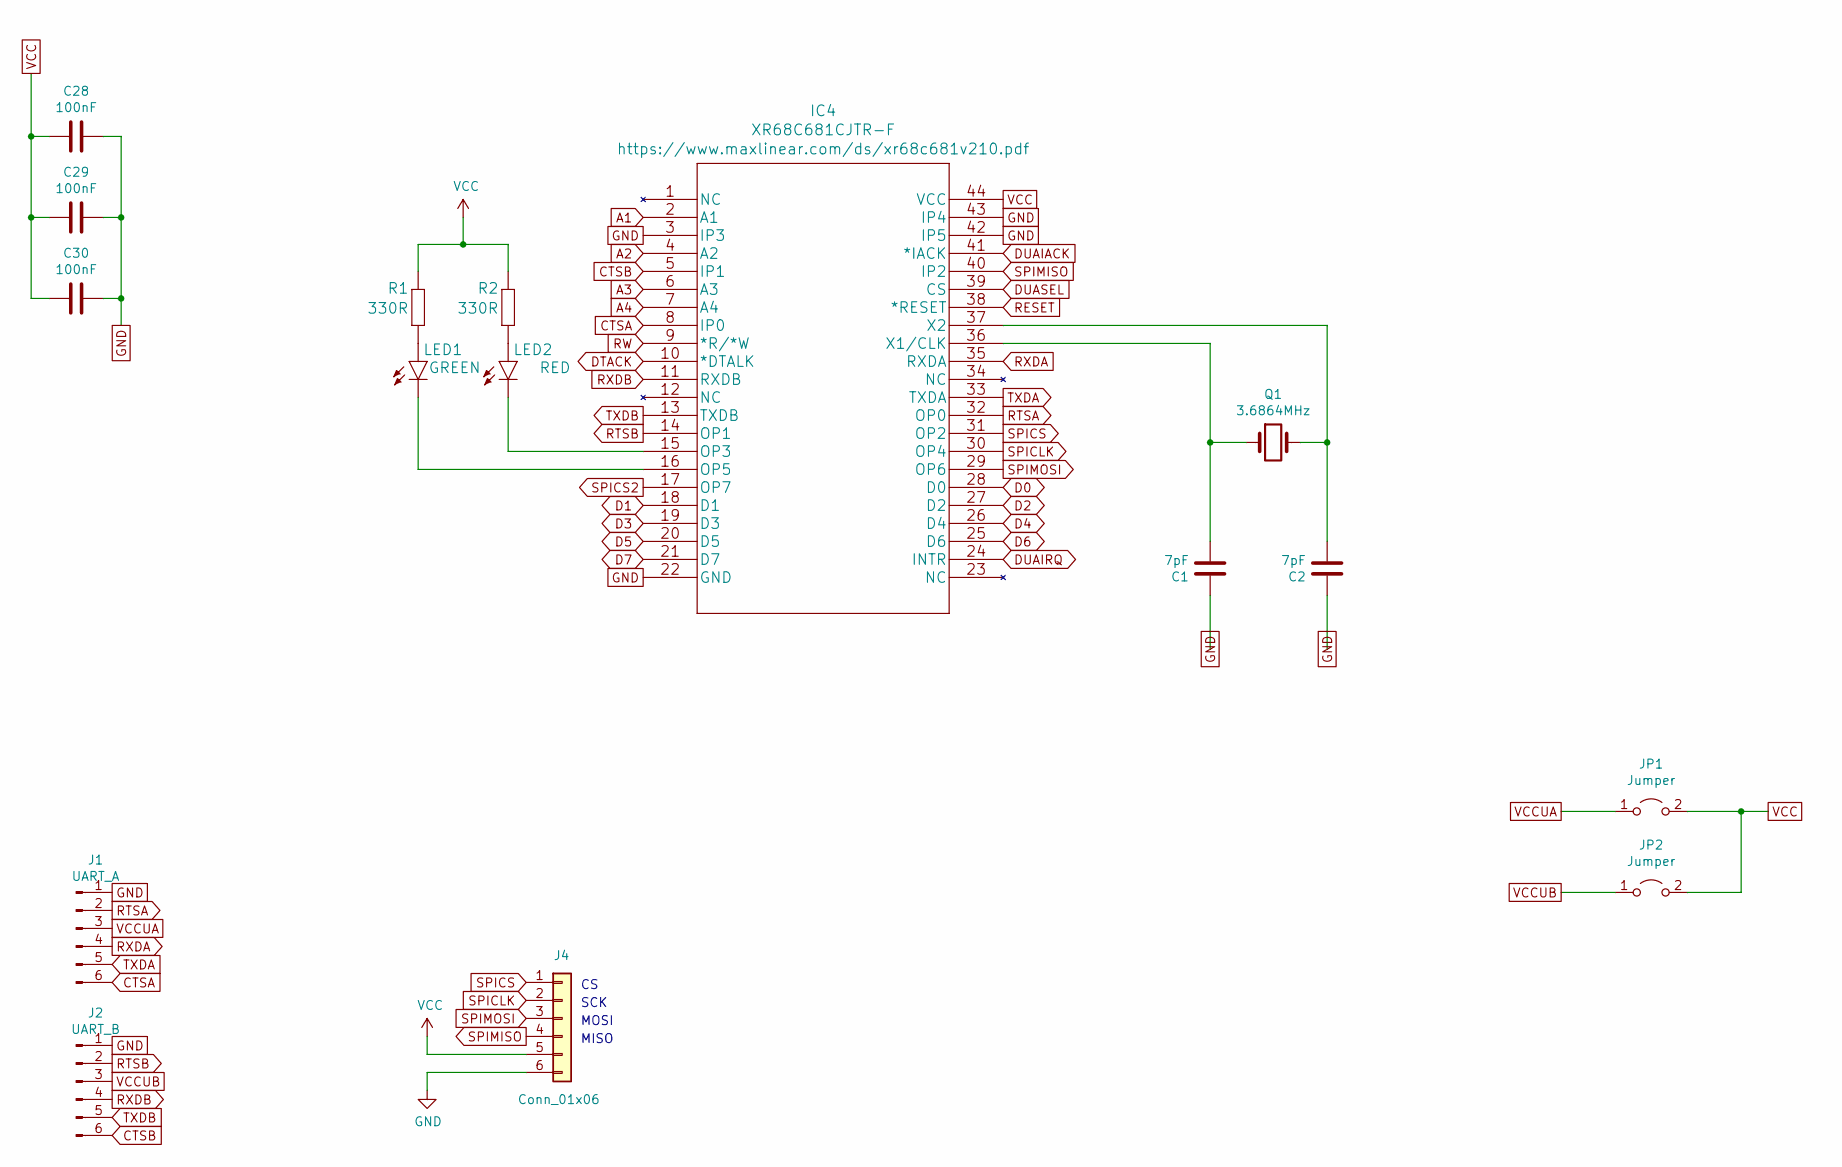
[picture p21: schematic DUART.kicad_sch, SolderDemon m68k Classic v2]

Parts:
C1, C2: 7pF; C2.5_or_3.5-3
C28, C29, C30: 100nF; C2.5-3
IC4: XR68C681CJTR-F; PLCC-44_THT-Socket
J1: UART_A; 1X06
J2: UART_B; 1X06
J4: Conn_01x06; 1X06
JP1, JP2: Jumper; 1X02
LED1: GREEN; LED5MM
LED2: RED; LED5MM
Q1: 3.6864MHz; Crystal_HC49-4H_Vertical
R1, R2: 330R; 0207_10

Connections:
A1: IC4.2 (A1); also elsewhere on the board
A2: IC4.4 (A2); also elsewhere on the board
A3: IC4.6 (A3); also elsewhere on the board
A4: IC4.7 (A4); also elsewhere on the board
CTSA: IC4.8 (IP0), J1.6
CTSB: IC4.5 (IP1), J2.6
D0: IC4.28 (D0); also elsewhere on the board
D1: IC4.18 (D1); also elsewhere on the board
D2: IC4.27 (D2); also elsewhere on the board
D3: IC4.19 (D3); also elsewhere on the board
D4: IC4.26 (D4); also elsewhere on the board
D5: IC4.20 (D5); also elsewhere on the board
D6: IC4.25 (D6); also elsewhere on the board
D7: IC4.21 (D7); also elsewhere on the board
DTACK: IC4.10 (*DTALK); also elsewhere on the board
DUAIACK: IC4.41 (*IACK); also elsewhere on the board
DUAIRQ: IC4.24 (INTR); also elsewhere on the board
DUASEL: IC4.39 (CS); also elsewhere on the board
GND: C1.1, C2.1, C28.1, C29.1, C30.1, IC4.3 (IP3), IC4.22 (GND), IC4.42 (IP5), IC4.43 (IP4), J1.1, J2.1, J4.6; also elsewhere on the board
unnamed: IC4.15 (OP3), LED2.K (C)
unnamed: IC4.16 (OP5), LED1.K (C)
unnamed: C1.2, IC4.36 (X1/CLK), Q1.1
unnamed: C2.2, IC4.37 (X2), Q1.2
unnamed: LED1.A, R1.1
unnamed: LED2.A, R2.1
RESET: IC4.38 (*RESET); also elsewhere on the board
RTSA: IC4.32 (OP0), J1.2
RTSB: IC4.14 (OP1), J2.2
RW: IC4.9 (*R/*W); also elsewhere on the board
RXDA: IC4.35 (RXDA), J1.4
RXDB: IC4.11 (RXDB), J2.4
SPICLK: IC4.30 (OP4), J4.2
SPICS: IC4.31 (OP2), J4.1
SPICS2: IC4.17 (OP7)
SPIMISO: IC4.40 (IP2), J4.4
SPIMOSI: IC4.29 (OP6), J4.3
TXDA: IC4.33 (TXDA), J1.5
TXDB: IC4.13 (TXDB), J2.5
VCC: C28.2, C29.2, C30.2, IC4.44 (VCC), J4.5, JP1.2 (B), JP2.2 (B), R1.2, R2.2; also elsewhere on the board
VCCUA: J1.3, JP1.1 (A)
VCCUB: J2.3, JP2.1 (A)

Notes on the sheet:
MISO
SCK
MOSI

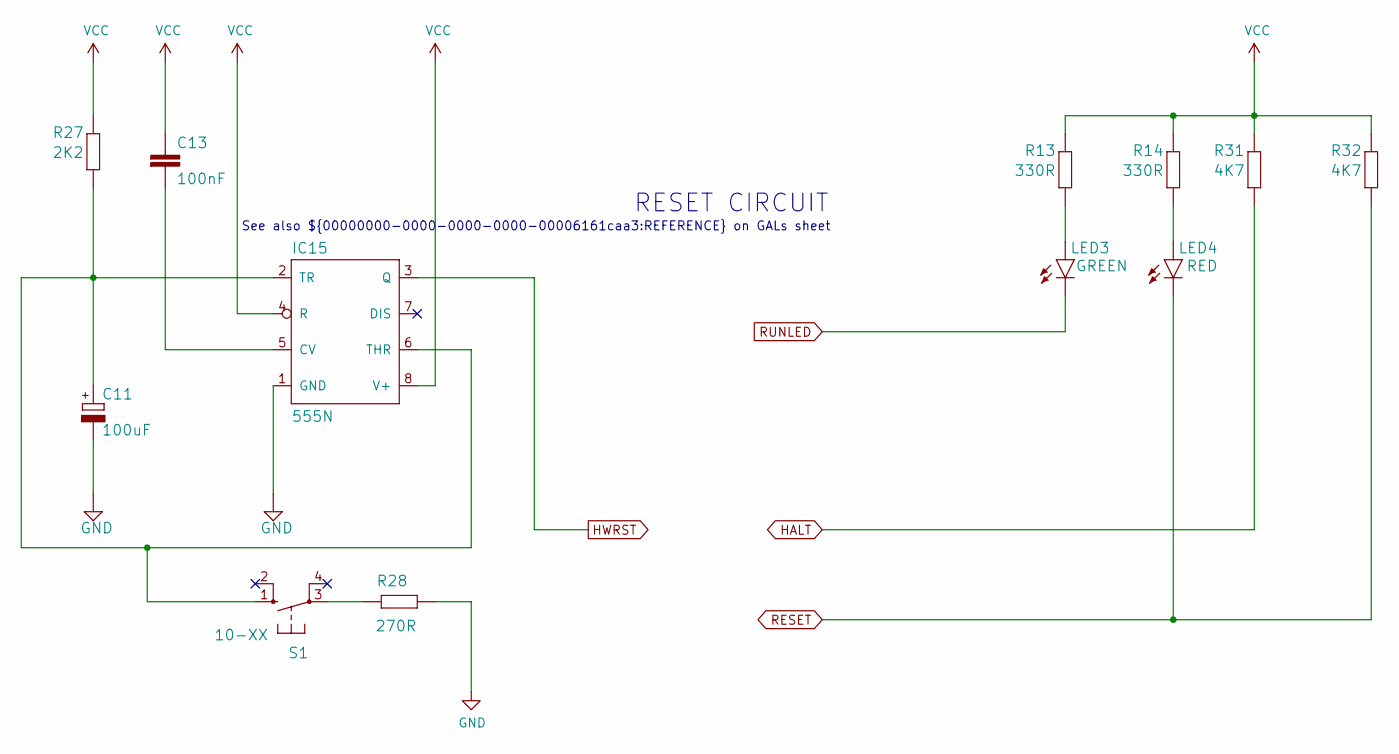
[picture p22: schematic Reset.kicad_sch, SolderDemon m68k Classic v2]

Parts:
C11: 100uF; E2,5-5
C13: 100nF; C2.5-3
IC15: 555N; DIP-8_W7.62mm_LongPads
LED3: GREEN; LED5MM
LED4: RED; LED5MM
R13, R14: 330R; 0207_10
R27: 2K2; 0207_10
R28: 270R; 0207_10
R31, R32: 4K7; 0207_10
S1: 10-XX; B3F-10XX

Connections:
GND: C11.-, IC15.1 (GND), R28.1; also elsewhere on the board
HALT: R31.1; also elsewhere on the board
HWRST: IC15.3 (Q); also elsewhere on the board
unnamed: C13.2, IC15.5 (CV)
unnamed: C11.+, IC15.2 (TR), IC15.6 (THR), R27.1, S1.1 (S)
unnamed: LED3.A, R13.1
unnamed: LED4.A, R14.1
unnamed: R28.2, S1.3
RESET: LED4.K (C), R32.1; also elsewhere on the board
RUNLED: LED3.K (C); also elsewhere on the board
VCC: C13.1, IC15.4 (R), IC15.8 (V+), R13.2, R14.2, R27.2, R31.2, R32.2; also elsewhere on the board

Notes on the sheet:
See also ${00000000-0000-0000-0000-00006161caa3:REFERENCE} on GALs sheet
RESET CIRCUIT

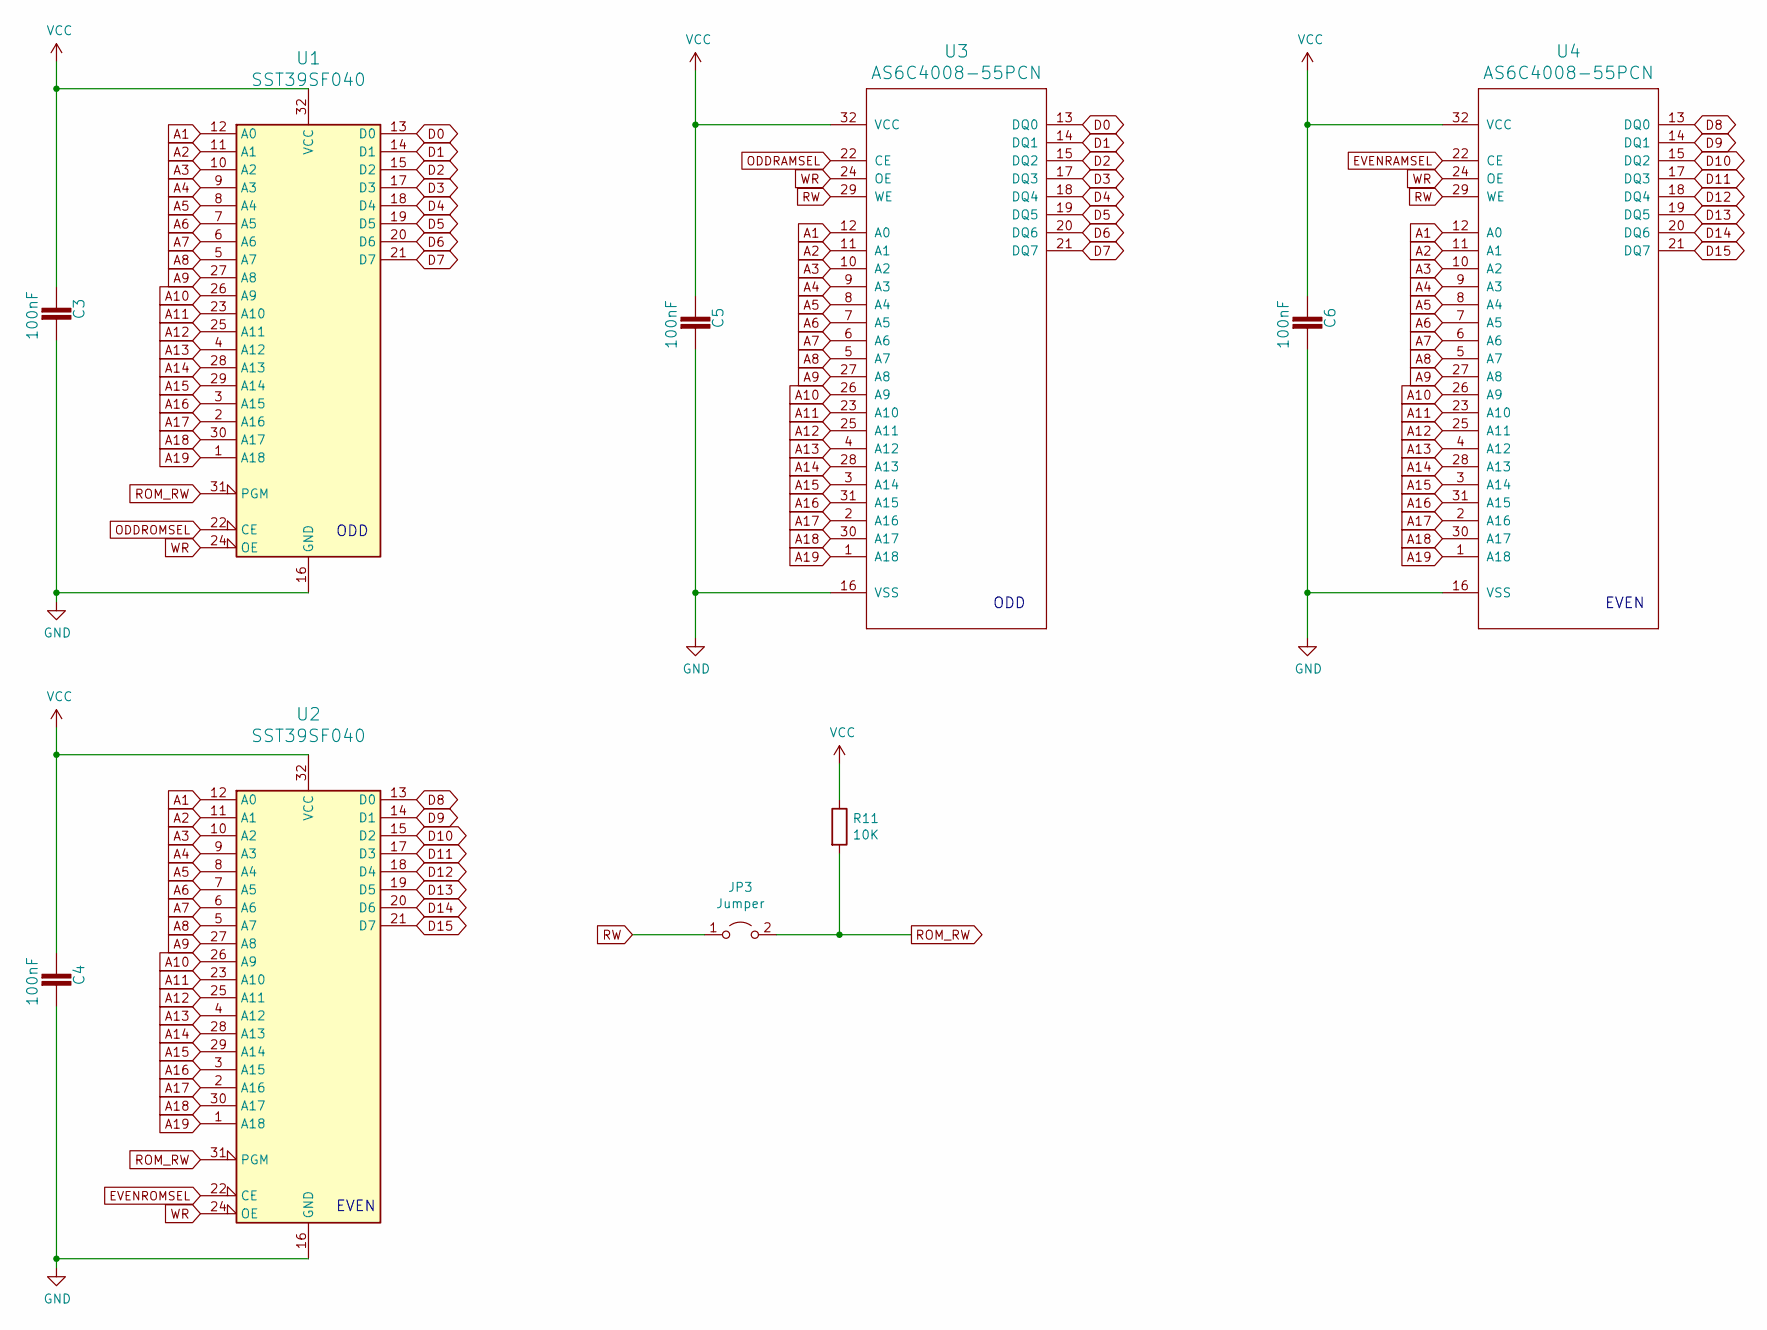
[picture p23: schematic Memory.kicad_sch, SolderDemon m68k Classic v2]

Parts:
C3, C4, C5, C6: 100nF; C2.5-3
JP3: Jumper; 1X02
R11: 10K; 0207_10
U1, U2: SST39SF040; DIP-32_W15.24mm_LongPads
U3, U4: AS6C4008-55PCN; DIP-32_W15.24mm_LongPads

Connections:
A1: U1.12 (A0), U2.12 (A0), U3.12 (A0), U4.12 (A0); also elsewhere on the board
A2: U1.11 (A1), U2.11 (A1), U3.11 (A1), U4.11 (A1); also elsewhere on the board
A3: U1.10 (A2), U2.10 (A2), U3.10 (A2), U4.10 (A2); also elsewhere on the board
A4: U1.9 (A3), U2.9 (A3), U3.9 (A3), U4.9 (A3); also elsewhere on the board
A5: U1.8 (A4), U2.8 (A4), U3.8 (A4), U4.8 (A4); also elsewhere on the board
A6: U1.7 (A5), U2.7 (A5), U3.7 (A5), U4.7 (A5); also elsewhere on the board
A7: U1.6 (A6), U2.6 (A6), U3.6 (A6), U4.6 (A6); also elsewhere on the board
A8: U1.5 (A7), U2.5 (A7), U3.5 (A7), U4.5 (A7); also elsewhere on the board
A9: U1.27 (A8), U2.27 (A8), U3.27 (A8), U4.27 (A8); also elsewhere on the board
A10: U1.26 (A9), U2.26 (A9), U3.26 (A9), U4.26 (A9); also elsewhere on the board
A11: U1.23 (A10), U2.23 (A10), U3.23 (A10), U4.23 (A10); also elsewhere on the board
A12: U1.25 (A11), U2.25 (A11), U3.25 (A11), U4.25 (A11); also elsewhere on the board
A13: U1.4 (A12), U2.4 (A12), U3.4 (A12), U4.4 (A12); also elsewhere on the board
A14: U1.28 (A13), U2.28 (A13), U3.28 (A13), U4.28 (A13); also elsewhere on the board
A15: U1.29 (A14), U2.29 (A14), U3.3 (A14), U4.3 (A14); also elsewhere on the board
A16: U1.3 (A15), U2.3 (A15), U3.31 (A15), U4.31 (A15); also elsewhere on the board
A17: U1.2 (A16), U2.2 (A16), U3.2 (A16), U4.2 (A16); also elsewhere on the board
A18: U1.30 (A17), U2.30 (A17), U3.30 (A17), U4.30 (A17); also elsewhere on the board
A19: U1.1 (A18), U2.1 (A18), U3.1 (A18), U4.1 (A18); also elsewhere on the board
D0: U1.13 (D0), U3.13 (DQ0); also elsewhere on the board
D1: U1.14 (D1), U3.14 (DQ1); also elsewhere on the board
D2: U1.15 (D2), U3.15 (DQ2); also elsewhere on the board
D3: U1.17 (D3), U3.17 (DQ3); also elsewhere on the board
D4: U1.18 (D4), U3.18 (DQ4); also elsewhere on the board
D5: U1.19 (D5), U3.19 (DQ5); also elsewhere on the board
D6: U1.20 (D6), U3.20 (DQ6); also elsewhere on the board
D7: U1.21 (D7), U3.21 (DQ7); also elsewhere on the board
D8: U2.13 (D0), U4.13 (DQ0); also elsewhere on the board
D9: U2.14 (D1), U4.14 (DQ1); also elsewhere on the board
D10: U2.15 (D2), U4.15 (DQ2); also elsewhere on the board
D11: U2.17 (D3), U4.17 (DQ3); also elsewhere on the board
D12: U2.18 (D4), U4.18 (DQ4); also elsewhere on the board
D13: U2.19 (D5), U4.19 (DQ5); also elsewhere on the board
D14: U2.20 (D6), U4.20 (DQ6); also elsewhere on the board
D15: U2.21 (D7), U4.21 (DQ7); also elsewhere on the board
EVENRAMSEL: U4.22 (CE); also elsewhere on the board
EVENROMSEL: U2.22 (CE); also elsewhere on the board
GND: C3.2, C4.2, C5.2, C6.2, U1.16 (GND), U2.16 (GND), U3.16 (VSS), U4.16 (VSS); also elsewhere on the board
ODDRAMSEL: U3.22 (CE); also elsewhere on the board
ODDROMSEL: U1.22 (CE); also elsewhere on the board
ROM_RW: JP3.2 (B), R11.2, U1.31 (PGM), U2.31 (PGM)
RW: JP3.1 (A), U3.29 (WE), U4.29 (WE); also elsewhere on the board
VCC: C3.1, C4.1, C5.1, C6.1, R11.1, U1.32 (VCC), U2.32 (VCC), U3.32 (VCC), U4.32 (VCC); also elsewhere on the board
WR: U1.24 (OE), U2.24 (OE), U3.24 (OE), U4.24 (OE); also elsewhere on the board

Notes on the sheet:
EVEN
ODD

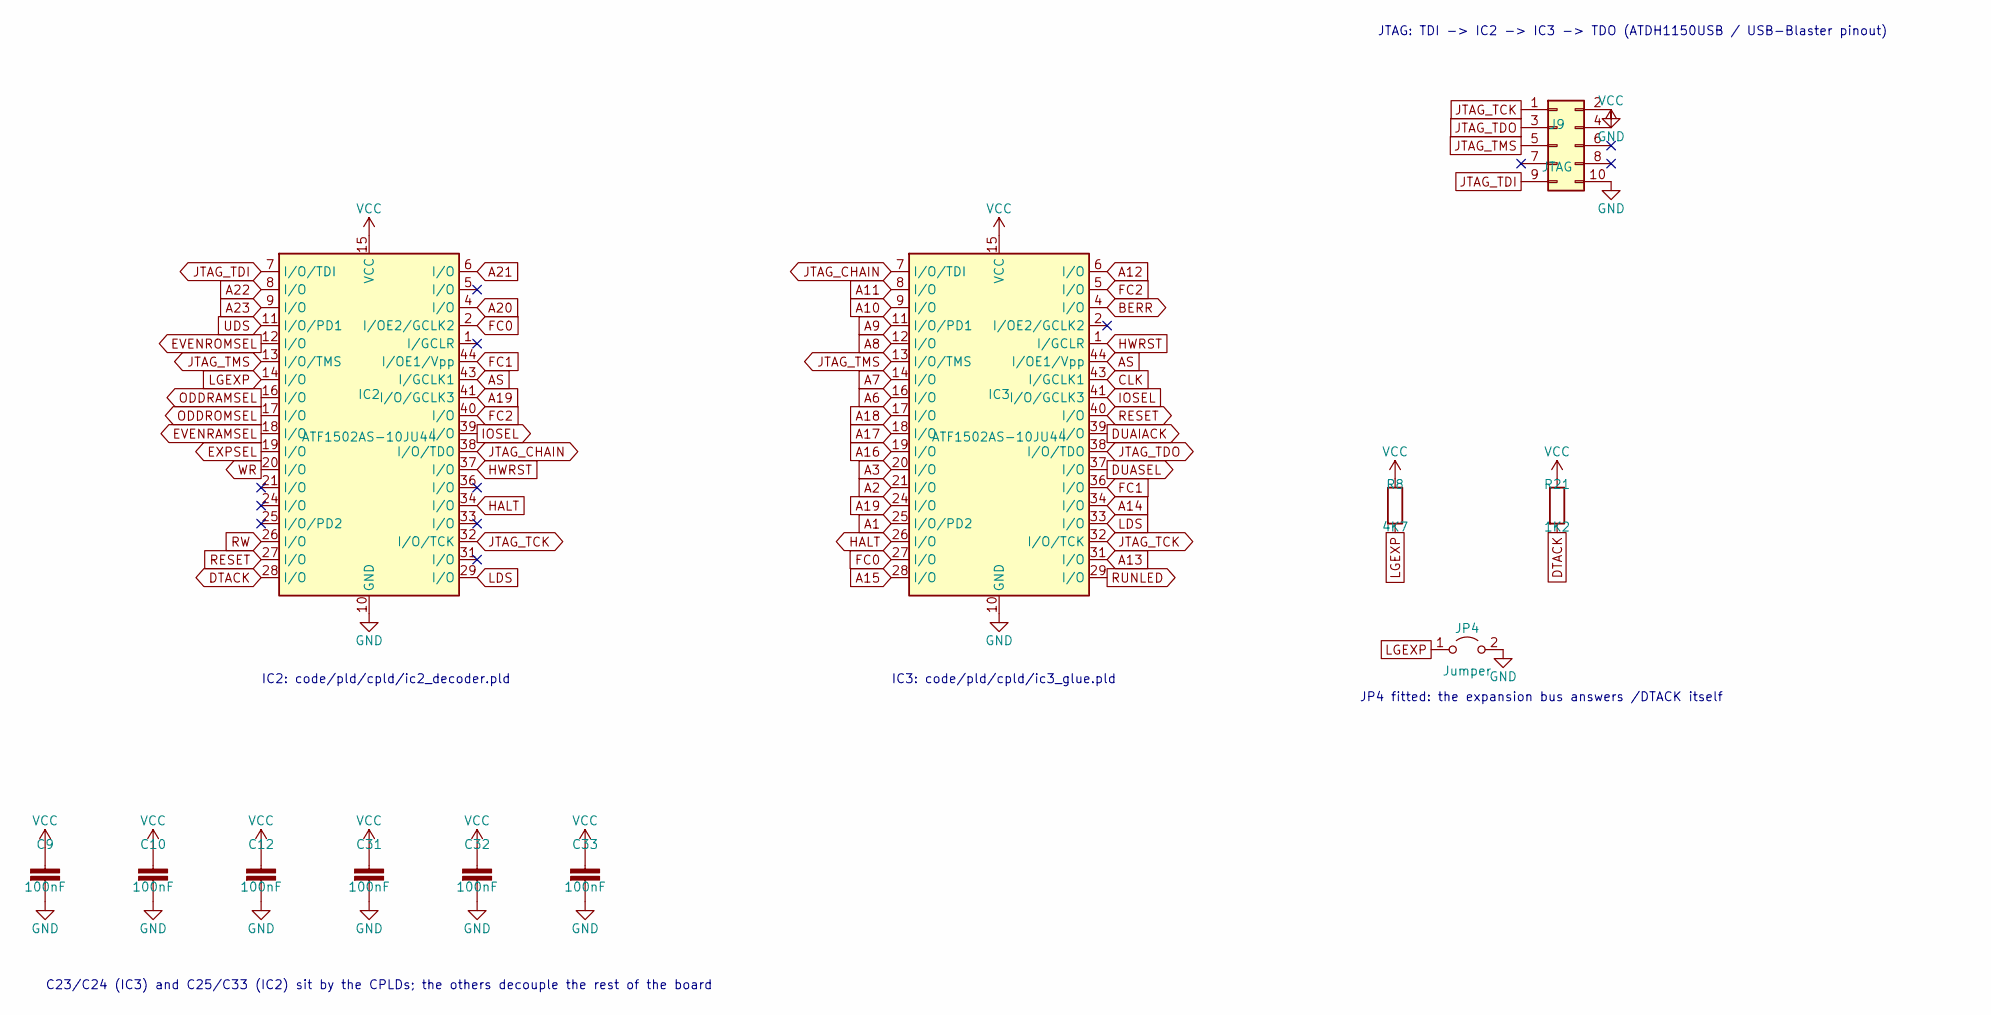
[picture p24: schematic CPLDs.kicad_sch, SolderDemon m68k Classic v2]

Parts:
C9, C10, C12, C31, C32, C33: 100nF; C2.5-3
IC2, IC3: ATF1502AS-10JU44; PLCC-44_THT-Socket
J9: JTAG; PinHeader_2x05_P2.54mm_Vertical
JP4: Jumper; 1X02
R8: 4K7; 0207_10
R21: 1K2; 0207_10

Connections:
A1: IC3.25 (I/O/PD2); also elsewhere on the board
A2: IC3.21 (I/O); also elsewhere on the board
A3: IC3.20 (I/O); also elsewhere on the board
A6: IC3.16 (I/O); also elsewhere on the board
A7: IC3.14 (I/O); also elsewhere on the board
A8: IC3.12 (I/O); also elsewhere on the board
A9: IC3.11 (I/O/PD1); also elsewhere on the board
A10: IC3.9 (I/O); also elsewhere on the board
A11: IC3.8 (I/O); also elsewhere on the board
A12: IC3.6 (I/O); also elsewhere on the board
A13: IC3.31 (I/O); also elsewhere on the board
A14: IC3.34 (I/O); also elsewhere on the board
A15: IC3.28 (I/O); also elsewhere on the board
A16: IC3.19 (I/O); also elsewhere on the board
A17: IC3.18 (I/O); also elsewhere on the board
A18: IC3.17 (I/O); also elsewhere on the board
A19: IC2.41 (I/O/GCLK3), IC3.24 (I/O); also elsewhere on the board
A20: IC2.4 (I/O); also elsewhere on the board
A21: IC2.6 (I/O); also elsewhere on the board
A22: IC2.8 (I/O); also elsewhere on the board
A23: IC2.9 (I/O); also elsewhere on the board
AS: IC2.43 (I/GCLK1), IC3.44 (I/OE1/Vpp); also elsewhere on the board
BERR: IC3.4 (I/O); also elsewhere on the board
CLK: IC3.43 (I/GCLK1); also elsewhere on the board
DTACK: IC2.28 (I/O), R21.2; also elsewhere on the board
DUAIACK: IC3.39 (I/O); also elsewhere on the board
DUASEL: IC3.37 (I/O); also elsewhere on the board
EVENRAMSEL: IC2.18 (I/O); also elsewhere on the board
EVENROMSEL: IC2.12 (I/O); also elsewhere on the board
EXPSEL: IC2.19 (I/O); also elsewhere on the board
FC0: IC2.2 (I/OE2/GCLK2), IC3.27 (I/O); also elsewhere on the board
FC1: IC2.44 (I/OE1/Vpp), IC3.36 (I/O); also elsewhere on the board
FC2: IC2.40 (I/O), IC3.5 (I/O); also elsewhere on the board
GND: C9.2, C10.2, C12.2, C31.2, C32.2, C33.2, IC2.10 (GND), IC2.22 (GND), IC2.30 (GND), IC2.42 (GND), IC3.10 (GND), IC3.22 (GND), IC3.30 (GND), IC3.42 (GND), J9.2, J9.10, JP4.2 (B); also elsewhere on the board
HALT: IC2.34 (I/O), IC3.26 (I/O); also elsewhere on the board
HWRST: IC2.37 (I/O), IC3.1 (I/GCLR); also elsewhere on the board
IOSEL: IC2.39 (I/O), IC3.41 (I/O/GCLK3); also elsewhere on the board
JTAG_CHAIN: IC2.38 (I/O/TDO), IC3.7 (I/O/TDI)
JTAG_TCK: IC2.32 (I/O/TCK), IC3.32 (I/O/TCK), J9.1
JTAG_TDI: IC2.7 (I/O/TDI), J9.9
JTAG_TDO: IC3.38 (I/O/TDO), J9.3
JTAG_TMS: IC2.13 (I/O/TMS), IC3.13 (I/O/TMS), J9.5
LDS: IC2.29 (I/O), IC3.33 (I/O); also elsewhere on the board
LGEXP: IC2.14 (I/O), JP4.1 (A), R8.2
ODDRAMSEL: IC2.16 (I/O); also elsewhere on the board
ODDROMSEL: IC2.17 (I/O); also elsewhere on the board
RESET: IC2.27 (I/O), IC3.40 (I/O); also elsewhere on the board
RUNLED: IC3.29 (I/O); also elsewhere on the board
RW: IC2.26 (I/O); also elsewhere on the board
UDS: IC2.11 (I/O/PD1); also elsewhere on the board
VCC: C9.1, C10.1, C12.1, C31.1, C32.1, C33.1, IC2.3 (VCC), IC2.15 (VCC), IC2.23 (VCC), IC2.35 (VCC), IC3.3 (VCC), IC3.15 (VCC), IC3.23 (VCC), IC3.35 (VCC), J9.4, R8.1, R21.1; also elsewhere on the board
WR: IC2.20 (I/O); also elsewhere on the board

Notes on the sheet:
IC2: code/pld/cpld/ic2_decoder.pld
IC3: code/pld/cpld/ic3_glue.pld
JTAG: TDI -> IC2 -> IC3 -> TDO (ATDH1150USB / USB-Blaster pinout)
C23/C24 (IC3) and C25/C33 (IC2) sit by the CPLDs; the others decouple the rest of the board
JP4 fitted: the expansion bus answers /DTACK itself

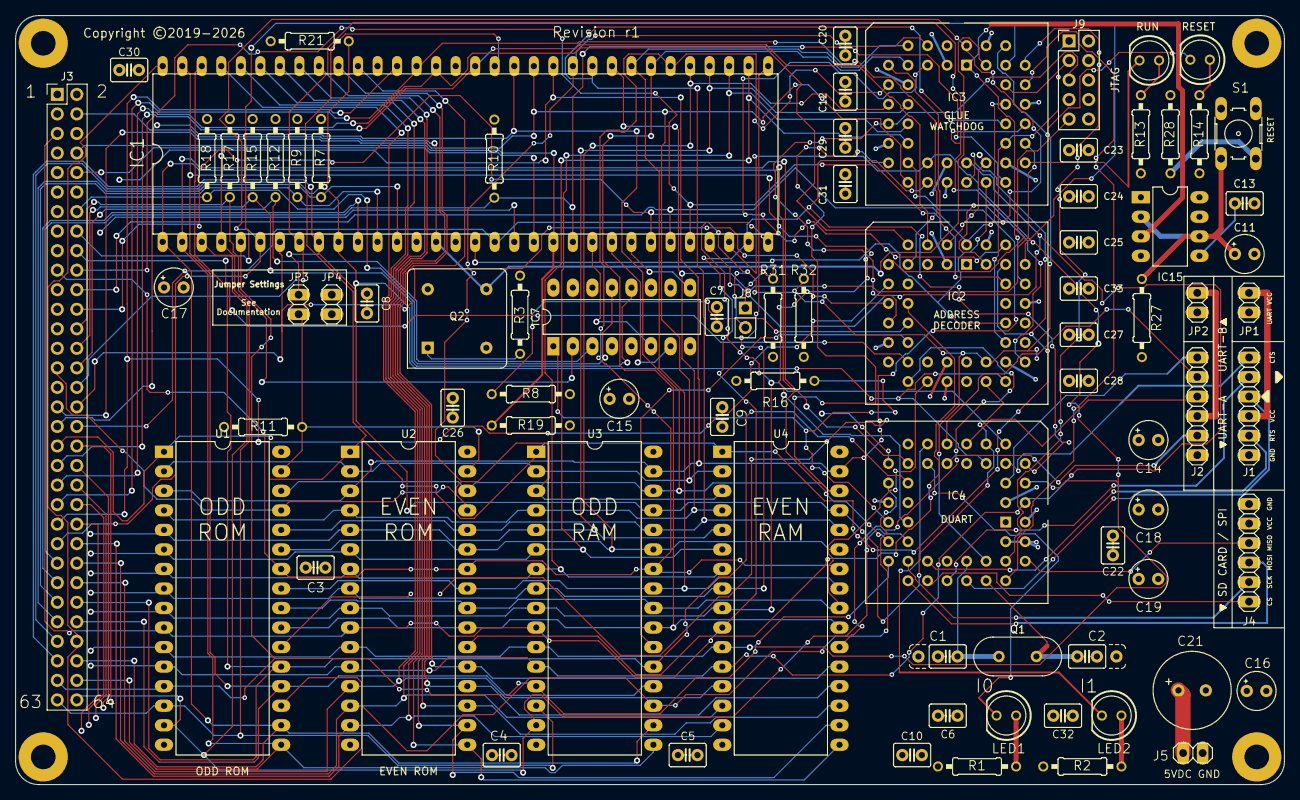
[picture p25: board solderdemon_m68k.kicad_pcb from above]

Board: 4 copper layers, 165.0 x 100.0 mm, 87 parts (1 on the bottom side), 111 nets.

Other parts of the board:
LOGO1: SolderDemon_Logo

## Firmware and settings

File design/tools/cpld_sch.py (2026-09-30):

"""Write the CPLDs sheet of rosco_m68k classic THT r2.14 (it replaces the GALs sheet of r2.13).

The pinout of both ATF1502AS comes from the PIN lines of code/pld/cpld/*.pld -- nothing here
repeats it. Every signal pin carries a global label named after its net, right on the pin end,
so the sheet needs no wires. The parts that already existed on the GALs sheet (the pull-ups R8
and R21, the jumper JP4, the decoupling capacitors, and IC2/IC3 themselves) keep their UUIDs, so
the board's footprints stay linked to them; IC5 and IC6 are gone.

KiCad ships the ATF1502AS only as TQFP-44. The PLCC-44 symbol made here is that symbol with its
pins renumbered: on the 44-pin Atmel/Altera parts PLCC pin = TQFP pin + 6 (mod 44), which the
datasheet's pin table confirms for every fixed pin (VCC 3/15/23/35, GND 10/22/30/42, TDI 7,
TMS 13, TCK 32, TDO 38, GCLK1 43, OE1 44, GCLR 1, OE2/GCLK2 2). It is also written into the
project library rosco_m68k.kicad_sym, which this script creates and adds to sym-lib-table.

    python design/tools/cpld_sch.py
"""
from pathlib import Path
import re, sys, uuid

HERE = Path(__file__).resolve().parent
sys.path.insert(0, str(HERE))
import sexp
from sexp import q

KICAD = HERE.parent / 'kicad'
PLD = HERE.parent.parent / 'code' / 'pld' / 'cpld'
SYMDIR = Path('C:/Program Files/KiCad/10.0/share/kicad/symbols')
OLD = KICAD / 'GALs.kicad_sch'
NEW = KICAD / 'CPLDs.kicad_sch'
ROOT = KICAD / 'solderdemon_m68k.kicad_sch'
PROJECT_LIB = KICAD / 'rosco_m68k.kicad_sym'
LIB_TABLE = KICAD / 'sym-lib-table'

ROOT_UUID = '9031bb33-c6aa-4758-bf5c-3274ed3ebab7'
SHEET_UUID = '00000000-0000-0000-0000-0000617d19f3'
SHEET_FILE_UUID = '5290e0d7-1f24-4c0b-91ff-28c5a304ab9a'
NS = uuid.UUID('3b0c6a8e-5f0e-4d8e-9a57-1f0a1b2c4d14')      # for the new UUIDs, so reruns match

CPLD_LIB = 'rosco_m68k:ATF1502AS-xJx44'
PLCC = 'Package_LCC:PLCC-44_THT-Socket'
VCC_PINS, GND_PINS = (3, 15, 23, 35), (10, 22, 30, 42)
JTAG_PINS = {7: 'JTAG_TDI', 13: 'JTAG_TMS', 32: 'JTAG_TCK', 38: 'JTAG_TDO'}
# TDI of the header goes to IC2, IC2's TDO to IC3's TDI, IC3's TDO back to the header
JTAG_CHAIN = {'IC2': {38: 'JTAG_CHAIN'}, 'IC3': {7: 'JTAG_CHAIN'}}
CHIPS = {  # ref: (CUPL source, uuid kept from r2.13, position)
    'IC2': ('ic2_decoder.pld', '00000000-0000-0000-0000-00006161cada', (76.2, 99.06)),
    'IC3': ('ic3_glue.pld', '00000000-0000-0000-0000-0000616af603', (165.1, 99.06)),
}
# label shapes; every other signal pin is an input
OUTPUT = {'IC2': {'EVENRAMSEL', 'ODDRAMSEL', 'EVENROMSEL', 'ODDROMSEL', 'IOSEL', 'EXPSEL', 'WR'},
          'IC3': {'DUASEL', 'DUAIACK', 'RUNLED'}}
OPEN_DRAIN = {'IC2': {'DTACK'}, 'IC3': {'RESET', 'HALT', 'BERR'}}
# JTAG header, Altera/Atmel 10-pin layout (ATDH1150USB, USB-Blaster)
JTAG_HEADER = {1: 'JTAG_TCK', 2: 'GND', 3: 'JTAG_TDO', 4: 'VCC', 5: 'JTAG_TMS', 6: None, 7: None,
               8: None, 9: 'JTAG_TDI', 10: 'GND'}
# decoupling: r2.13 capacitors keep their UUID; C33 is new. On the board the GAL decoupling
# C23-C25 (on other sheets) now sits by the CPLDs and C33 is IC2's second. (ref, uuid or None)
CAPS = [('C9', '00000000-0000-0000-0000-00006161cac0'), ('C10', '00000000-0000-0000-0000-000061687a3b'),
        ('C12', '00000000-0000-0000-0000-0000616269b3'), ('C31', '00000000-0000-0000-0000-0000616ba5ed'),
        ('C32', '00000000-0000-0000-0000-0000616be28d'), ('C33', None)]
CAP_FP = 'rosco_m68k:C2.5-3'
R_FP = 'rosco_m68k:0207_10'
R8 = '00000000-0000-0000-0000-000061653f75'
R21 = '00000000-0000-0000-0000-000061654750'
JP4 = '00000000-0000-0000-0000-0000617668ac'


def uid(*key):
    return str(uuid.uuid5(NS, '/'.join(key)))


def cupl_pins(name):
    text = re.sub(r'/\*.*?\*/', ' ', (PLD / name).read_text(), flags=re.S)
    return {int(n): s for n, s in re.findall(r'^\s*PIN\s+(\d+)\s*=\s*(\w+)\s*;', text, flags=re.M)}


# ---- library symbols -------------------------------------------------------------------------
def lib_symbol(libfile, name):
    t = sexp.parse((SYMDIR / libfile).read_text(encoding='utf-8'))
    for s in sexp.findall(t, 'symbol'):
        if sexp.unq(s[1]) == name:
            assert not sexp.find(s, 'extends'), f'{name} extends another symbol'
            return s
    raise KeyError(name)


def rename(sym, old, new):
    """Rename a symbol and its unit sub-symbols (NAME_u_s)."""
    sym[1] = q(new)
    for s in sexp.findall(sym, 'symbol'):
        s[1] = q(sexp.unq(s[1]).replace(old, new.split(':')[-1], 1))
    return sym


def set_prop(sym, name, value):
    for p in sexp.findall(sym, 'property'):
        if sexp.unq(p[1]) == name:
            p[2] = q(value)
            return
    raise KeyError(name)


def plcc_symbol():
    s = lib_symbol('CPLD_Microchip.kicad_sym', 'ATF1502AS-xAx44')
    rename(s, 'ATF1502AS-xAx44', 'ATF1502AS-xJx44')
    set_prop(s, 'Value', 'ATF1502AS-xJx44')
    set_prop(s, 'Footprint', PLCC)
    set_prop(s, 'Description', 'Microchip CPLD, 32 Macrocell, 5 V, PLCC-44 (in a through-hole socket)')
    set_prop(s, 'ki_fp_filters', 'PLCC*44*')

    def walk(x):
        for y in x:
            if isinstance(y, list):
                if y[0] == 'pin':
                    num = sexp.find(y, 'number')
                    num[1] = q(str((int(sexp.unq(num[1])) + 6 - 1) % 44 + 1))
                else:
                    walk(y)
    walk(s)
    return s


def pins_of(sym):
    """{number: (x, y, angle)} in symbol coordinates (y up)."""
    out = {}

    def walk(x):
        for y in x:
            if isinstance(y, list):
                if y[0] == 'pin':
                    at = sexp.find(y, 'at')
                    out[sexp.unq(sexp.find(y, 'number')[1])] = (float(at[1]), float(at[2]), int(float(at[3])))
                else:
                    walk(y)
    walk(sym)
    return out
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

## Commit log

2026-09-27 Focus repository on R2 hardware, code, and documentation
    [CPU.kicad_sch, Clock_Reset.sch, Cpu_Ram_Rom.sch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]
2026-09-27 Simplify THT repository layout and documentation
    [CPU.kicad_sch, DUART.kicad_sch, Expansion.kicad_sch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]
2026-09-30 SolderDemon m68k r2.42: CPLD board, rebranding and silkscreen cleanup
    Rename the KiCad project to solderdemon_m68k and move the glue logic
    to two ATF1502AS CPLDs, with generator/routing scripts in design/tools.
    Remove the upstream silkscreen badges (WEEE bin, OSHW certification
    block, rosco_m68k logos, GitHub URL next to the expansion connector)
    and bump the copyright to 2019-2026 via design/tools/strip_silk.py.
    [CPU.kicad_sch, DUART.kicad_sch, Expansion.kicad_sch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]
2026-09-30 SolderDemon m68k r1: DUART in the CPLD column, own identity
    Start SolderDemon's own revision numbering at r1. The board is 5 mm
    longer (165 x 100 mm) so the DUART IC4 stands in one column with the
    CPLDs IC3 and IC2: r1_layout.py stretches the r2.42 board along a cut
    between the CPLDs and the CPU/RAM, bridging the crossing tracks, then
    moves IC4 and reroutes it with KiCadRoutingTools.
    The CPU decoupling C20/C12/C29/C31 stands in an even column in the
    gap that opened, and the back carries the SolderDemon identity as on
    the busboard (logo, name, "M68K Computer r1"). Silkscreen text moves
    off the missing Futura font. trim_stubs.py cuts router overshoots
    back to their junctions; cpld_route.py no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
    [CPU.kicad_sch, DUART.kicad_sch, Expansion.kicad_sch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]

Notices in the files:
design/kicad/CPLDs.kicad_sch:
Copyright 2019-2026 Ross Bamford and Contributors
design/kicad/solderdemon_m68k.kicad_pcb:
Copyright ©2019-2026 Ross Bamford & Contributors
